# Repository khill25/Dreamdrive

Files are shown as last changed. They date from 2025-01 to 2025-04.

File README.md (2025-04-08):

# Dreamdrive
Retro gaming accessories produced by Dreamcraft Industries. Dreamdrive is coming to disc based systems called Dreamdisc! Dreamcast is the first console to get this treatment. Work is in progress to finalize the hardware and software for a first producion run. Stay tuned!

## [Discord](https://discord.gg/sHbhx2qJuK)
Join the discussion and get the latest on Dreamdrive status. Chat with other hackers. Have ideas on a new Dreamdrive product? Come and let me know. 

# Dreamdumper64
New Dreamdumper64 hardware files have been checked in! Navigate to `N64/hw/cart_tester/pc64` for the latest kicad project files.

# Projects
Current project status

| Project | Platform | Purpose  | Status | Notes |
| --- | --- | --- | --- | --- |
| Dreamdumper64 | N64 | Backup your cartridges | Finished | Completed units are available [here](https://dreamcraftindustries.com/products/dreamdumper64-assembled)!|
| Dreamdisc | Dreamcast | Dreamdive ODE For Dreamcast | Prototype/v3 | Repo files wont boot yet but the design has been verified and will be available soon |
| Dreamdrive Advance | GBA | Developer rom cart | Prototype/v2 | Waiting for new board designs with support for faster psram. Current PSRAM on the qspi bus isn't fast enough to service the cart |
| Super Dreamdrive | SNES | Developer rom cart | Prototype/v1 | Drafted prototype hardware and software. No idea if this is working |

### License
This project is licensed under the [Dreamdrive Open Hardware License v1.0](./LICENSE).  
You are free to learn from, modify, and remix this design for non-commercial purposes with attribution.  
Commercial use requires permission — reach out to kaili [at] dreamcraftindustries [dot] com.

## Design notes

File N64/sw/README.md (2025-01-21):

# Notes
Changes have been made to the pico-sdk to speed up copy to ram in order to meet the boot timing when powered on from the n64.
`crt0.S` should be copied to `pico-sdk/source/rp2_common/pico_standard_link/crt0.S` Remember to back up the original before making any changes.

To build and flash:

```bash

# First of all, don't forget to update submodules
git submodule update --init

# If you have more than 2MB flash, you need to change the SDK file src/rp2_common/pico_standard_link/memmap_copy_to_ram.ld (for now!):
# Change to: `FLASH(rx) : ORIGIN = 0x10000000, LENGTH = 16384k`

cd sw

# Load a rom into sw/picocart64/rom.h
# `--compress` will compress the rom with a simple compression scheme.
./scripts/load_rom.py --compress my_rom.z64

mkdir build
cd build

# Configure cmake. To use NTSC, set -DREGION=NTSC
# If you have more than 2MB flash, you need to change the flash size by adding -DFLASH_SIZE_MB={one of 2,4,8,16} here.

For European N64s
`cmake -DREGION=PAL ..`
    * If using a weact pico clone (e.g. purchased from dreamcraftindustries.com)
    `cmake -DREGION=PAL -DFLASH_SIZE_MB=16`

For North American N64s
`cmake -DREGION=NTSC ..`
    * If using a weact pico clone (e.g. purchased from dreamcraftindustries.com)
    `cmake -DREGION=NTSC -DFLASH_SIZE_MB=16`

# Build
make

# You can now flash it by holding down the BOOT button and resetting the device, then mounting the usb mass storage device, then copy the file picocart64/picocart64.uf2 to the mounted path and run `sync`.

# Alternatively, you can use openocd with a J-Link:

# Requires https://github.com/raspberrypi/openocd
# AUR package if you're on archlinux: https://aur.archlinux.org/packages/openocd-raspberrypi-git
openocd -f interface/jlink.cfg -c "transport select swd; adapter_khz 1000" -f target/rp2040.cfg -c "program ./picocart64/picocart64.elf verify reset exit"

# Note! You *have* to power reset the pico after flashing it with a jlink, otherwise multicore doesn't work properly.
# Alternatively, attach a debugger, `mon reset halt`, `c`, does the trick as well. It seems that openocd's `reset run` doesn't work properly.

```

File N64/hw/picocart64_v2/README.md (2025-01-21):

# PicoCart64 v2.2

:exclamation: Latest 2.2 board revisions have been ordered for testing, so build at your own risk :exclamation:

## Errata

### v2.0
- Less than ideal VBus' routing on Inner Layer 1. The power routing should work and passes DRC, but could be better.

## Changelog

### v2.2
- Improved routing
- Removed mcu1 USB-C port
- CS line of all chips in PSRAM array are routed through the demux
- Removed play area
- Added reset button pads connected to mcu2 reset pins for easy reset

### v2.1-unreleased
- Improved power routing for VBus'

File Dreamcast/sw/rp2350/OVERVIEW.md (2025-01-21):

MCU1 -
D0-D15 = gpio 0-15
SDCLK = 16
SDCMD = 17
SD_D0 = 18
SD_D1 = 19
SD_D2 = 20
SD_D3 = 21
PIO_COMMS_CTRL1 = 22
PIO_COMMS_CTRL2 = 24
PIO_COMMS_D0 = 26
PIO_COMMS_D1 = 27
PIO_COMMS_D2 = 28
PIO_COMMS_D3 = 29

MCU2 -
A0-A2 = gpio 0-2
IDE_CS0 = 3
IDE_CS1 = 4
RD = 5
WR = 6
IORDY = 7
INTRQ = 8
CDLRCK = 9
CD_CLK = 10
CD_EMPH = 11
DMARQ = 12
DMACK = 13
CD_SDAT = 14
CD_BCK = 15
UART_TX = 16
UART_RX = 17
(18,19,20,21) = free
PIO_COMMS_CTRL1 = 22
PIO_COMMS_CTRL2 = 24
PIO_COMMS_D0 = 26
PIO_COMMS_D1 = 27
PIO_COMMS_D2 = 28
PIO_COMMS_D3 = 29

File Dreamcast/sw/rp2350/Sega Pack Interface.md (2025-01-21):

# Sega Packet Interface 
Repackaged and in some places condensed, version of the `GD-ROM Protocol SPI Specifications` document.
## Signal lines

| Line  |   Name    | Description |
--------|-----------|-------------|
| CS0 |   chip select 0   |   serves for selecting the command block register. Aka 'CS1FX' |
CS1 |   chip select 1   |   serves for selecting the control block register. Aka 'CS3FX'
DA2, DA1, DA0   |   Device address  |   specifies the register and data read/write port
DASP    |   Device active, device 1 present |   Time multiplexed singla which indicates whether the device is active and whether device 1 is present. The signal in this line is an open collector signal. However, the signal cannot be used by the host.
DD0-DD15    |   Device data |   Bidirectional data bus, either 8-bit or 16-bit bus. The 8-bit LSB is used for 8-bit transfer (register etc.)
DIOR    |   Device I/O read |   Read strobe signal from the host. At the falling edge of this signal, the data on the DD0-DD7, DD8-DD15 data bus from the device register or data port become valid. At the rising edge of this signal, the host latches on to the data. Until latching is completed, the host cannot access the data.
DIOW    |   Device I/O write    |   Write strobe signal from the host. At the falling edge of this signal, the data on the DD0- DD7, DD8-DD15 data bus from the device register or data port are latched. Until latching is completed, the device cannot access the data.
DMACK   |   DMA acknowledge (optional)  |   This signal is used by the host in response to DMARQ, for initiating a DMA transfer.
DMARQ   |   DMA request (optional)  |   This signal is used for DMA transfer between the host and this device. When data transfer is possible, the device drives the signal. The data transfer direction is controlled by the DIOR- and DIOW- commands. This signal is used in handshaking with the DMACK- signal. When no device is selected and when no DMA commands are being executed, the signal line is always in the high- impedance (release) state. When DMA transfer is being carried out, the signal is driven by the device.
INTRQ   |   Device interrupt    |   Serves for issuing an interrupt to the host. The INTRQ signal has a hold function which asserts the interrupt only when the device is selected and the host has cleared the nIEN bit in the device control register. When the nIEN bit is "1", or when the device is not selected, the INTRQ signal is in the high-impedance state, regardless of the presence of the hold interrupt. In the interrupt hold state, the following OR conditions are cleared. <ul><li>RESET signal assertion</li><li>Device control register SRSRT bit reset</li><li>When host has written to command register</li><li>When host has read from command register</li></ul> For PIO transfer, the INTRQ signal is asserted at the start of each transferred data. The data block is normally a single sector, unless declared otherwise by a separate method. For DMA transfer, the INTRQ signal is asserted only once, after the command has terminated.
IOCS16  |   Device 16-bit I/O   |   For PIO transfer in mode 0, 1, or 2, the IOCS16- signal indicates that the 16-bit data port is already addressed and that the device can send and receive 16-bit data. This is an open collector output.<ul><li>In any PIO mode, the device supports only 16-bit data transfer. Therefore the IOCS16- signal is always asserted.</li><li>During DMA mode transfer, the host uses the 16-bit DMA channel and the IOCS16- signal is not asserted.</li></ul> However, the signal cannot be used by the host.
IORDY   |   I/O channel ready   | When the device cannot comply with a data transfer request, the signal is negated in order to expand the register access host transfer cycles. <ul><li>When this signal is driven, it is valid only during the DIOR/DIOW cycle for the selected device.</li><li> When the IORDY signal is not negated, it is in the high-impedance state, because it is an open collector signal.</li></ul>
RESET   |   Device reset    |   This signal is issued by the host. It is asserted at the start of power-on, and the assert state is maintained until the power supply level has stabilized. This is a tolerance interval until device reset after power-on
MCK |   Main clock  |    33.8688 MHz clock signal for AICA use.
BCLK    |   Bit clock   |   Clock signal for fetching Digital Audio.
LRCK    |   Left right clock    |   Digital Audio left/right discriminat signal.
SDTATA  |   Serial Data |   Digital Audio data
EMPH    |   Emphasis    |   <ul><li>A High output signal is obtainable if preemphasis is applied to Digital Audio during playback or scan playback. Should there be irregularities in the subcode Q data during playback, the value of the previous time is retained and output. </li><li>Low is output when power is turned ON, when reset, when playback is stopped, when the lid is open and when no disc is inserted.</li></ul>
---

## Command Transfer Mechanism
### Reset Conditons
These are listed in priority order. With **Power-on Reset** being higher than **SPI Soft Reset**, etc... **ATA SRST** has priority over all other states except these.
* **Power-on reset or hardware reset**
    * In the same way as executing the master/slave diagnosis protocol, the electrical circuit diagnosis is executed and the default values are established.
    1) All currently executing commands and I/O operations are cleared.
    2) The device is reset to default condition.
    3) As after normal power-on reset, the operation mode of the device returns to a suitable initial state.
    4) The task file register is initialized:
        * `Status   = 0x00`
        * `Error = 0x10`
        * `Sector Count = 0x01`
        * `Sector Number = 0x01`
        * `Cylinder Low = 0x14`
        * `Cylinder High = 0xEB`
        * `Drive/Head = 0x00`
        * `BSY = 0` following after any reset indicates that the task file register is already initalized for the host.
* **SPI Soft Reset**
    * When the SPI device receives a SPI Soft Reset command, the interface circuit is reset to an interface that operates with the characteristics requested by Set Features.
    * Must be able to return the MCU from a busy or hung-up state so commands can be performed.
    * Can be issued when the `BSY` bit is 1
    1) The BUSY state is set. When the reset sequence in the device is completed, the BUSY state is also cleared. This is the only status that is reported to the host during an SPI Software Reset.
    2) The same information sequence as after power-on reset is performed and the task file is initialized. As an exception, the DRV bit remains unchanged.
* **ATA SRST**
    * The device normally supplies the ATA PDIAG/DASP sequence and executes the task file associated with the command when SRST is detected. This does not cause an actual device reset. There are no startup, abort, or stop commands.

### ATA I/O Register
* Communication between the device and the host occurs via the I/O register selected by the code data on the signal from the host (`CS0`, `CS1`, `DA2`, `DA1`, `DA0`, `DIOR`, `DIOW`)
* Except for the data register, all registers are read/written in 8-bits (byte units)
* The data register is always accessed in 16-bit words.

#### Function Select Table
This table represents which registers are read or written based on the CS, Address, and Read/Write lines. Data is valid on falling edge of `READ`/`WRITE`. There is 100-300ns of time to sample the pins before the data becomes valid on the next rising edge.

|CS0|CS1| A2 | A1 | A0 | READ | WRITE |
---|---|---|---|---|---|---|
1|0|1|1|0|`Alternate Status Register`|`Device Control Register`|
0|1|0|0|0|`Data Register`| `Data Register`|
0|1|0|0|1|`Error Register`|`Features Register`|
0|1|0|1|0|`Interrupt Reason Register`|!!NOT USED!!|
0|1|0|1|1|`Sector Number Register`|!!NOTE USED!!|
0|1|1|0|0|`Byte Count Register (0-7)`|`Byte Count Register (0-7)`|
0|1|1|0|1|`Byte Count Register (8-15)`|`Byte Count Register (8-15)`|
0|1|1|1|0|`Drive Select Register`|`Drive Select Register`|
0|1|1|1|1|`Status Register`|`Command Register`|
1|1|x|x|x|INVALID ADDRESS|INVALID ADDRESS|

** ~~There seems to be an error in the GM-ROM Protocol SPI Specifications PDF I was reading to create this doc. I have fixed this table with information based on findings from a logic analyzer and analyzing the iceGDROM verilog.It ~~

*** It isn't wrong, it's just that the CS, Read, and Write lines are all active LOW

****These pins are also know as: `CS1` = CS3FX, `CS0` = CS1FX, `READ` = DIOR, `WRITE` = DIOW

---

#### Status Register
<ul>

| 7 | 6 | 5 | 4 | 3 | 2 | 1 | 0 |
---|---|---|---|---|---|---|---|
BSY | DRDY | DF | DSC | DRQ | CORR | Reserved | CHECK |

<li>
This register indicates the drive status. When the register is read, any pending interrupt signal is cleared. 
</li>
<li>
When bit 7 (BSY) is "0", the other bits are also valid and the command block can be accessed. 
</li>
<li>
When the bit is "1", the other bits are invalid and the command block cannot be accessed. However, in the case of special commands (NOP, Soft Reset command, etc.) access to the command block is enabled even when this bit is "1".
</li>
<li>
Bit 7 (BSY) becomes valid 400 ns after a command is received.
</li>
</ul>

* Bit 7: `BSY` is always set to 1 when the drive accessess the command block.
* Bit 6: `DRDY` set to 1 when the drive is able to respond to an ATA command.
* Bit 5: `DF` Returns drive fault information.
* Bit 4: `DSC` Becomes 1 when seek processing is complete.
* Bit 3: `DRQ` Becomes 1 when preparations for data transfer between drive and host are completed. 
    * Information held in the Interrupt Reason Register becomes valid in the packet command when DRQ is set.
* Bit 2: `CORR` Indicates a correctable error has occured.
* Bit 1: RESERVED
* Bit 0: `CHECK` Becomes 1 when an error has occured during execution of the command the previous time. 
    * Error detauls can be determined by checking the sense key and error code.

---
#### Alternate Status Register
* This register is the same as the status register, but it does not clear DMA status information when it is accessed.

| 7 | 6 | 5 | 4 | 3 | 2 | 1 | 0 |
---|---|---|---|---|---|---|---|
BSY | DRDY | DF | DSC | DRQ | CORR | Reserved | CHECK |

#### Command Register
Commands from the host are set in this register. For information on the meaning of commands, refer to the Table 3.3. TODO - fill out relevant info from referenced table in this section

#### Byte Count Register
* This register serves for controlling the number of bytes sent from the host in response to the DRQ commands.
* It is used only in PIO mode. 
* In DMA mode, the Byte Count Register contents are disregarded. 
* The register is set before a packet command is issued. The register determines the total transfer amount of the data sent in response to one data group transfer command (REC_MODE/SET_MODE, REQ_STAT, etc.).
* For commands which require several DRQ interrupts (CD_READ, CD_READ2, etc.), the expected data length is set in this register.
* When any data are to be transferred, the device sets the number of bytes to be transferred by the host in the Byte Count Register and then issues the DRQ interrupt. 
* The contents of the register do not change unless at least one word or more is transferred from the data register.

---
#### Data Register
* This register is used for reading and writing during data transfer with the host. 
* The register is switchable between 8 and 16 bits. 
* Only 16-bit mode is supported because the host is not using the IOCS-16 signal.

---
#### Device Control Register
Bit 2 (SRST) of this register is the reset switch from the host, but it is not used in the current protocol. When wishing to perform a software reset, use the "Software Reset" command as defined in the SPI protocol. Bit 1 (nIEN) determines whether the host interrupt is made valid or not.

| 7 | 6 | 5 | 4 | 3 | 2 | 1 | 0 |
---|---|---|---|---|---|---|---|
Reserved | | | | 1 | SRST | nIEN | 0 |

* Bit 2 `SRST` Software reset from host. 
    * Default is 0
    * Reset is performed when set to "1"
    * NOTE: because this is not used in this protocol use the "SPI Software Reset" command defined in SPI for performing a software reset
* Bit 1 `nIEN` Sets the interrupt for the host.
    * Default is 0
    * Invalid can be selected by setting this to 1

---
#### Drive Select Register (ATA Drive/Head select register)
| 7 | 6 | 5 | 4 | 3 | 2 | 1 | 0 |
---|---|---|---|---|---|---|---|
1 | Reserved | 1 | 0 | LUN | | | |

* Bit 0-3 `LUN` Logical unit number to which the command is applied
* This parameter is optional and reserved for future use ( lol :joy: )
---

#### Error Register
* The completion status of the most recent command is set in this register, also at the end of hard disk diagnosis. 
* When the status register bit 0 is "1", an error has occurred, and the error content is set in this register.

| 7 | 6 | 5 | 4 | 3 | 2 | 1 | 0 |
---|---|---|---|---|---|---|---|
Sense Key |  |  |  | MCR | ABRT | EMOF | ILI |

* Bits 7-4 `Sense Key`
    * `Sense Key` is only reflected in the SPI Command Mode. Same is true for Additional Sense Code (`ASC`) and Additional Sense Code Qualifier (`ASCQ`)
* Bit 3 `MCR` Media change was requested and media have been ejected (ATA level)
* Bit 2 `ABRT` Drive is not ready and command was made invalid (ATA level)
* Bit 1 `EOM` Media end was detected (option) (is option, optional?)
* Bit 0 `ILI` Command length is not correct (option)
---

#### Features Register
This register normally specifies the data transfer mode, but it can also be used for Set Features parameters of the ATA command. When issuing commands accompanied by data transfer, such as CD_READ, specify in this register whether data should be transferred by PIO or DMA at the time of task file initialization.

**Normal use (specify data transfer mode)**
| 7 | 6 | 5 | 4 | 3 | 2 | 1 | 0 |
---|---|---|---|---|---|---|---|
Reserve |  |  |  |  |  |  | DMA |

* Bit 0 `DMA` Send data for command in DMA mode

**Use as parameter for Set Features command** 
| 7 | 6 | 5 | 4 | 3 | 2 | 1 | 0 |
---|---|---|---|---|---|---|---|
Set(1), Clear(0), Feature | Feature Number | | | |  |  | |
* Bit 6-0 `Feature Number` Set transfer mode by setting to `3`
    * By writing `3` as `Feature Number` and issuing the `Set Feature` command, the PIO or DMA transfer mode set in the `Sector Count` register can be selected.
    * The actual transfer mode is specified by the `Sector Count Register`

---
#### Interrupt Reason Register (Read Only)
| 7 | 6 | 5 | 4 | 3 | 2 | 1 | 0 |
---|---|---|---|---|---|---|---|
Reserved | | | | |  | IO | CoD |
* Bit 0 `COD` (Command or Data)
    * 0 indicates data
    * 1 indicates command

| IO    |   DRQ |   CoD | Function
---|---|---|---|
0   |   1   |   1   | Command packet can be received
1   |   1   |   1   | Message can be sent from device to host
1   |   1   |   0   | Data can be sent to host
0   |   1   |   0   | Data can be received from host
1   |   0   |   1   | Status register contains completion status

---
#### Sector Count Register (Write Only)
* This register is used in combination with the ATA command's `Set Features` command

| 7 | 6 | 5 | 4 | 3 | 2 | 1 | 0 |
---|---|---|---|---|---|---|---|
Transfer Mode | | | | Mode Value | | | |

| Value | Transfer Mode |
---|---|
00000 00x | PIO Default Transfer Mode
00001 xxx | PIO Flow Control Transfer Mode x
00010 xxx | Single Word DMA mode x 
00100 xxx | Multi-Word DMA
00011 xxx | Reserved (For Pseudo DMA mode)

---
#### Sector Number Register (ATA Sector Number Register)
| 7 | 6 | 5 | 4 | 3 | 2 | 1 | 0 |
---|---|---|---|---|---|---|---|
Disc Format | | | | Status | | | |

The information obtained by this register is the same as the status data obtained with the REQ_STAT command.

* `Disc Format` becomes valid after the lid is closed and the `UNIT ATTENTION` state is entered via the `NOT READY` state, or after the `BSY` bit becomes "0" following Soft Reset.
* `Status` becomes valid after the power is turned ON and the `UNIT ATTENTION` state is entered via the `NOT READY` state, or after the `BSY` bit becomes "0" following Soft Reset.
* The values of this register are invalid during issue of a command and during execution of a command.
* The modification timing of this register and the status modification timing caused by `REQ_STAT` coincide internally but depending on the timing of the read out of the `Sector Number Register` and the issue of the `REQ_STAT` command there may be times where they do not coincide.
* This register is updated unsyncronized with the host. For this reason, it may return unfixed value if it is read at the timing of updating GD drive side. To avoid this, either read it again to confirm value or use `REQ_STAT` command instead of this register.
    * TODO: Refernce section of manual to build useful table... For details on the `Disc Format` and `Status`, refer to the sections on GD Drive State Transition and `REQ_STAT`.
* Operation of this register differs from ATA specifications.

### Sense Key Definitions
| Sense key | Description |
|---|---|
`0x00` | No sense key information (`NO SENSE`). Indicates that no sense key information is present. This also applies when command execution was successful.
`0x01` | Recovered error (`RECOVERED ERROR`). The last command has performed successful error recovery processing. Details can be obtained by checking the additional sense byte and the information field. If several error processing operations were performed for one command, the device reports the status of the last error processing operation.
`0x02` | Not ready (`NOT READY`). Indicates that the device cannot be accessed.
`0x03` | Media error (`MEDIUM ERROR`). Indicates that the command was terminated unsuccessfully due to a non-recoverable media defect or an error during reading or writing. This sense key may also returned by the device when it is not possible to distinguish between a media defect and a hardware defect (sense key 4).
`0x04` | Hardware error (`HARDWARE ERROR`). During operation or self- diagnosis, an unrecoverable hardware error was detected (for example a controller failure, device failure, parity error etc.).
`0x05` | Illegal request (`ILLEGAL REQUEST`). An illegal parameter was included in the command packet or in additional data for commands. When the device detects an illegal parameter in a command packet, it terminates the command without changing the media. When the device detects an illegal parameter in additional data for commands, the device may already have altered the media. When this sense key is reported, the command is not yet executed.
`0x06` | Unit attention (`UNIT ATTENTION`). Indicates that removable media may have been replaced, or that the device was reset.
`0x07` | Data protect (`DATA PROTECT`). Indicates that a write attempt was made on a protected block.
`0x08`-`0x0A` | Reserved
`0x0B` | Aborted command (`ABORTED COMMAND`). Indicates that the device has aborted the command. Recovery may be possible by re-executing the command.
`0x0C`-`0x0F` | Reserved
---

## ATA Command Flow
#### Command for PIO data transfer to host
* Applies to `Identify Device` command
* Command is accompanied by transfer of one or multiple data blocks from the device to the host

1) Host waits for `BSY` bit to become `0` in `Status Register` or `Alternate Status Register`
2) Host writes params for the command to relevant registers:
    * `Features Register`, `Sector Count Register`, `Sector Number Register`, `Cylinder High Register`, `Cylinder Low Register`, `Device/Head Register`
3) Host writes the command code to the `Command Register`
4) Device sets `BSY` bit to `1` and prepares to send the first data block.
5) Device sets `DRQ` bit and asserts `INTRQ` when data block is ready
    * `DRQ` is optional for some error conditions
    * If an error occurs, the device sets the corresponding status and error bits
    * If `BSY` bit transitions are too fast, the host may not notice
6) Host reads and saves `Status Register` after detecting `INTRQ` or `BSY` bit becoming `0` in the `Alternate Status Register`
7) If the `DRQ` bit is set, host reads one data block from `Data Register`. 
    * Illegal transfer if an error occurs in the next ste (step 8)
8) After the `Status Register` is read out 
    * Device negates `INTRQ`
    * Executes one of the following based on the status read-out:
        * If no errors and more blocks needed, set `BSY` bit and repeat step 7
        * If an error occurred during this step, clear `DRQ` bit and complete command execution
        * If the final block is transferred, clear `DRQ` bit and complete command execution

---

#### Non-data Command Flow
Applies to:
* `NOP`
* `Soft Reset`
* `Execute Device Diagnostic`
* `Set Features`
1) Host polls the `Status Register` or `Alternate Status Register` until `BSY` bit becomes `0`
2) Host writes params for the command to relevant registers
3) Host writes the command code to `Command Register`
4) Device sets `BSY` bit to `1` and executes command.
    * If an error occurs during execution the device sets an appropriate status and error bit
5) When command execution is complete device asserts `INTRQ` and clears the `BSY` bit.

---

#### ATA Command (Task File Command)
When a command is issued from the host, the device should:
* Load the command in a suitable register in the command block
* write the command code to the `Command Register`
* Device must set the `BSY` bit within 400ns.

|Command|Code|
|---|---|
|`Soft Reset`| `0x08`|
|`Execute Device Diagnostic`| `0x90`|
|`NOP`| `0x00`|
|`Packet Command`| `0xA0`|
|`Identify Device`| `0xA1`|
|`Set Features`| `0xEF`|

<ul>
<li><code>Soft Reset</code> Executes a software reset of the device. This command can also be received when `BSY` bit = `1`
</li>
<li><code>Execute Drive Diagnostic</code> Initiates self-diagnostic routine of the device.
    <ul>
        <li> Device reports the result of the self-diagnostic routine </li>
        <li> The device clears the `BSY` bit and issues an interrupt </li>
        <li> Error code is an 8-bit value written to the error register</li>
        <li>
        <table>
            <tbody>
                <tr>
                <th>Error Code</th>
                <th>Description</th>
                </tr>
                <tr>
                    <td><code>0x01</td>
                    <td>Normal</td>
                </tr>
                <tr>
                    <td><code>0x03</td>
                    <td>Data buffer error</td>
                </tr>
                <tr>
                    <td><code>0x04</td>
                    <td>ODC error</td>
                </tr>
                <tr>
                    <td><code>0x05</td>
                    <td>CPU error</td>
                </tr>
                <tr>
                    <td><code>0x06</td>
                    <td>DSC error</td>
                </tr>
                <tr>
                    <td><code>0x07</td>
                    <td>Other error</td>
                </tr>
                </tbody>
            </table>
        </li>
    </ul>
</ul>

* `Set Features`
    * For the GD-ROM, only the transfer mode settings are supported
    * This setting can be made individually for `DMA` mode and `PIO` mode
    1) Set `3` in the `Set` bit of the `Feature Register` and `Feature Number`
    2) In the `Sector Count Register`
        * Specify the transfer mode in the upper 5 bits 
        * Mode number in the lower 3 bits
    3) Execute the `Set Features` command

* `NOP`
    * Device status access for hosts with 16-bit registers (?? Does the Dreamcast support 16-bit registers ??)
    * Command can be received when `BSY` bit is `1` and device should terminate the command currently in execution
        * If the termination is performed correctly only the termination interrupt of this command is returned.
    * The device responds to commands that are not recognized by the following:
        * Setting "abort" in the error register
        * Setting an error in the status register
        * Clearing "busy" in the status register
        * Asserting the `INTRQ` signal

* `Packet Command`
    * TODO see SPI Packet Command section

* `Identify Device`
    * Always conducted in PIO Mode
    <ul>
    <li>
    <table>
        <tbody>
            <tr>
            <th>Byte</th>
            <th>Content</th>
            </tr>
            <tr>
                <td><code>0</td>
                <td>Manufacturer ID</td>
            </tr>
            <tr>
                <td><code>1</td>
                <td>Model ID</td>
            </tr>
            <tr>
                <td><code>2</td>
                <td>Version ID</td>
            </tr>
            <tr>
                <td><code>0x3-0xF</td>
                <td>Reserved</td>
            </tr>
            <tr>
                <td><code>0x10-0x1F</td>
                <td>Manufacturer name (16 ASCII characters)</td>
            </tr>
            <tr>
                <td><code>0x20-0x2F</td>
                <td>Model name (16 ASCII characters)</td>
            </tr>
            <tr>
                <td><code>0x30-0x3F</td>
                <td>Firmware version (16 ASCII characters)</td>
            </tr>
            <tr>
                <td><code>0x40-0x4F</td>
                <td>Reserved</td>
            </tr>
            </tbody>
        </table>
    </li>
    </ul>

---
### SPI Packet Commands
|Command|Function|OP Code|
---|---|---|
|`TEST_UNIT`|Verify access readiness|`0x00`|
|`REQ_STAT`|Get CD Status|`0x10`|
|`REQ_MODE`|Get various settings|`0x11`|
|`SET_MODE`|Make various settings|`0x12`|
|`REQ_ERROR`|Get error details|`0x13`|
|`GET_TOC`|Get all `TOC` data|`0x14`|
|`REQ_SES`|Get specified session data|`0x15`|
|`CD_OPEN`|Open tray|`0x16`|
|`CD_PLAY`|Play CD|`0x20`|
|`CD_SEEK`|Seek for playback position|`0x21`|
|`CD_SCAN`|Perform scan|`0x22`|
|`CD_READ`|Read CD|`0x30`|
|`CD_READ2`|CD read (pre-read position)|`0x31`|
|`GET_SCD`|Get subcode|`0x40`|

#### Command Packet Format
|Bit|7|6|5|4|3|2|1|0|
|---|---|---|---|---|---|---|---|---|
|Byte|||||||||
|0|Command Code||||||||
|1|Command parameter||||||||
|2|Command parameter||||||||
|3|Command parameter||||||||
|4|Command parameter||||||||
|5|Command parameter||||||||
|6|Command parameter||||||||
|7|Command parameter||||||||
|8|Command parameter||||||||
|9|Command parameter||||||||
|10|Command parameter||||||||
|11|Command parameter||||||||
* **Command code**
    * The codes allotted to the various commands required to control the devices
* **Command parameter**
    * `Transfer Length`
        * Data length to be transfer
        * Typically represents the block count
        * For some commands it represents the byte count
        * For commands with multiple byte transfers, the transfer length `0` indicates no transfer
    * `Allocation Length`
        * Max length of data that host can receive
        * `0` indicates no transfer
    * `Starting Address`
        * Position to start data transfer
        * Some cases it may indicate transfer starting address

----
#### SPI Command Flow Sequence

---
#### CD Drive

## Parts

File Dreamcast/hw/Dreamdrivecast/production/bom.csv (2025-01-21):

Designator | Footprint | Quantity | Value | LCSC Part #
C1, C13, C14, C15, C16, C17, C18, C19, C20, C21, C24, C4, C5, C6, C7, C8 | 0402 | 16 | 100n | C1525
C10, C22, C23, C9 | 0402 | 4 | 1u | C14445
C11, C12 | 0402 | 2 | 10u | C315248
C25, C26, C27, C28 | 0402 | 4 | 12p | C106201
CN1 | Molex_52602_0579 | 1 | Molex_52602_0579 | C588209
J3, J4 | USB_C_Receptacle_Palconn_UTC16-G | 2 | USB_C_Receptacle_USB2.0 | C2988369
J5 | microSD_HC_Molex_104031-0811 | 1 | Micro_SD_Card | C585350
MCU1 Boot_2, MCU1 Boot, MCU2 Reset | SW_SPST_FSMSM | 3 | MCU1_BOOT | C520860
MCU2 Boot | SW_SPST_FSMSM | 1 | MCU2_BOOT | C520860
R10, R2, R3, R9 | 0402 | 4 | 27.4 | C284479
R11, R12, R4, R5 | 0402 | 4 | 5k1 | C25905
R13, R8 | 0402 | 2 | 100k | C60491
R14, R6 | 0402 | 2 | 10k | C60490
R15, R7 | 0402 | 2 | 1k | C25543
U1 | WQFN-42-1EP_3.5x9mm_P0.5mm_EP2.05x7.55mm | 1 | TS3L501ERUA | C2652454
U2, U5 | QFN-56-1EP_7x7mm_P0.4mm_EP3.2x3.2mm | 2 | RP2040 | C2040
U3 | SOT-223 | 1 | AZ1117-3.3 | C110474
U4, U6 | SOIC-8_5.23x5.23mm_P1.27mm | 2 | W25Q128JVS | C97521
Y1, Y2 | Crystal_SMD_2520-4Pin_2.5x2.0mm | 2 | 12MHz 10ppm | C521567

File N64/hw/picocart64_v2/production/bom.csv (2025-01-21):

Designator | Footprint | Quantity | Value | LCSC Part #
C37 | C_0402_1005Metric | 1 | 100n | C147639
C40 | C_0402_1005Metric | 1 | 1u
R62 | R_0402_1005Metric | 1 | 10K
R33 | R_0402_1005Metric | 1 | 10K
C4 | C_0402_1005Metric | 1 | 100n | C147639
R45 | R_0402_1005Metric | 1 | R | C105637
C3 | C_0402_1005Metric | 1 | 100n
TP1 | TestPoint_Pad_D1.0mm | 1 | TP_MCU2_SCK
R29 | R_0402_1005Metric | 1 | 22R
U7 | SOP-8_3.76x4.96mm_P1.27mm | 1 | APS6404L-3SQR
C5 | C_0402_1005Metric | 1 | 100n
R42 | R_0402_1005Metric | 1 | R | C105637
C32 | C_0402_1005Metric | 1 | 100n | C147639
R17 | R_0402_1005Metric | 1 | 5k1
C16 | C_0402_1005Metric | 1 | 100n | C147639
C28 | C_0402_1005Metric | 1 | 12p
R21 | R_0402_1005Metric | 1 | 22R
C39 | C_0402_1005Metric | 1 | 1u
R37 | R_0402_1005Metric | 1 | 10k
U8 | SOP-8_3.76x4.96mm_P1.27mm | 1 | APS6404L-3SQR
TP2 | TestPoint_Pad_D1.0mm | 1 | TP_MCU2_CS
R24 | R_0402_1005Metric | 1 | 22R
C19 | C_0402_1005Metric | 1 | 100n | C147639
C8 | C_0402_1005Metric | 1 | 100n | C147639
R43 | R_0402_1005Metric | 1 | R | C105637
U1 | SOP-8_3.76x4.96mm_P1.27mm | 1 | APS6404L-3SQR
C54 | C_0402_1005Metric | 1 | 100n | C147639
C10 | C_0603_1608Metric | 1 | 10u
C12 | C_0402_1005Metric | 1 | 12p
D1 | WS2812B-2020 | 1 | WS2812B-2020
U16 | QFN-56_EP_7x7_Pitch0.4mm | 1 | RP2040
JP2 | SolderJumper-2_Small_Closed | 1 | SolderJumper_2_Bridged
C36 | C_0402_1005Metric | 1 | 100n | C147639
R30 | R_0402_1005Metric | 1 | 22R
R54 | R_0402_1005Metric | 1 | R | C105637
U15 | QFN-56_EP_7x7_Pitch0.4mm | 1 | RP2040
C47 | C_0402_1005Metric | 1 | 1u
Y2 | Crystal_SMD_2520-4Pin_2.5x2.0mm | 1 | 12MHz 10ppm | C521567
FB1 | L_0603_1608Metric | 1 | Ferrite
R48 | R_0402_1005Metric | 1 | R | C105637
C38 | C_0402_1005Metric | 1 | 1u
Y1 | Crystal_SMD_2520-4Pin_2.5x2.0mm | 1 | 12MHz 10ppm | C521567
R20 | R_0402_1005Metric | 1 | 22R
U6 | SOP-8_3.76x4.96mm_P1.27mm | 1 | APS6404L-3SQR
U5 | SOP-8_3.76x4.96mm_P1.27mm | 1 | APS6404L-3SQR
R50 | R_0402_1005Metric | 1 | R | C105637
R56 | R_0402_1005Metric | 1 | R | C105637
R2 | R_0402_1005Metric | 1 | 10K
R26 | R_0402_1005Metric | 1 | 22R
J1 | USB_C_Receptacle_GT-USB-7010 | 1 | USB_C_Receptacle_USB2.0
C31 | C_0402_1005Metric | 1 | 100n | C147639
C2 | C_0402_1005Metric | 1 | 100n | C147639
U2 | SOP-8_3.76x4.96mm_P1.27mm | 1 | APS6404L-3SQR
C30 | C_0402_1005Metric | 1 | 100n | C147639
U9 | SOP-16_4.4x10.4mm_P1.27mm | 1 | SN74LVC138AQDRQ1
SW1 | SW_SPST_FSMSM | 1 | BootButton
R41 | R_0402_1005Metric | 1 | 10k
U10 | SOIC-8_5.23x5.23mm_P1.27mm | 1 | W25Q128JVS
R31 | R_0402_1005Metric | 1 | 22R
C9 | C_0402_1005Metric | 1 | 100n | C147639
R10 | R_0402_1005Metric | 1 | 22R
C52 | C_0402_1005Metric | 1 | 100n | C147639
C11 | C_0402_1005Metric | 1 | 12p
J3 | microSD_HC_Molex_104031-0811 | 1 | Micro_SD_Card_Det
U13 | SOT-223 | 1 | AZ1117-3.3
R59 | R_0402_1005Metric | 1 | R | C105637
R5 | R_0402_1005Metric | 1 | 22R
R53 | R_0402_1005Metric | 1 | R | C105637
R15 | R_0402_1005Metric | 1 | 22R
C44 | C_0402_1005Metric | 1 | 1u
C7 | C_0402_1005Metric | 1 | 100n
C18 | C_0402_1005Metric | 1 | 100n | C147639
C24 | C_0402_1005Metric | 1 | 1u
Q2 | SOT-23 | 1 | FDN340P | C347510
R12 | R_0402_1005Metric | 1 | 22R
C41 | C_0402_1005Metric | 1 | 1u
R19 | R_0402_1005Metric | 1 | 10k
TP3 | TestPoint_Pad_D1.0mm | 1 | TP_MCU2_DIO
U11 | SOT-353_SC-70-5 | 1 | 74LVC1G125GW
R6 | R_0402_1005Metric | 1 | 22R
JP1 | SolderJumper-2_Small_Open | 1 | SolderJumper_2_Open
D2 | LED_WS2812B_PLCC4_5.0x5.0mm_P3.2mm | 1 | WS2812B | WS2812B-2020
R44 | R_0402_1005Metric | 1 | R | C105637
C50 | C_0402_1005Metric | 1 | 100n | C147639
C45 | C_0402_1005Metric | 1 | 1u
R25 | R_0402_1005Metric | 1 | 22R
Q1 | SOT-23 | 1 | FDN340P | C347510
R39 | R_0402_1005Metric | 1 | 1K
C57 | C_0402_1005Metric | 1 | 100n | C147639
U17 | ESP32-C3-WROOM-02 | 1 | ESP32-C3-WROOM-02
C51 | C_0402_1005Metric | 1 | 100n | C147639
R4 | R_0402_1005Metric | 1 | 22R
C20 | C_0402_1005Metric | 1 | 100n | C147639
C1 | C_0402_1005Metric | 1 | 100n | C147639
R27 | R_0402_1005Metric | 1 | 22R
C6 | C_0402_1005Metric | 1 | 100n | C147639
R1 | R_0402_1005Metric | 1 | 10K
R58 | R_0402_1005Metric | 1 | R | C105637
C42 | C_0402_1005Metric | 1 | 1u
C13 | C_0603_1608Metric | 1 | 10u
C49 | C_0402_1005Metric | 1 | 100n | C147639
C33 | C_0402_1005Metric | 1 | 100n | C147639
R18 | R_0402_1005Metric | 1 | 5k1
R36 | R_0402_1005Metric | 1 | 22R
C56 | C_0402_1005Metric | 1 | 100n | C147639
C27 | C_0402_1005Metric | 1 | 12p
R13 | R_0402_1005Metric | 1 | 22R
C26 | C_0402_1005Metric | 1 | 100n | C147639
R34 | R_0402_1005Metric | 1 | 10K
R3 | R_0402_1005Metric | 1 | 100k
D3 | SOT-143 | 1 | DRTR5V0U2SR-7 | C443828
R28 | R_0402_1005Metric | 1 | 22R
R47 | R_0402_1005Metric | 1 | R | C105637
C22 | C_0402_1005Metric | 1 | 100n | C147639
R46 | R_0402_1005Metric | 1 | R | C105637
R38 | R_0402_1005Metric | 1 | 10k
R52 | R_0402_1005Metric | 1 | R | C105637
R8 | R_0402_1005Metric | 1 | 22R
C21 | C_0402_1005Metric | 1 | 1u
D4 | D_SMA | 1 | D_Small | C22452
C43 | C_0402_1005Metric | 1 | 1u
U3 | SOP-8_3.76x4.96mm_P1.27mm | 1 | APS6404L-3SQR
C14 | C_0603_1608Metric | 1 | 10u
R51 | R_0402_1005Metric | 1 | R | C105637
R32 | R_0402_1005Metric | 1 | 22R
JP3 | SolderJumper-2_Small_Closed | 1 | SolderJumper_2_Bridged
R61 | R_0402_1005Metric | 1 | R | C105637
C29 | C_0402_1005Metric | 1 | 100n | C147639
R16 | R_0402_1005Metric | 1 | 22R
C35 | C_0402_1005Metric | 1 | 1u
C48 | C_0402_1005Metric | 1 | 100n | C147639
C34 | C_0402_1005Metric | 1 | 100n | C147639
C55 | C_0402_1005Metric | 1 | 100n | C147639
R7 | R_0402_1005Metric | 1 | 22R
C17 | C_0402_1005Metric | 1 | 100n | C147639
R9 | R_0402_1005Metric | 1 | 22R
R49 | R_0402_1005Metric | 1 | R | C105637
R57 | R_0402_1005Metric | 1 | R | C105637
U4 | SOP-8_3.76x4.96mm_P1.27mm | 1 | APS6404L-3SQR
C23 | C_0402_1005Metric | 1 | 100n | C147639
R35 | R_0402_1005Metric | 1 | 22R
R14 | R_0402_1005Metric | 1 | 22R
R60 | R_0402_1005Metric | 1 | R | C105637
R40 | R_0402_1005Metric | 1 | 470R
R22 | R_0402_1005Metric | 1 | 22R
C25 | C_0402_1005Metric | 1 | 1u
C46 | C_0402_1005Metric | 1 | 1u
C53 | C_0402_1005Metric | 1 | 100n | C147639
C15 | C_0402_1005Metric | 1 | 100n | C147639
R11 | R_0402_1005Metric | 1 | 22R
R55 | R_0402_1005Metric | 1 | R | C105637
R23 | R_0402_1005Metric | 1 | 22R
U14 | N64-Connector | 1 | N64-Cartridge
J2 | PinHeader_2x06_P2.54mm_Vertical_SMD | 1 | Conn_02x06_Odd_Even
SW2 | SW_SPST_FSMSM | 1 | ResetButton

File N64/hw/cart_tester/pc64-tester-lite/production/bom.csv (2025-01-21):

Designator | Footprint | Quantity | Value | LCSC Part #
CON3 | N64-CONN | 1 | N64-CONN
H1 | MountingHole_2.2mm_M2_DIN965_Pad_TopBottom | 1 | MountingHole_Pad
SWD1 | PinHeader_1x03_P2.54mm_Vertical | 1 | SWD
UART0 | PinHeader_1x02_P2.54mm_Vertical | 1 | UART0
H4 | MountingHole_2.2mm_M2_DIN965_Pad_TopBottom | 1 | MountingHole_Pad
RESET1 | SW_SPST_FSMSM | 1 | RESET
H3 | MountingHole_2.2mm_M2_DIN965_Pad_TopBottom | 1 | MountingHole_Pad
U1 | RPi_Pico_SMD_TH | 1 | Pico
H2 | MountingHole_2.2mm_M2_DIN965_Pad_TopBottom | 1 | MountingHole_Pad

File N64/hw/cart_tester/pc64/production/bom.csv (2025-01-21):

Designator | Footprint | Quantity | Value | LCSC Part #
C10, C11, C13, C14, C15, C16, C5, C6, C9 | 0402 | 9 | 100nF | C1525
C1001, C1002, C7, C8 | 0402 | 4 | 1uF | C52923
C3, C4 | 0402 | 2 | 30pF | C107004
CON2 | PinSocket_1x03_P2.54mm_Vertical | 1 | HDR1X3 | C146243
CON3 | PinSocket_1x03_P2.54mm_Vertical | 1 | HDR1X3
D1 | 0402 | 1 | PowerLED | C130724
F1 | 1206 | 1 | 1.1A | C2760273
H1, H2, H3, H4 | MountingHole_2.2mm_M2_ISO7380_Pad_TopBottom | 4 | MountingHole_Pad
J1 | HRO-TYPE-C-31-M-12_LCSC | 1 | USB_C_Receptacle_USB2.0 | C165948
J2 | BarrelJack_CUI_PJ-036AH-SMT_Horizontal | 1 | Barrel_Jack
R1, R2 | 0402 | 2 | 5k1 | C25905
R1001 | 0402 | 1 | 1K | C11702
R3, R4 | 0402 | 2 | 27 | C25100
R5 | 0402 | 1 | 35
RP_SW1, RP_SW2 | SW_SPST_TL3342 | 2 | SW_Push | C318884
U1001 | SOT-23-6 | 1 | SRV05-4 | C3021103
U1002 | SOT-223 | 1 | AMS1117-3.3 | C6186
U3 | SOIC-8_5.23x5.23mm_P1.27mm | 1 | W25Q128JVS | C97521
U4 | RP2040-QFN-56 | 1 | RP2040 | C2040
Y1 | Crystal_SMD_3225-4Pin_3.2x2.5mm | 1 | Crystal_GND24 | C9002

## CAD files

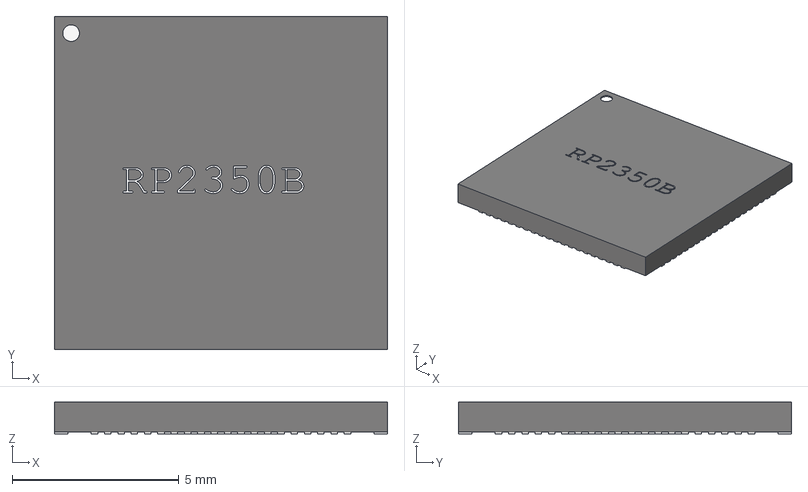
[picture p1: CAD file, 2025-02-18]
Dreamcast/hw/Dreamdrivecast-rp2350/Dreamdrivecast-rp2350/RP2350_QFN80.step
10.0 x 10.0 x 0.95 mm

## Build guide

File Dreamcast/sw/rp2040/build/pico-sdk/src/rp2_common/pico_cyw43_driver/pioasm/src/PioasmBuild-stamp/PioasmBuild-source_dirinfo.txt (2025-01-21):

# This is a generated file and its contents are an internal implementation detail.
# The download step will be re-executed if anything in this file changes.
# No other meaning or use of this file is supported.

method=source_dir
command=
source_dir=/Users/kaili/Code/pico-sdk/tools/pioasm
work_dir=

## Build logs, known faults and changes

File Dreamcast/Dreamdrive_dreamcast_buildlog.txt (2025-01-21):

Finding a copy of the "GD-ROM protocol SPI specification design" doc mentioned in the Dreamcast Hardware spec. I managed to track down a copy on archive.org.

I originally found just a text version on archive.org but was able to get the original PDF version, with tables intact. Was really difficult to figure out a protocol spec without columns and the data spaced all over.

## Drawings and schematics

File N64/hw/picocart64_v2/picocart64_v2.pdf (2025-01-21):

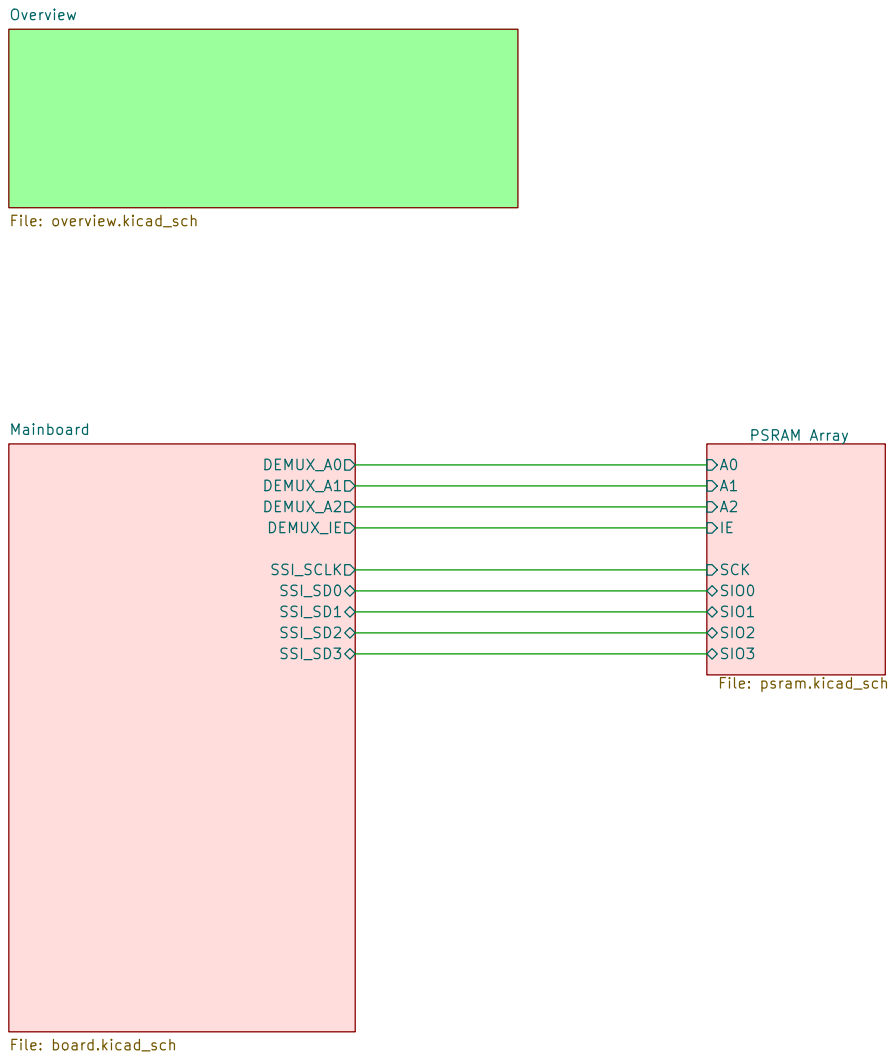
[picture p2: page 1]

File: picocart64_v2.kicad_sch Sheet: / Konrad Beckmann

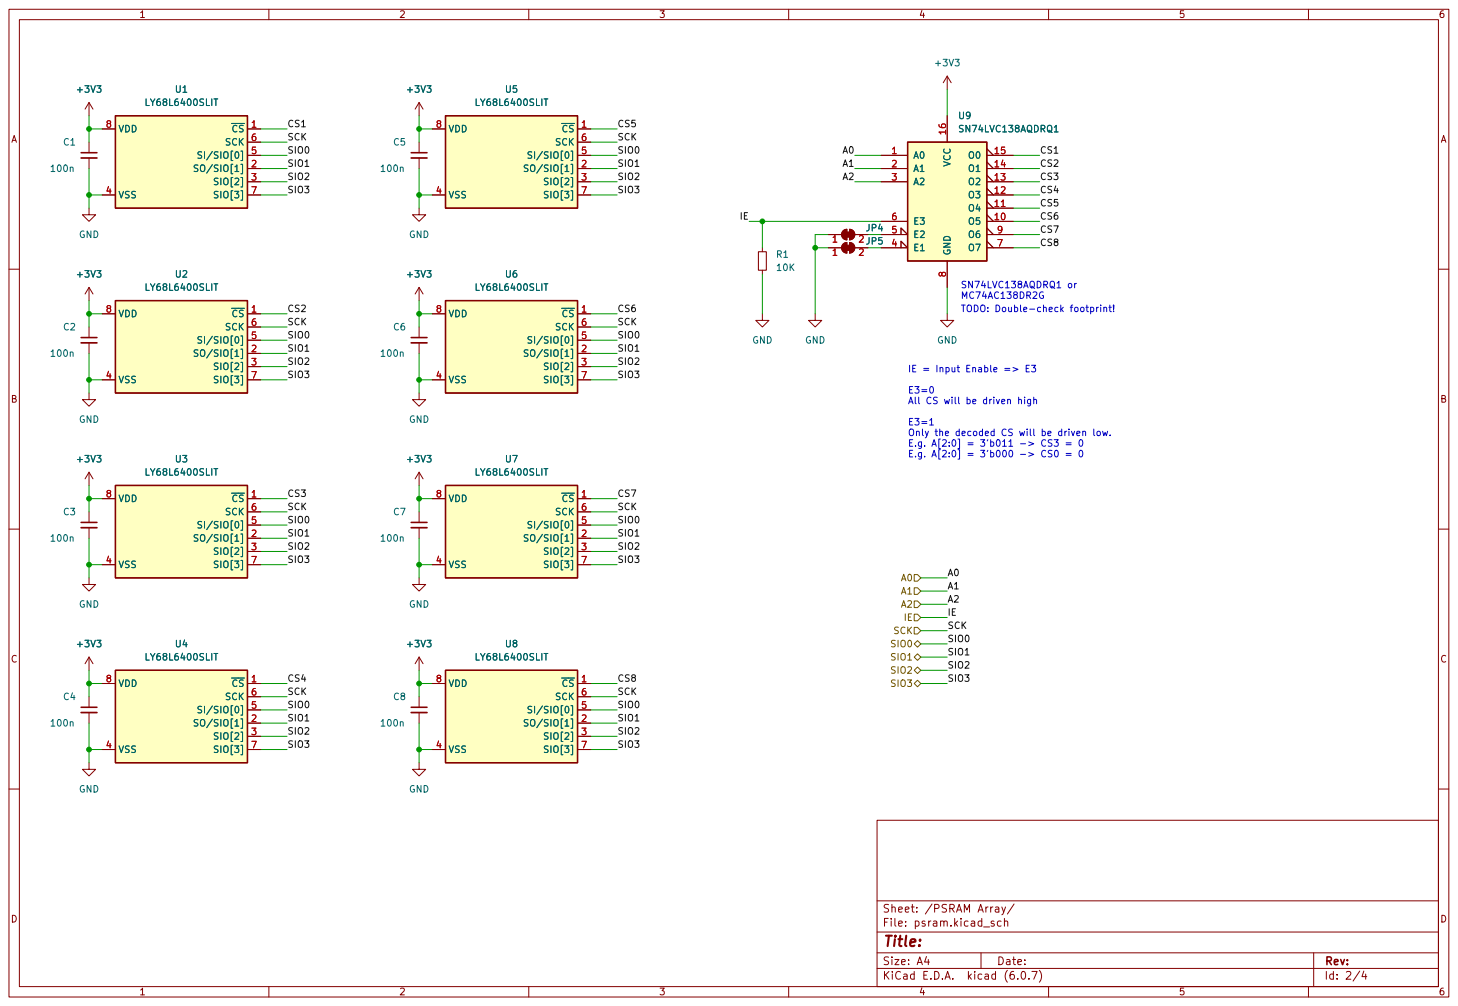
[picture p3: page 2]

IE = Input Enable => E3 E3=0 All CS will be driven high E3=1 Only the decoded CS will be driven low.

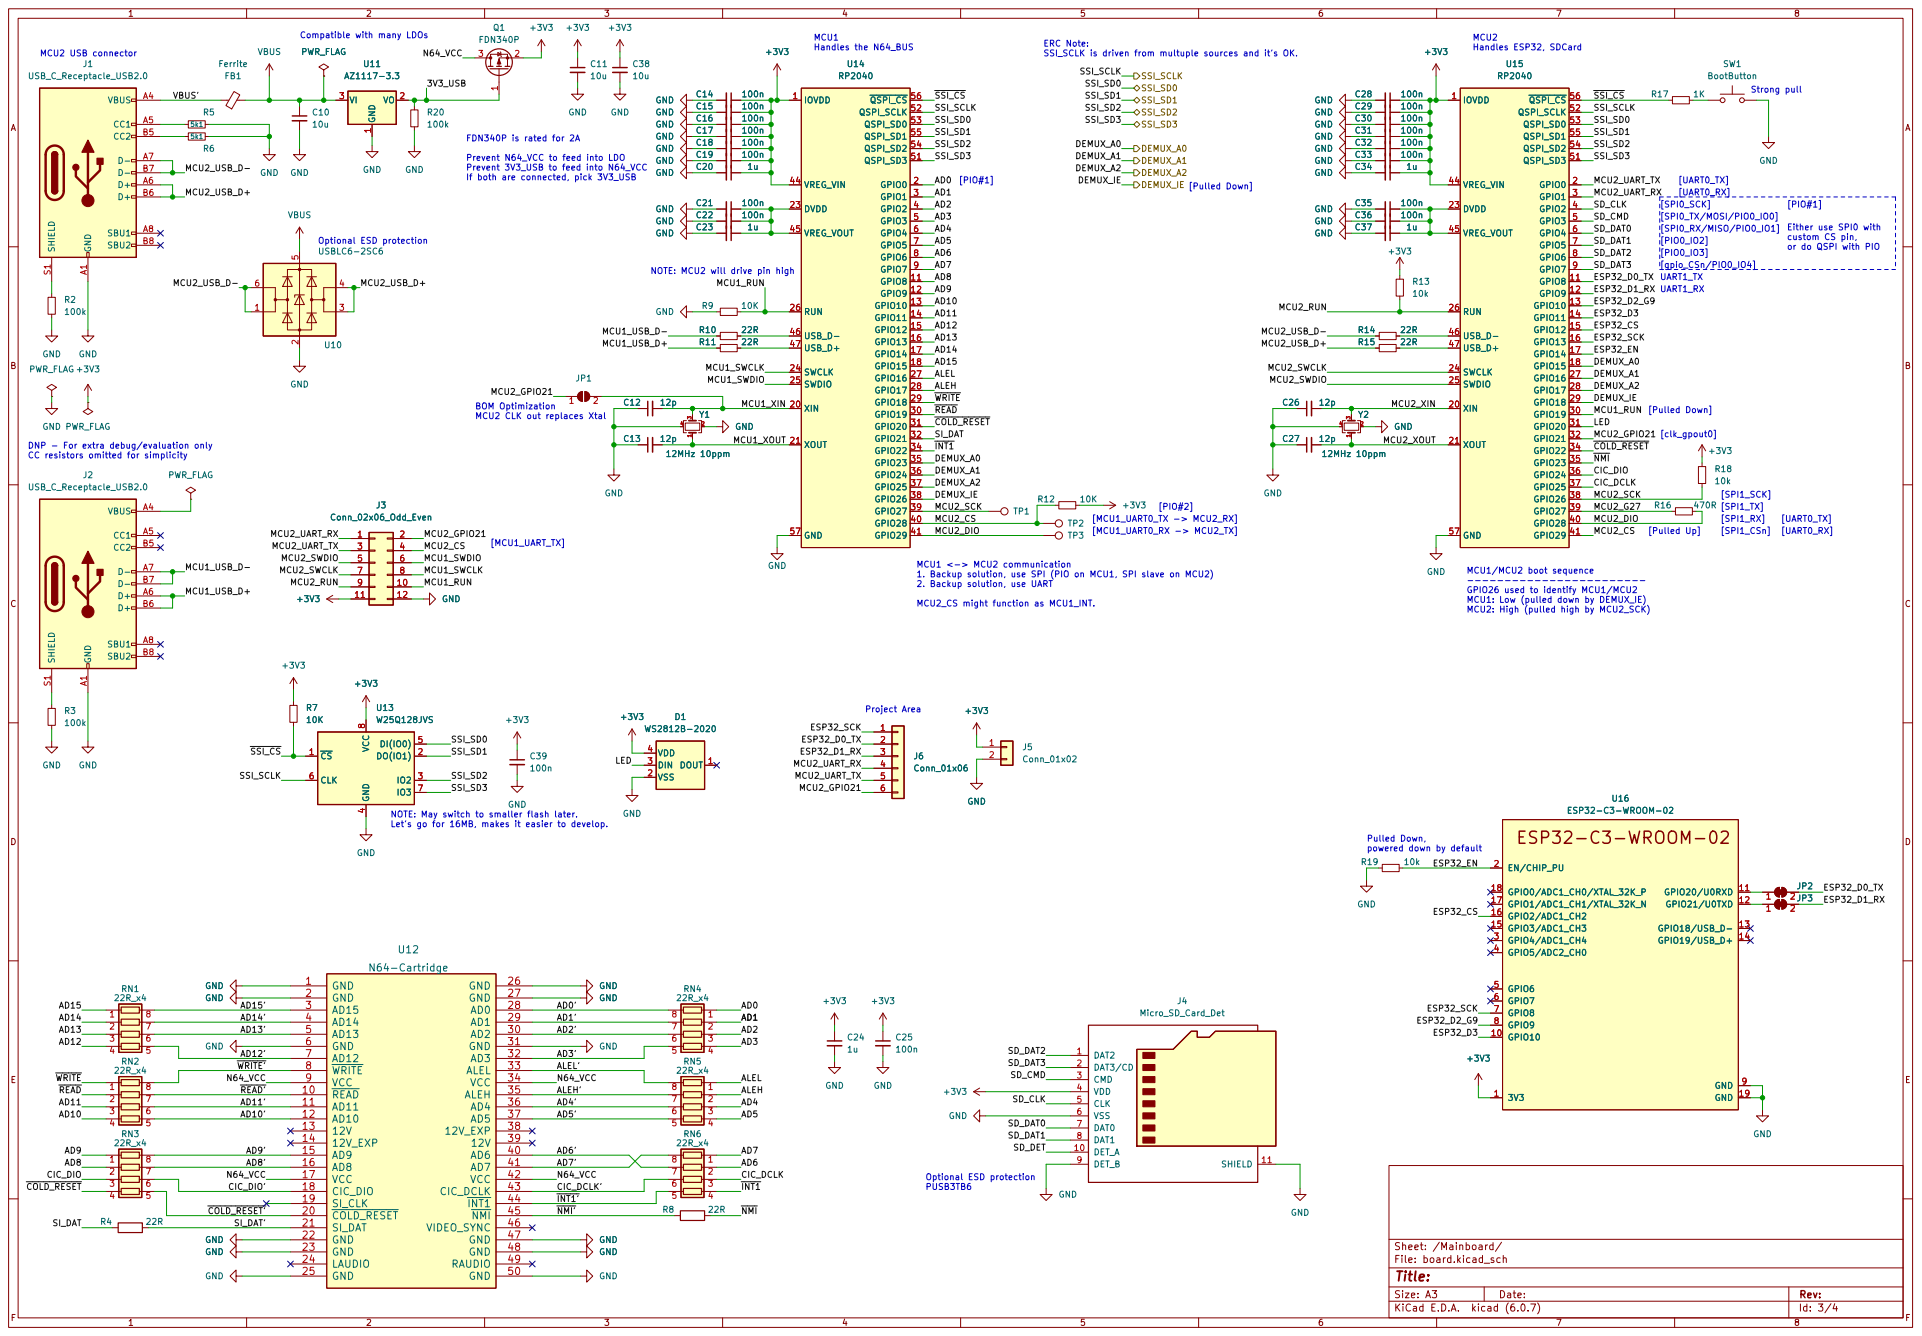
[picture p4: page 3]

Compatible with many LDOs
10u PWR_FLAG

Strong pull MCU1 Handles the N64_BUS

[SPI1_SCK] MCU2 Handles ESP32, SDCard
GND GND

[PIO0_IO3] ERC Note: SSI_SCLK is driven from multuple sources and it's OK.

Prevent N64_VCC to feed into LDO
Prevent 3V3_USB to feed into N64_VCC
If both are connected, pick 3V3_USB

[PIO#1] Either use SPI0 with

custom CS pin, or do QSPI with PIO

NOTE: MCU2 will drive pin high

BOM Optimization
MCU2 CLK out replaces Xtal

GND
DNP - For extra debug/evaluation only
CC resistors omitted for simplicity

J3 Conn_02x06_Odd_Even
10K GND GND GND GND

1. Backup solution, use SPI (PIO on MCU1, SPI slave on MCU2)
2. Backup solution, use UART

MCU1: Low (pulled down by DEMUX_IE)
MCU2: High (pulled high by MCU2_SCK)

NOTE: May switch to smaller flash later.
Let's go for 16MB, makes it easier to develop.

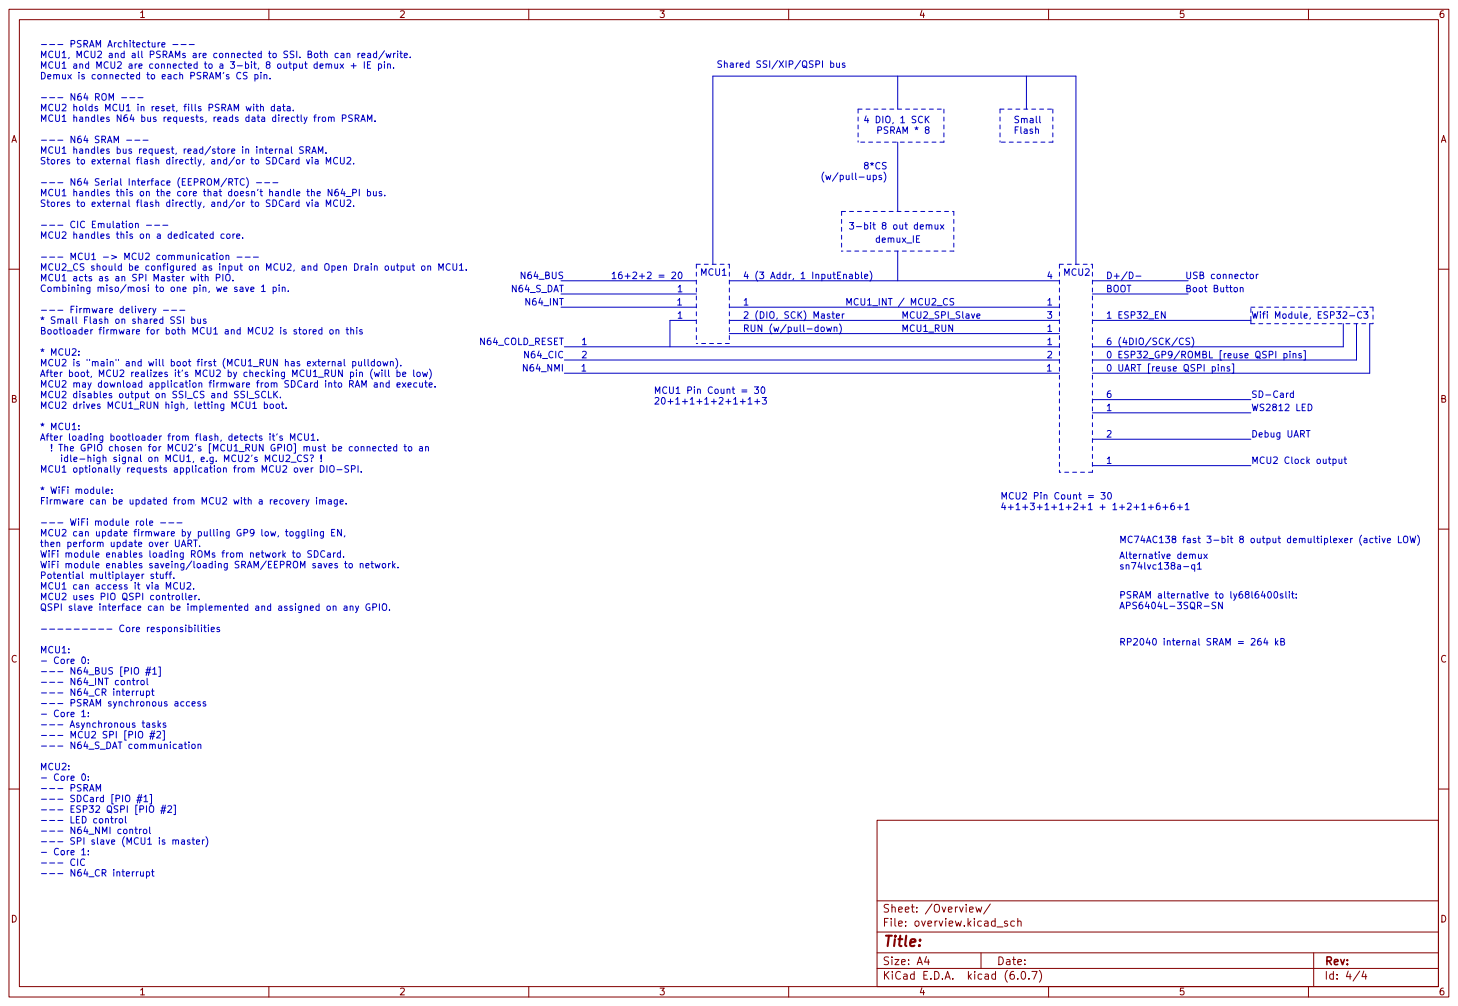
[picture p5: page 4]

--- PSRAM Architecture --- MCU1, MCU2 and all PSRAMs are connected to SSI. Both can read/write. MCU1 and MCU2 are connected to a 3-bit, 8 output demux + IE pin.

Demux is connected to each PSRAM's CS pin. --- N64 ROM --- MCU2 holds MCU1 in reset, fills PSRAM with data. MCU1 handles N64 bus requests, reads data directly from PSRAM. --- N64 SRAM --- MCU1 handles bus request, read/store in internal SRAM.

Stores to external flash directly, and/or to SDCard via MCU2.

--- N64 Serial Interface (EEPROM/RTC) --- MCU1 handles this on the core that doesn't handle the N64_PI bus. Stores to external flash directly, and/or to SDCard via MCU2. --- CIC Emulation --- MCU2 handles this on a dedicated core. --- MCU1 -> MCU2 communication --- MCU2_CS should be configured as input on MCU2, and Open Drain output on MCU1. MCU1 acts as an SPI Master with PIO. Combining miso/mosi to one pin, we save 1 pin.

0 ESP32_GP9/ROMBL [reuse QSPI pins] 1

--- Firmware delivery --- * Small Flash on shared SSI bus Bootloader firmware for both MCU1 and MCU2 is stored on this

0 UART [reuse QSPI pins] 1 ESP32_EN

* MCU2: MCU2 is "main" and will boot first (MCU1_RUN has external pulldown).

After boot, MCU2 realizes it's MCU2 by checking MCU1_RUN pin (will be low)
MCU2 may download application firmware from SDCard into RAM and execute.
MCU2 disables output on SSI_CS and SSI_SCLK.
MCU2 drives MCU1_RUN high, letting MCU1 boot. * MCU1: After loading bootloader from flash, detects it's MCU1.

! The GPIO chosen for MCU2's [MCU1_RUN GPIO] must be connected to an
idle-high signal on MCU1, e.g. MCU2's MCU2_CS? !
MCU1 optionally requests application from MCU2 over DIO-SPI. * WiFi module: Firmware can be updated from MCU2 with a recovery image. --- WiFi module role --- MCU2 can update firmware by pulling GP9 low, toggling EN,

then perform update over UART.
WiFi module enables loading ROMs from network to SDCard.
WiFi module enables saveing/loading SRAM/EEPROM saves to network.
Potential multiplayer stuff. MCU1 can access it via MCU2. MCU2 uses PIO QSPI controller. QSPI slave interface can be implemented and assigned on any GPIO.

PSRAM alternative to ly68l6400slit: APS6404L-3SQR-SN

--------- Core responsibilities MCU1: - Core 0: --- N64_BUS [PIO #1] --- N64_INT control --- N64_CR interrupt

--- MCU2 SPI [PIO #2] --- N64_S_DAT communication MCU2: - Core 0: --- PSRAM

--- SDCard [PIO #1]
--- ESP32 QSPI [PIO #2] --- LED control --- N64_NMI control --- SPI slave (MCU1 is master)

File: overview.kicad_sch Sheet: /Overview/
Id: 4/4 Title:

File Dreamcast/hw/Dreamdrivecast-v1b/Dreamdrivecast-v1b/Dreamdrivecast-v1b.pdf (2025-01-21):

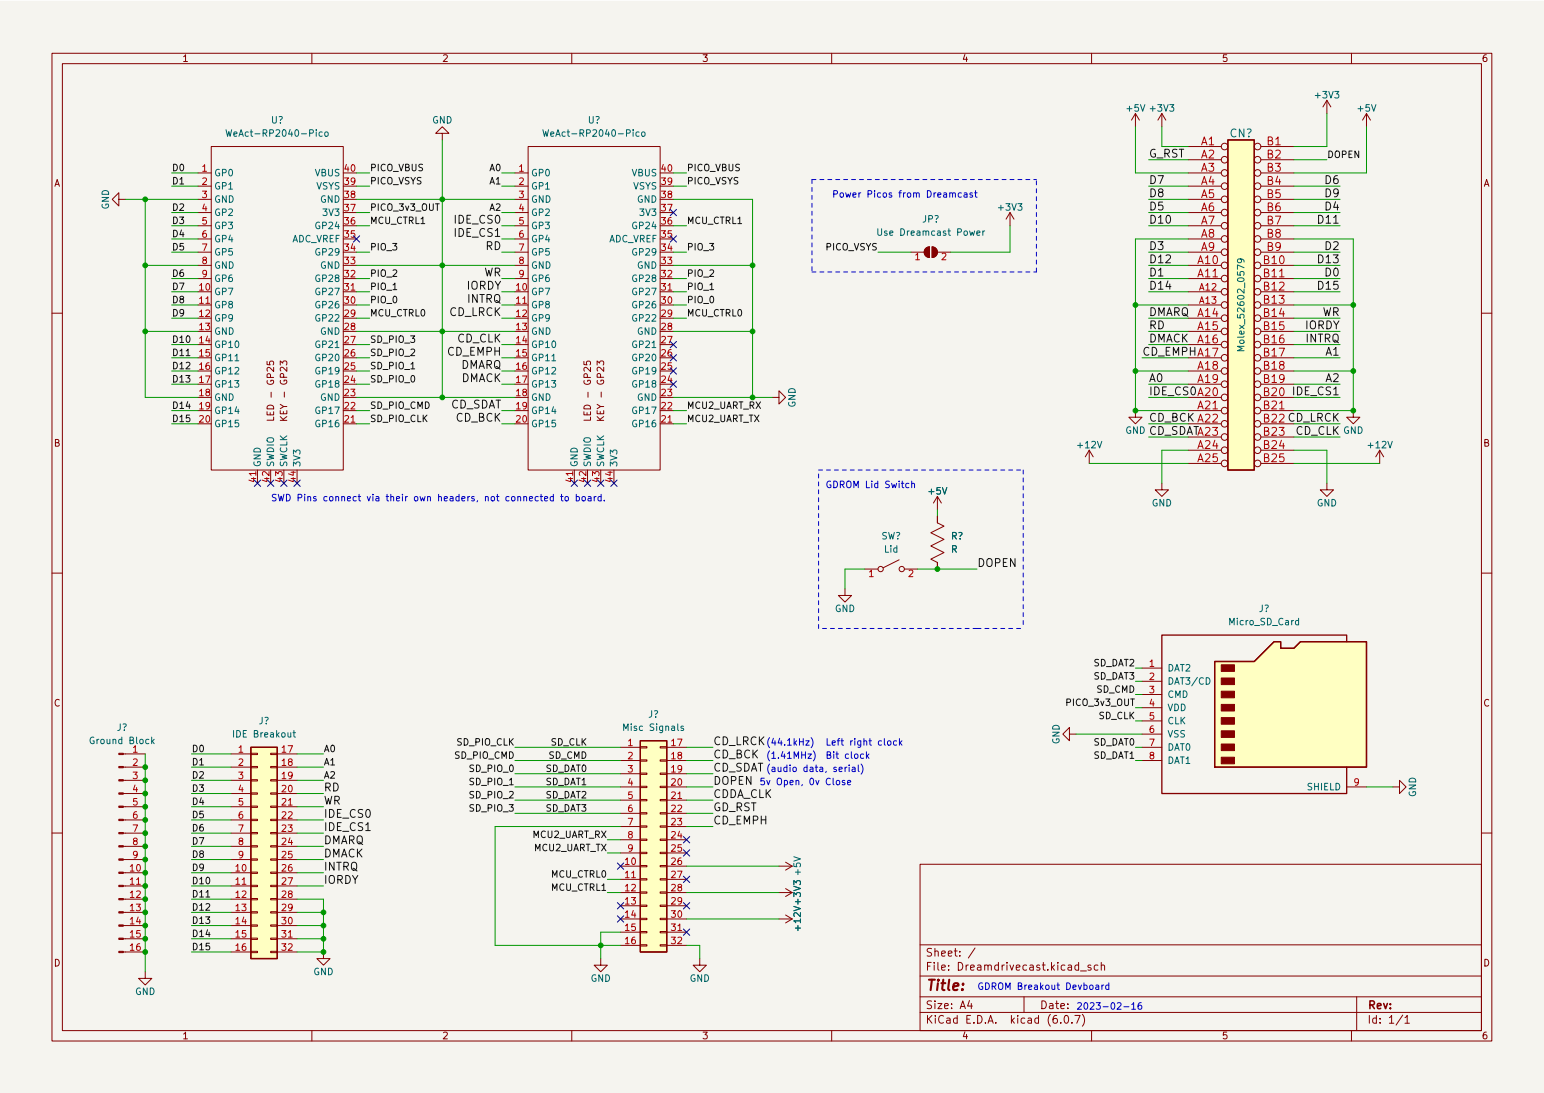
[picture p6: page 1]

(1.41MHz) Power Picos from Dreamcast
GD-ROM chip selection GDROM Lid Switch
IORDY WR
IORDY
INTRQ

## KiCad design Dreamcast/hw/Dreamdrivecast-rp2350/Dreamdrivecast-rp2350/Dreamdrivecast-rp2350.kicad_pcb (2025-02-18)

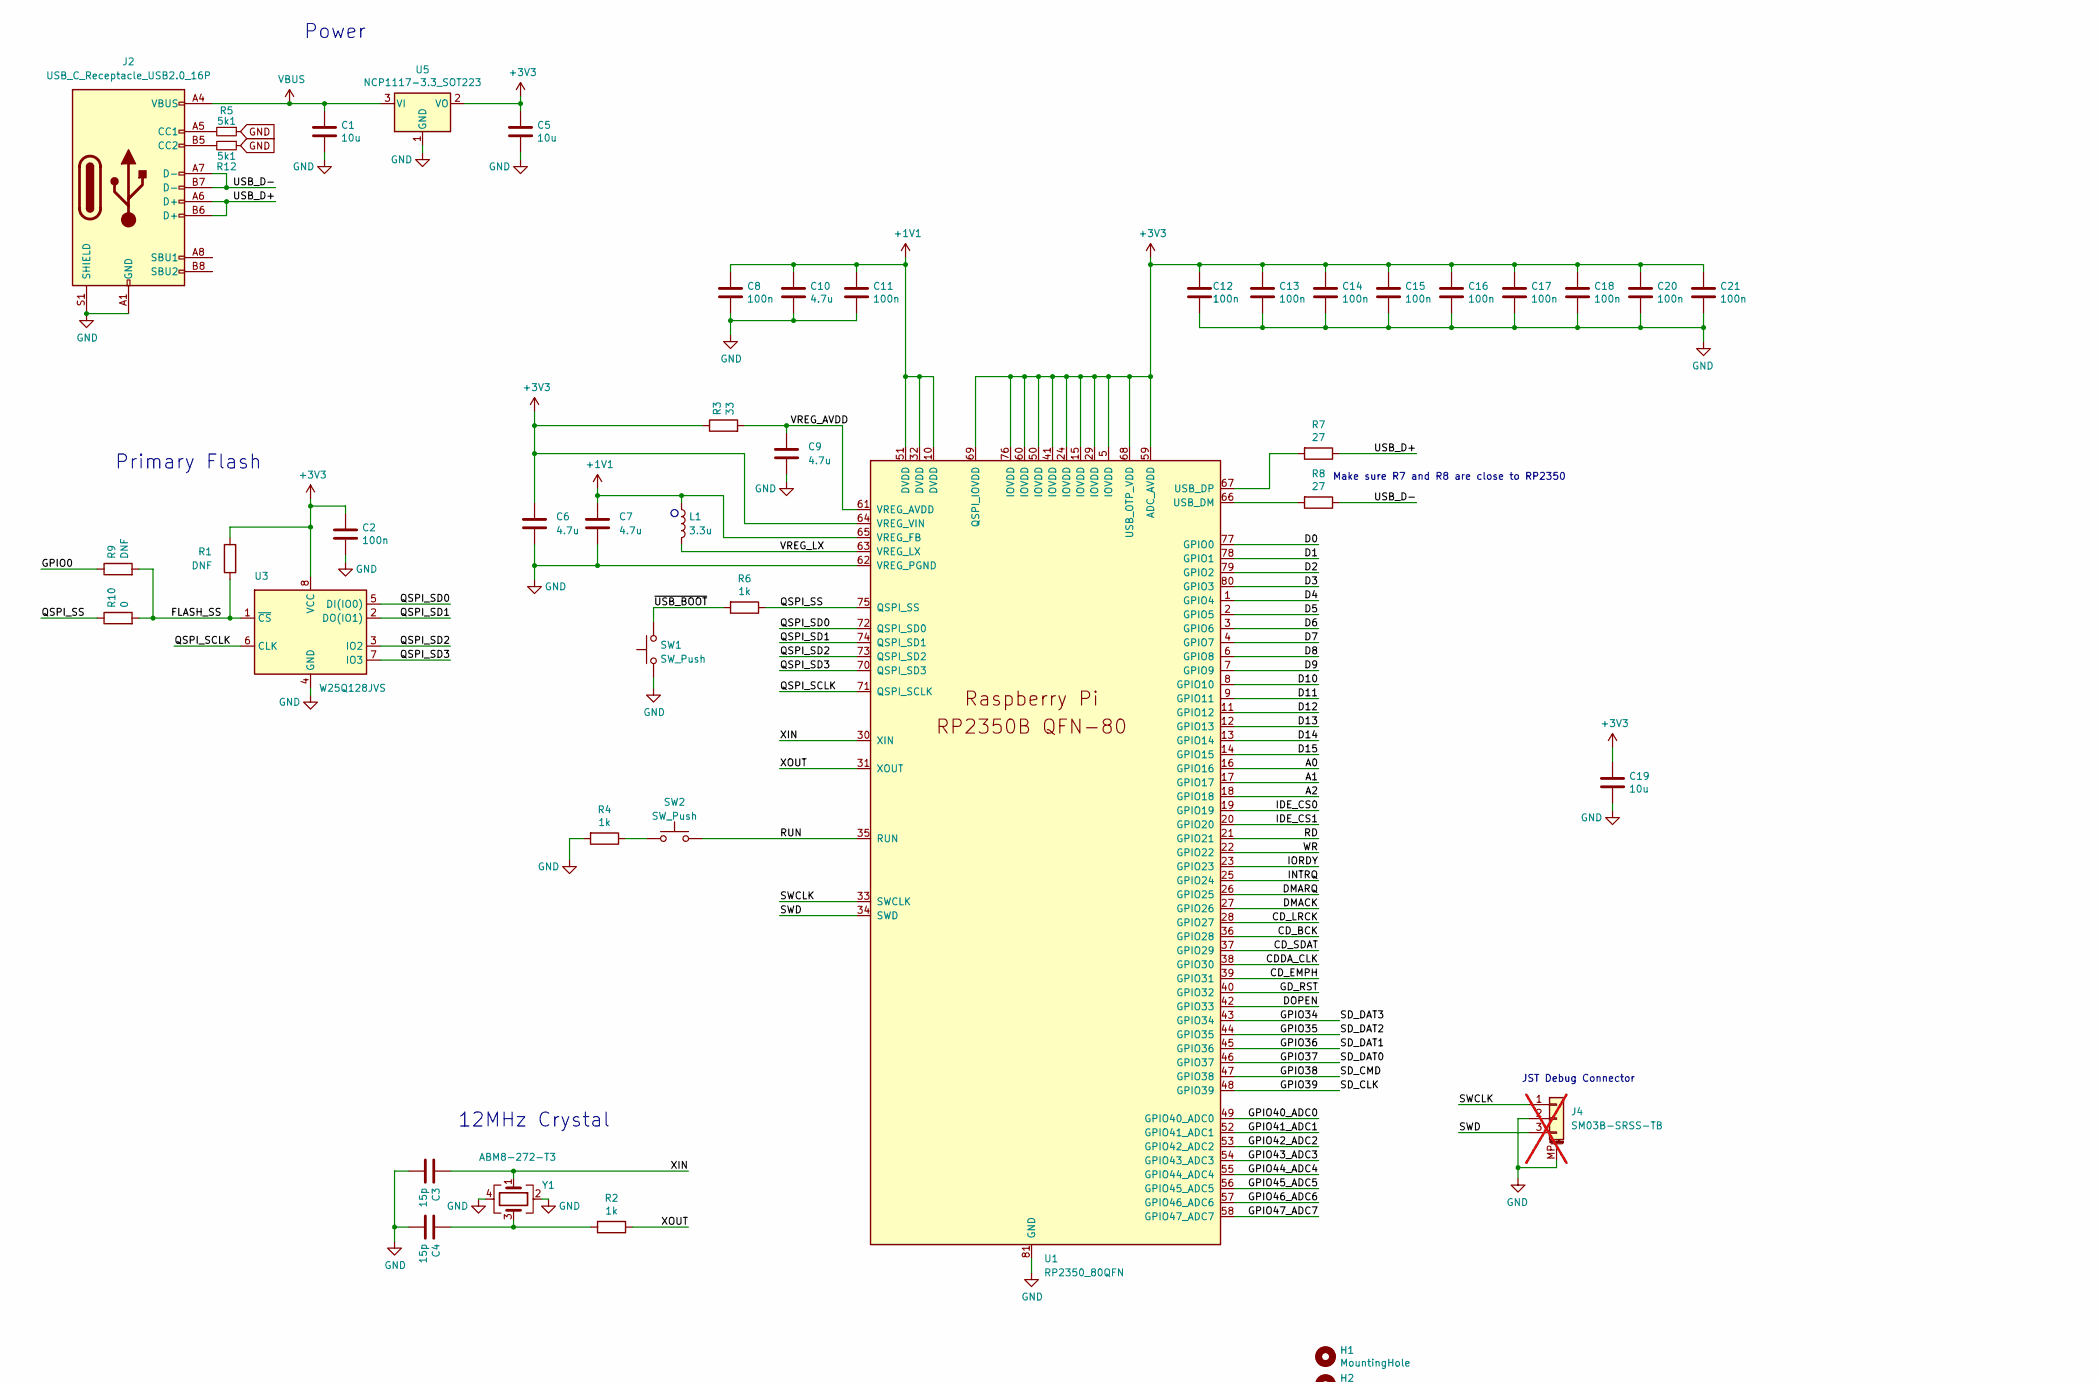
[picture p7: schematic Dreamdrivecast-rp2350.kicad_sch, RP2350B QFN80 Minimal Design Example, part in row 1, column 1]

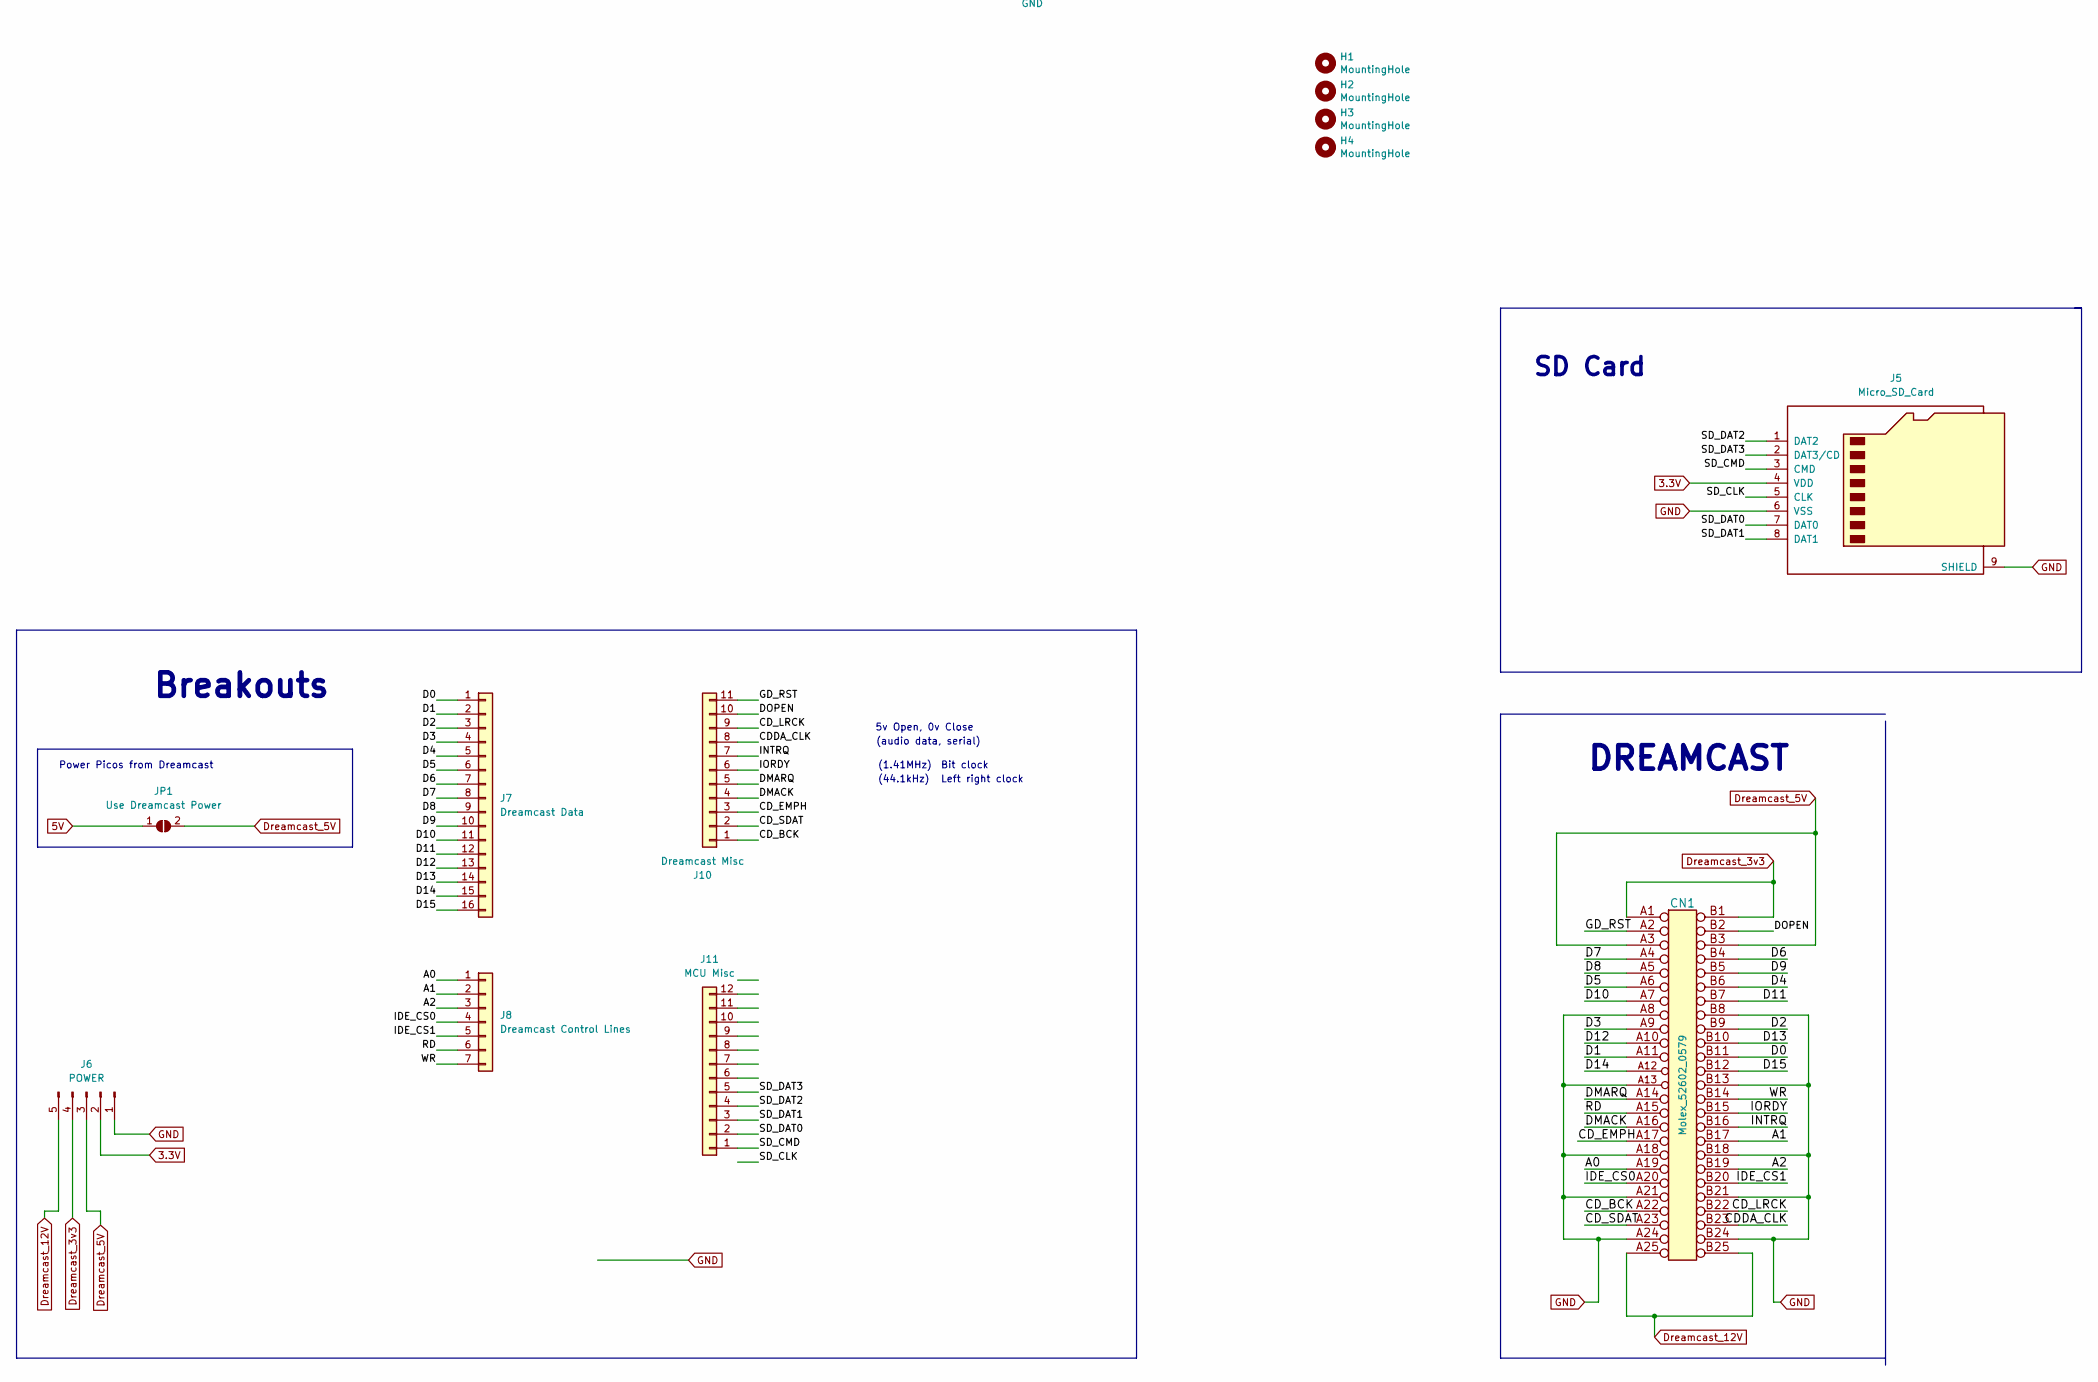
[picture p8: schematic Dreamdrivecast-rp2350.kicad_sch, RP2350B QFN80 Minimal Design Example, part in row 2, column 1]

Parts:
C1, C5, C19: 10u; C_0805_2012Metric
C2, C8, C11, C12, C13, C14, C15, C16, C17, C18, C20, C21: 100n; C_0402_1005Metric
C3, C4: 15p; C_0402_1005Metric
C6, C7: 4.7u; C_0402_1005Metric_small_pads
C9, C10: 4.7u; C_0402_1005Metric
CN1: Molex_52602_0579; LCSC C588209
H1, H2, H3, H4: MountingHole; MountingHole_2.7mm_M2.5
J2: USB_C_Receptacle_USB2.0_16P; USB_C_Receptacle_HRO_TYPE-C-31-M-12
J4: SM03B-SRSS-TB; JST_SH_SM03B-SRSS-TB_1x03-1MP_P1.00mm_Horizontal; not fitted
J5: Micro_SD_Card; microSD_HC_Molex_104031-0811; MPN 1040310811; LCSC C585350
J6: POWER; PinHeader_1x05_P2.54mm_Vertical
J7: Dreamcast Data; PinHeader_1x16_P2.54mm_Vertical
J8: Dreamcast Control Lines; PinHeader_2x07_P2.54mm_Vertical_SMD
J10: Dreamcast Misc; PinHeader_1x11_P2.54mm_Vertical
J11: MCU Misc; PinHeader_1x12_P2.54mm_Vertical
JP1: Use Dreamcast Power; SolderJumper-2_P1.3mm_Open_RoundedPad1.0x1.5mm
L1: 3.3u; L_pol_2016
R1, R9: DNF; R_0402_1005Metric
R2, R4, R6: 1k; R_0402_1005Metric
R3: 33; R_0402_1005Metric
R5, R12: 5k1; R_0402_1005Metric; LCSC C25905
R7, R8: 27; R_0402_1005Metric
R10: 0; R_0402_1005Metric
SW1, SW2: SW_Push; SW_Push_1P1T_NO_Vertical_Wuerth_434133025816
U1: RP2350_80QFN; RP2350-QFN-80-1EP_10x10_P0.4mm_EP3.4x3.4mm_ThermalVias
U3: W25Q128JVS; SOIC-8_5.23x5.23mm_P1.27mm
U5: NCP1117-3.3_SOT223; SOT-223-3_TabPin2
Y1: ABM8-272-T3; Crystal_SMD_3225-4Pin_3.2x2.5mm

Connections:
3.3V: J5.4 (VDD), J6.2
5V: JP1.1 (A)
+1V1: C7.1, C8.1, C10.1, C11.1, L1.1, U1.10 (DVDD), U1.32 (DVDD), U1.51 (DVDD), U1.65 (VREG_FB)
+3V3: C2.1, C5.1, C6.1, C12.1, C13.1, C14.1, C15.1, C16.1, C17.1, C18.1, C19.1, C20.1, C21.1, R1.1, R3.1, U1.5 (IOVDD), U1.15 (IOVDD), U1.24 (IOVDD), U1.29 (IOVDD), U1.41 (IOVDD), U1.50 (IOVDD), U1.59 (ADC_AVDD), U1.60 (IOVDD), U1.64 (VREG_VIN), U1.68 (USB_OTP_VDD), U1.69 (QSPI_IOVDD), U1.76 (IOVDD), U3.8 (VCC), U5.2 (VO)
/A0: CN1.A19, J8.1, U1.16 (GPIO16)
/A1: CN1.B17, J8.2, U1.17 (GPIO17)
/A2: CN1.B19, J8.3, U1.18 (GPIO18)
/CDDA_CLK: CN1.B23, J10.8, U1.38 (GPIO30)
/CD_BCK: CN1.A22, J10.1, U1.36 (GPIO28)
/CD_EMPH: CN1.A17, J10.3, U1.39 (GPIO31)
/CD_LRCK: CN1.B22, J10.9, U1.28 (GPIO27)
/CD_SDAT: CN1.A23, J10.2, U1.37 (GPIO29)
/D0: CN1.B11, J7.1, U1.77 (GPIO0)
/D1: CN1.A11, J7.2, U1.78 (GPIO1)
/D2: CN1.B9, J7.3, U1.79 (GPIO2)
/D3: CN1.A9, J7.4, U1.80 (GPIO3)
/D4: CN1.B6, J7.5, U1.1 (GPIO4)
/D5: CN1.A6, J7.6, U1.2 (GPIO5)
/D6: CN1.B4, J7.7, U1.3 (GPIO6)
/D7: CN1.A4, J7.8, U1.4 (GPIO7)
/D8: CN1.A5, J7.9, U1.6 (GPIO8)
/D9: CN1.B5, J7.10, U1.7 (GPIO9)
/D10: CN1.A7, J7.11, U1.8 (GPIO10)
/D11: CN1.B7, J7.12, U1.9 (GPIO11)
/D12: CN1.A10, J7.13, U1.11 (GPIO12)
/D13: CN1.B10, J7.14, U1.12 (GPIO13)
/D14: CN1.A12, J7.15, U1.13 (GPIO14)
/D15: CN1.B12, J7.16, U1.14 (GPIO15)
/DMACK: CN1.A16, J10.4, U1.27 (GPIO26)
/DMARQ: CN1.A14, J10.5, U1.26 (GPIO25)
/DOPEN: CN1.B2, J10.10, U1.42 (GPIO33)
/FLASH_SS: R1.2, R9.2, R10.2, U3.1 (~CS)
/GD_RST: CN1.A2, J10.11, U1.40 (GPIO32)
/GPIO0: R9.1
/GPIO34: J5.2 (DAT3/CD), J11.5, U1.43 (GPIO34)
/GPIO35: J5.1 (DAT2), J11.4, U1.44 (GPIO35)
/GPIO36: J5.8 (DAT1), J11.3, U1.45 (GPIO36)
/GPIO37: J5.7 (DAT0), J11.2, U1.46 (GPIO37)
/GPIO38: J5.3 (CMD), J11.1, U1.47 (GPIO38)
/GPIO39: J5.5 (CLK), U1.48 (GPIO39)
/GPIO40_ADC0: U1.49 (GPIO40_ADC0)
/GPIO41_ADC1: U1.52 (GPIO41_ADC1)
/GPIO42_ADC2: U1.53 (GPIO42_ADC2)
/GPIO43_ADC3: U1.54 (GPIO43_ADC3)
/GPIO44_ADC4: U1.55 (GPIO44_ADC4)
/GPIO45_ADC5: U1.56 (GPIO45_ADC5)
/GPIO46_ADC6: U1.57 (GPIO46_ADC6)
/GPIO47_ADC7: U1.58 (GPIO47_ADC7)
/IDE_CS0: CN1.A20, J8.4, U1.19 (GPIO19)
/IDE_CS1: CN1.B20, J8.5, U1.20 (GPIO20)
/INTRQ: CN1.B16, J10.7, U1.25 (GPIO24)
/IORDY: CN1.B15, J10.6, U1.23 (GPIO23)
/QSPI_SCLK: U1.71 (QSPI_SCLK), U3.6 (CLK)
/QSPI_SD0: U1.72 (QSPI_SD0), U3.5 (DI(IO0))
/QSPI_SD1: U1.74 (QSPI_SD1), U3.2 (DO(IO1))
/QSPI_SD2: U1.73 (QSPI_SD2), U3.3 (IO2)
/QSPI_SD3: U1.70 (QSPI_SD3), U3.7 (IO3)
/QSPI_SS: R6.1, R10.1, U1.75 (QSPI_SS)
/RD: CN1.A15, J8.6, U1.21 (GPIO21)
/RUN: SW2.2, U1.35 (RUN)
/SWCLK: J4.1, U1.33 (SWCLK); also elsewhere on the board
/SWD: J4.3, U1.34 (SWD); also elsewhere on the board
/USB_D+: J2.A6 (D+), J2.B6 (D+), R7.1
/USB_D-: J2.A7 (D-), J2.B7 (D-), R8.1
/VREG_AVDD: C9.1, R3.2, U1.61 (VREG_AVDD)
/VREG_LX: L1.2, U1.63 (VREG_LX)
/WR: CN1.B14, J8.7, U1.22 (GPIO22)
/XIN: C3.1, U1.30 (XIN), Y1.1
/XOUT: R2.1, U1.31 (XOUT)
/~USB_BOOT: R6.2, SW1.2
Dreamcast_3v3: CN1.A1, CN1.B1, J6.4
Dreamcast_5V: CN1.A3, CN1.B3, J6.3, JP1.2 (B)
Dreamcast_12V: CN1.A25, CN1.B25, J6.5
GND: C1.2, C2.2, C3.2, C4.2, C5.2, C6.2, C7.2, C8.2, C9.2, C10.2, C11.2, C12.2, C13.2, C14.2, C15.2, C16.2, C17.2, C18.2, C19.2, C20.2, C21.2, CN1.A8, CN1.A13, CN1.A18, CN1.A21, CN1.A24, CN1.B8, CN1.B13, CN1.B18, CN1.B21, CN1.B24, J2.A1 (GND), J2.A12 (GND), J2.B1 (GND), J2.B12 (GND), J2.S1 (SHIELD), J4.2, J4.MP (MountPin), J5.6 (VSS), J5.9 (SHIELD), J6.1, R4.2, R5.1, R12.1, SW1.1, U1.62 (VREG_PGND), U1.81 (GND), U3.4 (GND), U5.1 (GND), Y1.2, Y1.4
unnamed: C4.1, R2.2, Y1.3
unnamed: J2.A5 (CC1), R5.2
unnamed: J2.B5 (CC2), R12.2
unnamed: R4.1, SW2.1
unnamed: R8.2, U1.66 (USB_DM)
unnamed: R7.2, U1.67 (USB_DP)
VBUS: C1.1, J2.A4 (VBUS), J2.A9 (VBUS), J2.B4 (VBUS), J2.B9 (VBUS), U5.3 (VI)

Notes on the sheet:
(audio data, serial)
Power Picos from Dreamcast
Power
SD Card
12MHz Crystal
(44.1kHz)
Breakouts
Primary Flash
Bit clock
JST Debug Connector
(1.41MHz)
DREAMCAST
Left right clock
Make sure R7 and R8 are close to RP2350
5v Open, 0v Close

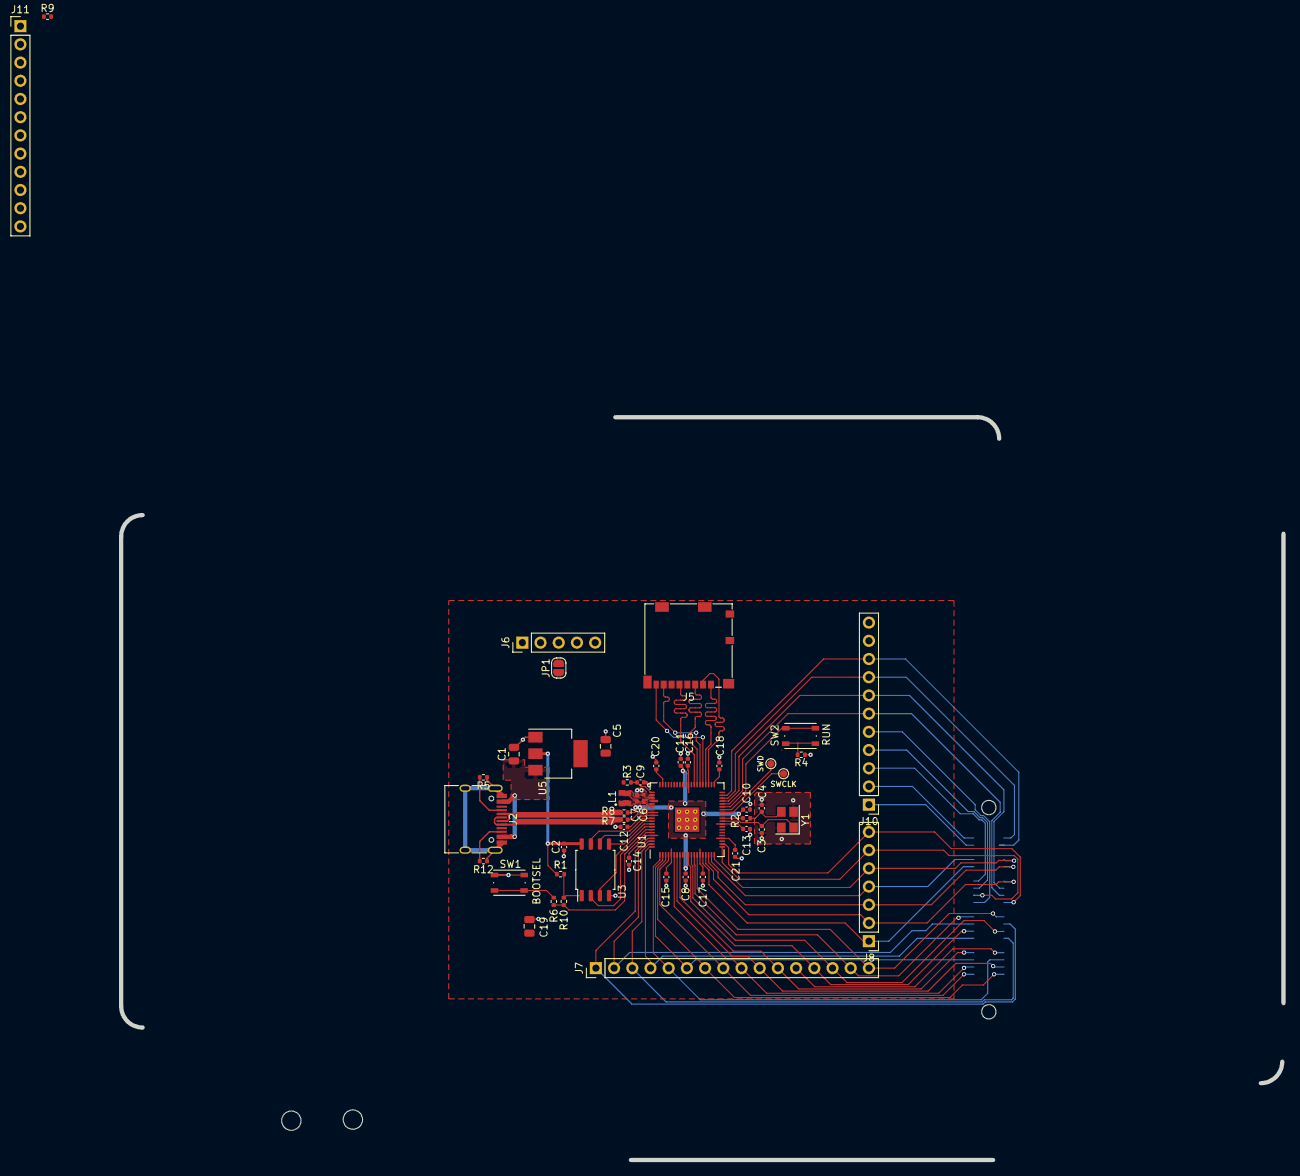
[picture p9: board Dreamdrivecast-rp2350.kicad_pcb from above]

Board: 2 copper layers, 162.2 x 103.6 mm, 54 parts (1 on the bottom side), 71 nets.

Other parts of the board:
SWCLK: SWD; TestPoint_Pad_D1.0mm
SWD: SWD; TestPoint_Pad_D1.0mm

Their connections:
/SWCLK: SWCLK.1; also elsewhere on the board
/SWD: SWD.1; also elsewhere on the board

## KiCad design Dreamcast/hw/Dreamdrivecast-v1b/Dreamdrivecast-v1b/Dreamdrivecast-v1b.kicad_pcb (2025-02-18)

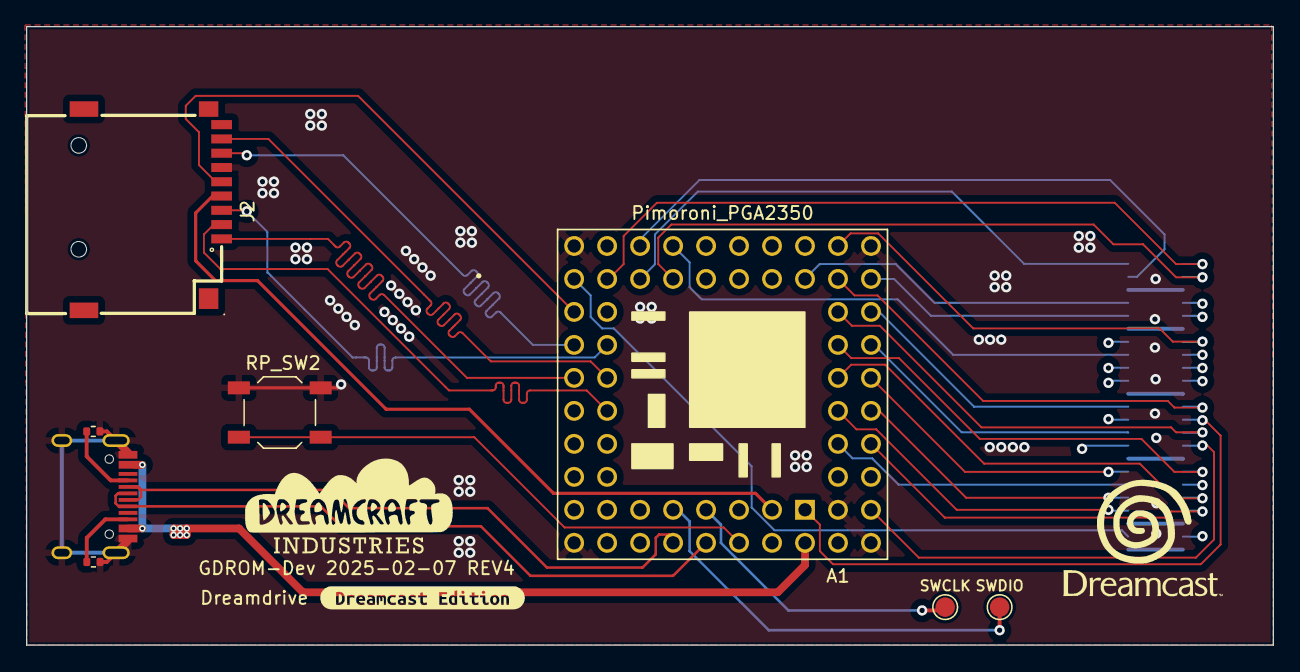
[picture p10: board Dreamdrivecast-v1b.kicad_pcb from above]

Board: 4 copper layers, 96.0 x 47.6 mm, 11 parts (1 on the bottom side), 53 nets.

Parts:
A1: Pimoroni_PGA2350; pimoroni_pga2350
CN1: Molex_52602_0579
DREAMCRAFT_LOGO: LOGO
J1: USB_C_Receptacle_USB2.0; HRO-TYPE-C-31-M-12_LCSC
J2: Micro_SD_Card; TF-SMD_TF-PUSH
R4, R5: 5k1; R_0402_1005Metric
RP_SW2: SW_Push; SW_SPST_TL3342
SWCLK: TestPoint_Pad_D1.5mm
SWDIO: TestPoint_Pad_D1.5mm
kibuzzard-63F149CE: DDR_DREAMCAST; kibuzzard-63F149CE

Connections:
3V3: A1.55 (3V3), J2.4 (VDD)
/A0: A1.16 (GPIO16), CN1.A19
/A1: A1.17 (GPIO17), CN1.B17
/A2: A1.18 (GPIO18), CN1.B19
/CDDA_CLK: A1.31 (GPIO31), CN1.B23
/CD_BCK: A1.28 (GPIO28), CN1.A22
/CD_EMPH: A1.30 (GPIO30), CN1.A17
/CD_LRCK: A1.27 (GPIO27), CN1.B22
/CD_SDAT: A1.29 (GPIO29), CN1.A23
/D0: A1.0 (GPIO0), CN1.B11
/D1: A1.1 (GPIO1), CN1.A11
/D2: A1.2 (GPIO2), CN1.B9
/D3: A1.3 (GPIO3), CN1.A9
/D4: A1.4 (GPIO4), CN1.B6
/D5: A1.5 (GPIO5), CN1.A6
/D6: A1.6 (GPIO6), CN1.B4
/D7: A1.7 (GPIO7), CN1.A4
/D8: A1.8 (GPIO8), CN1.A5
/D9: A1.9 (GPIO9), CN1.B5
/D10: A1.10 (GPIO10), CN1.A7
/D11: A1.11 (GPIO11), CN1.B7
/D12: A1.12 (GPIO12), CN1.A10
/D13: A1.13 (GPIO13), CN1.B10
/D14: A1.14 (GPIO14), CN1.A12
/D15: A1.15 (GPIO15), CN1.B12
/DMACK: A1.26 (GPIO26), CN1.A16
/DMARQ: A1.25 (GPIO25), CN1.A14
/DOPEN: A1.33 (GPIO33), CN1.B2
/GD_RST: A1.32 (GPIO32), CN1.A2
/IDE_CS0: A1.19 (GPIO19), CN1.A20
/IDE_CS1: A1.20 (GPIO20), CN1.B20
/INTRQ: A1.24 (GPIO24), CN1.B16
/IORDY: A1.23 (GPIO23), CN1.B15
/RD: A1.21 (GPIO21), CN1.A15
/SD_CLK: A1.34 (GPIO34), J2.5 (CLK)
/SD_CMD: A1.35 (GPIO35), J2.3 (CMD)
/SD_DAT0: A1.36 (GPIO36), J2.7 (DAT0)
/SD_DAT1: A1.37 (GPIO37), J2.8 (DAT1)
/SD_DAT2: A1.38 (GPIO38), J2.1 (DAT2)
/SD_DAT3: A1.39 (GPIO39), J2.2 (DAT3/CD)
/SWCLK: A1.51 (SWCLK), SWCLK.1
/SWDIO: A1.49 (SWDIO), SWDIO.1
/WR: A1.22 (GPIO22), CN1.B14
Dreamcast_3v3: CN1.A1, CN1.B1
Dreamcast_5V: CN1.A3, CN1.B3
Dreamcast_12V: CN1.A25, CN1.B25
GND: A1.58 (GND), A1.59 (GND), A1.60 (GND), A1.61 (GND), A1.62 (GND), A1.63 (GND), CN1.A8, CN1.A13, CN1.A18, CN1.A21, CN1.A24, CN1.B8, CN1.B13, CN1.B18, CN1.B21, CN1.B24, J1.A1 (GND), J1.A12 (GND), J1.B1 (GND), J1.B12 (GND), J1.S1 (SHIELD), J2.6 (VSS), R4.1, R5.1, RP_SW2.2
unnamed: J1.A5 (CC1), R5.2
unnamed: J1.B5 (CC2), R4.2
RP1_RUN_PULL: A1.54 (RUN), RP_SW2.1
RP1_USB_D+: A1.52 (USB_DP), J1.A6 (D+), J1.B6 (D+)
RP1_USB_D-: A1.50 (USB_DM), J1.A7 (D-), J1.B7 (D-)
VBUS: A1.57 (VBUS), J1.A4 (VBUS), J1.A9 (VBUS), J1.B4 (VBUS), J1.B9 (VBUS)

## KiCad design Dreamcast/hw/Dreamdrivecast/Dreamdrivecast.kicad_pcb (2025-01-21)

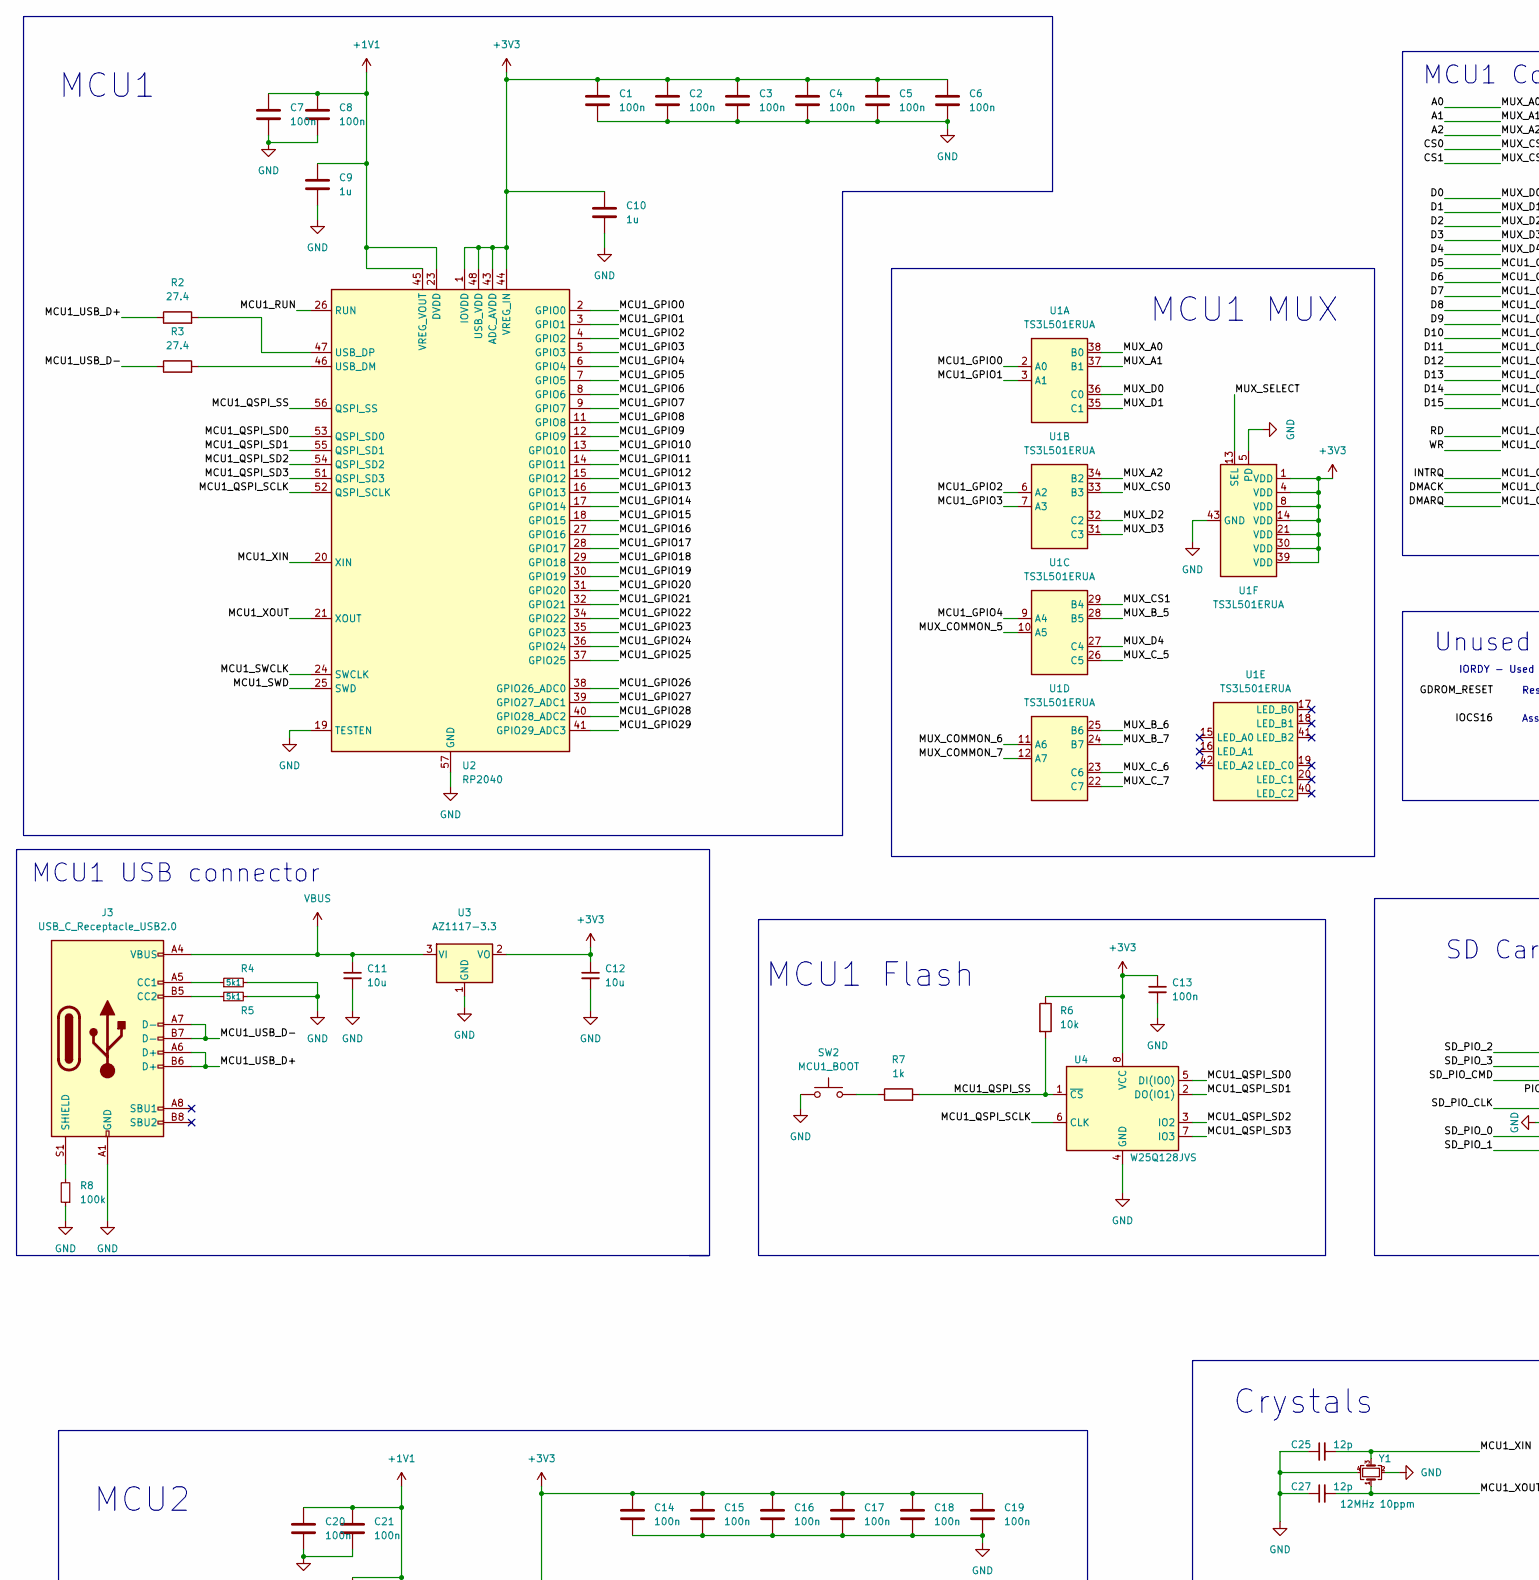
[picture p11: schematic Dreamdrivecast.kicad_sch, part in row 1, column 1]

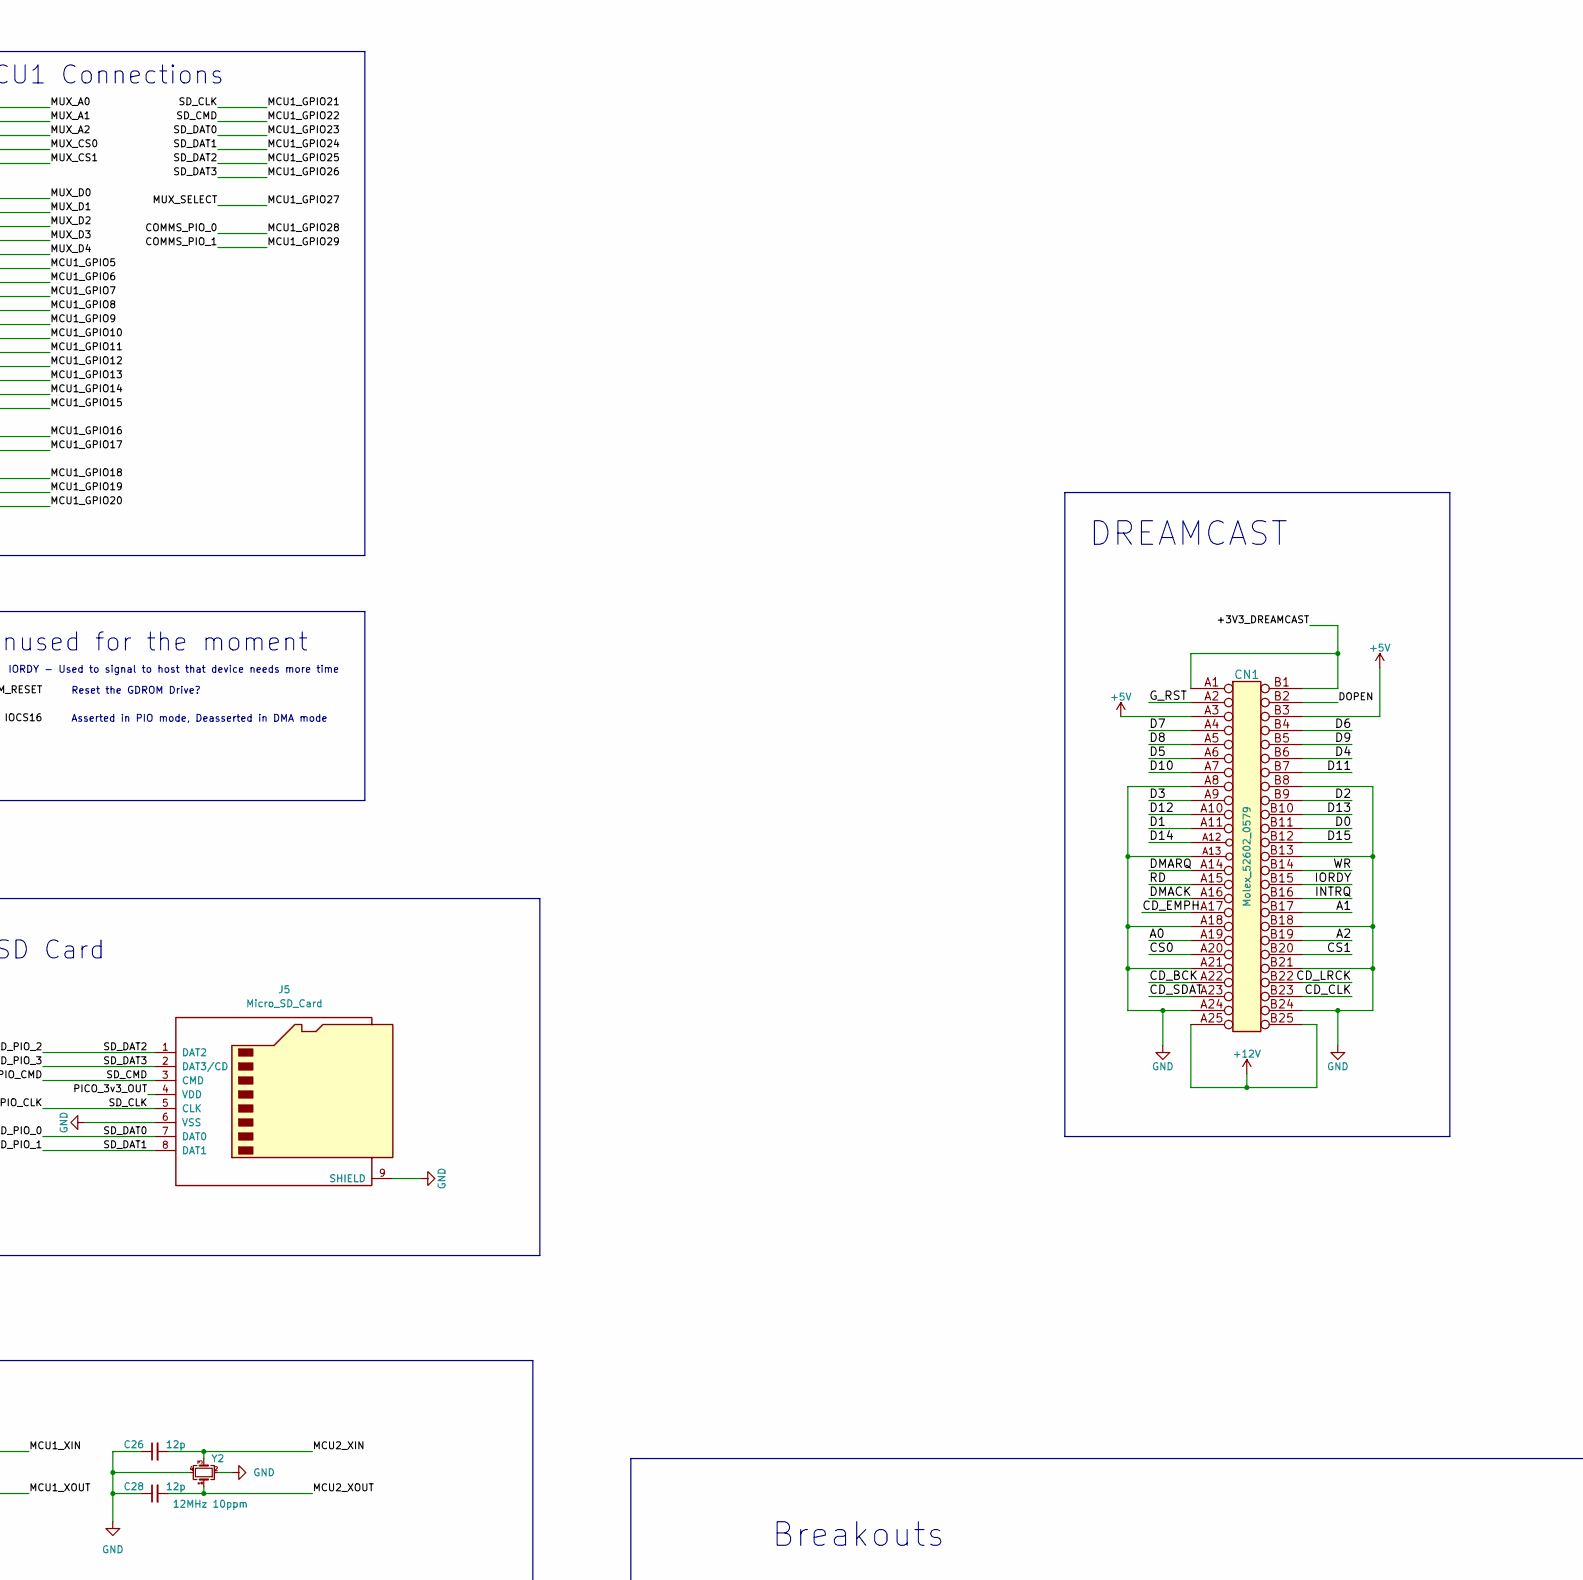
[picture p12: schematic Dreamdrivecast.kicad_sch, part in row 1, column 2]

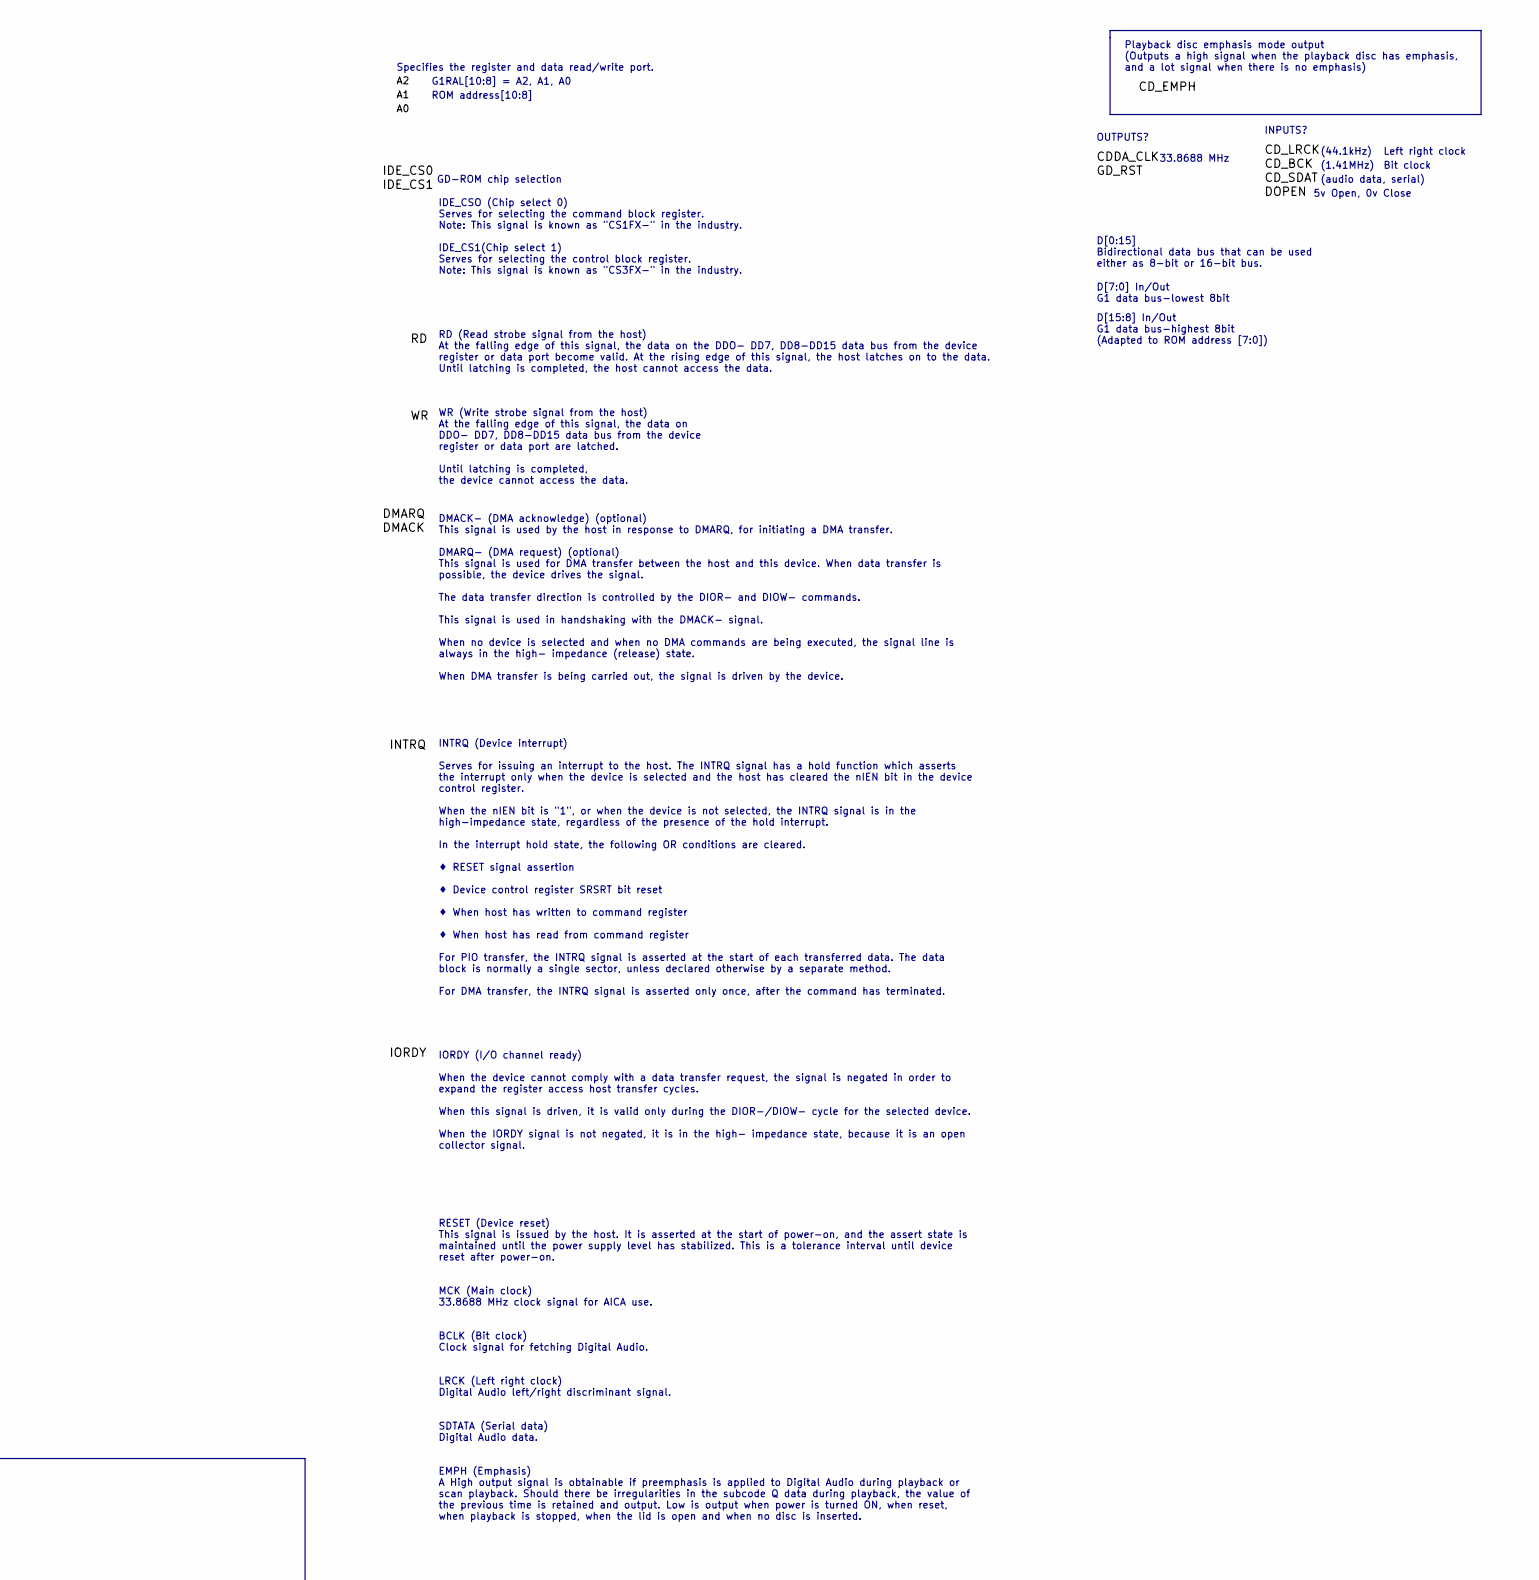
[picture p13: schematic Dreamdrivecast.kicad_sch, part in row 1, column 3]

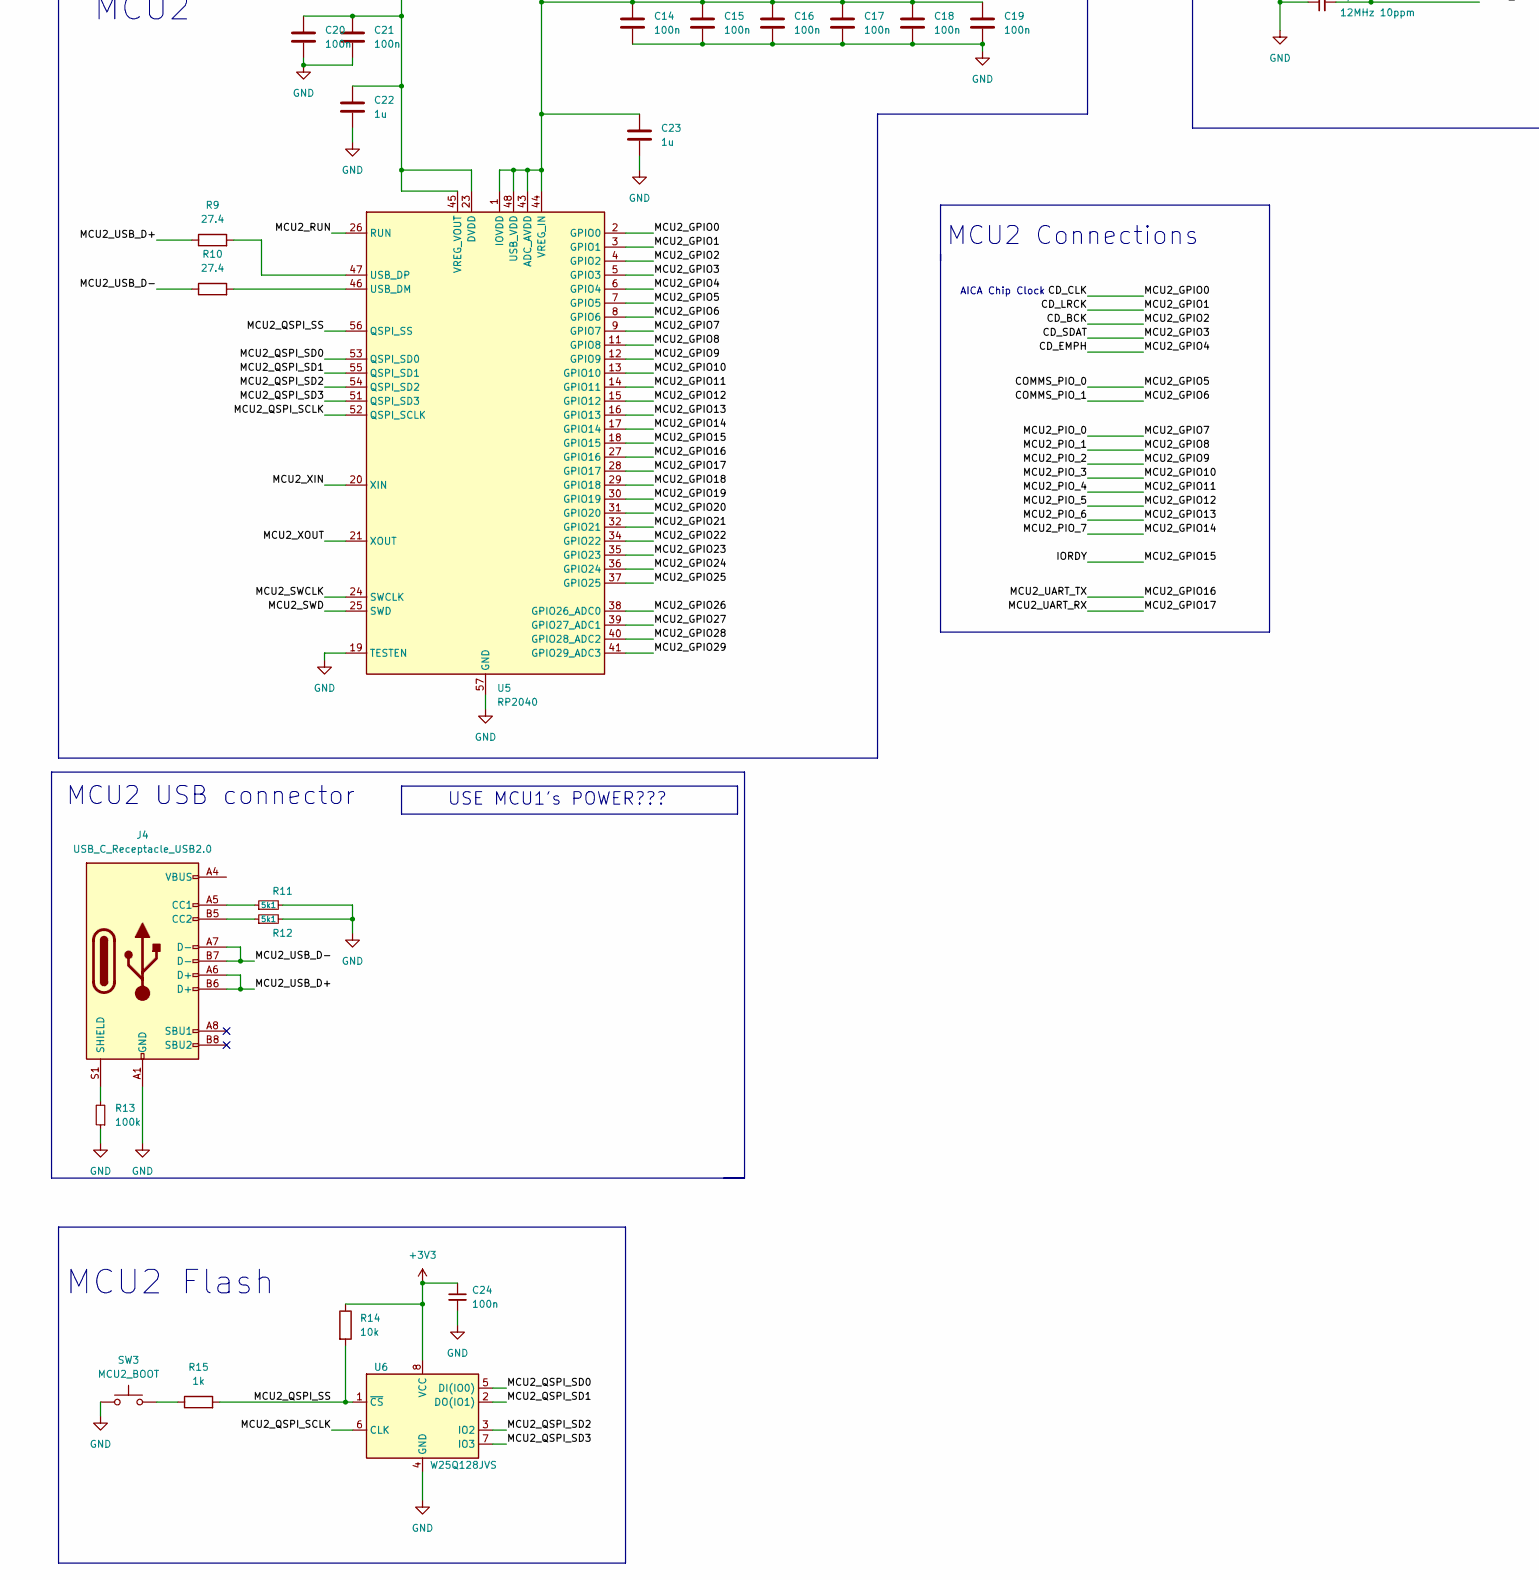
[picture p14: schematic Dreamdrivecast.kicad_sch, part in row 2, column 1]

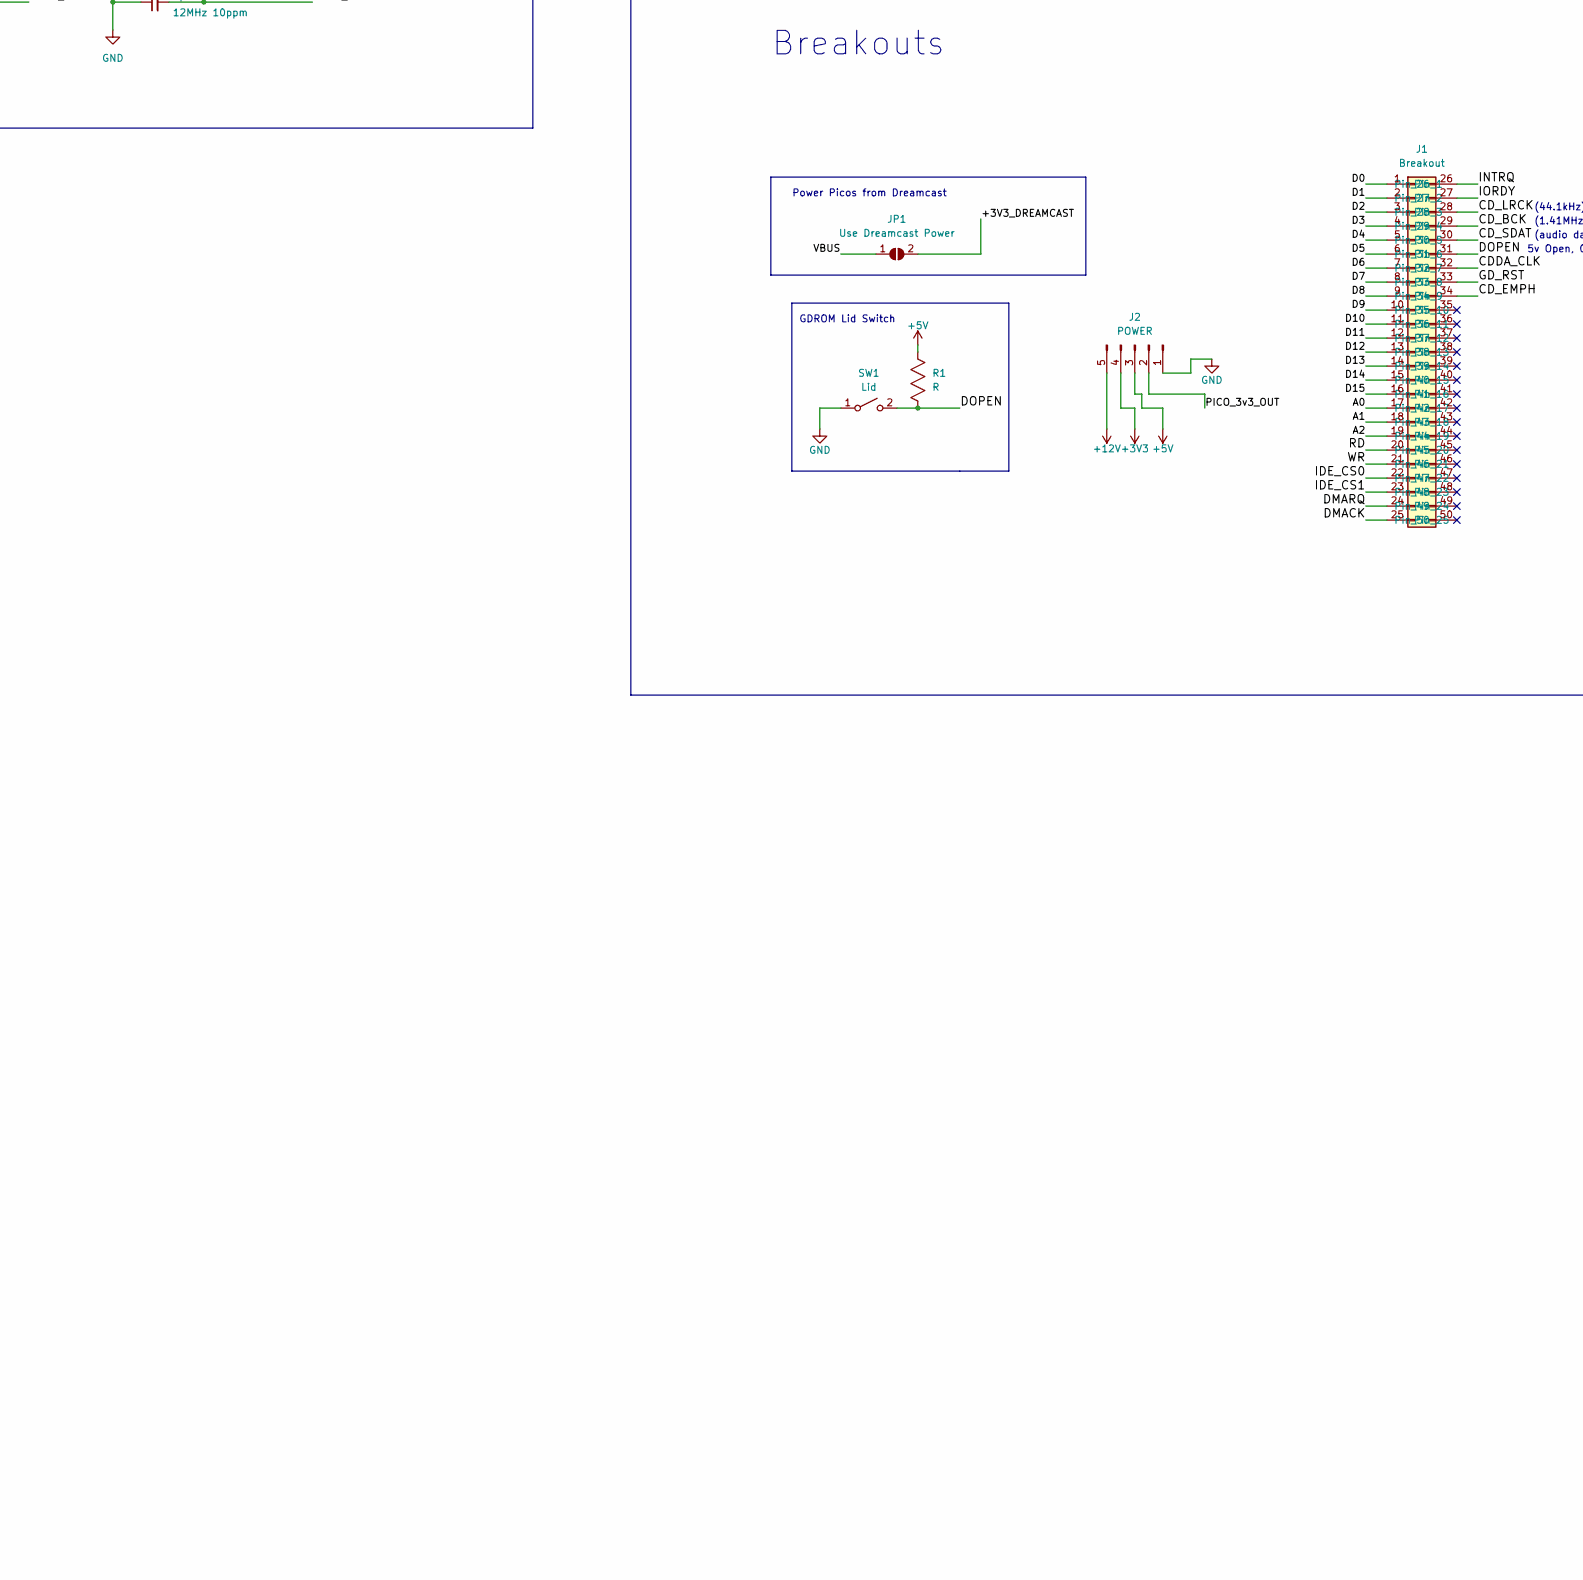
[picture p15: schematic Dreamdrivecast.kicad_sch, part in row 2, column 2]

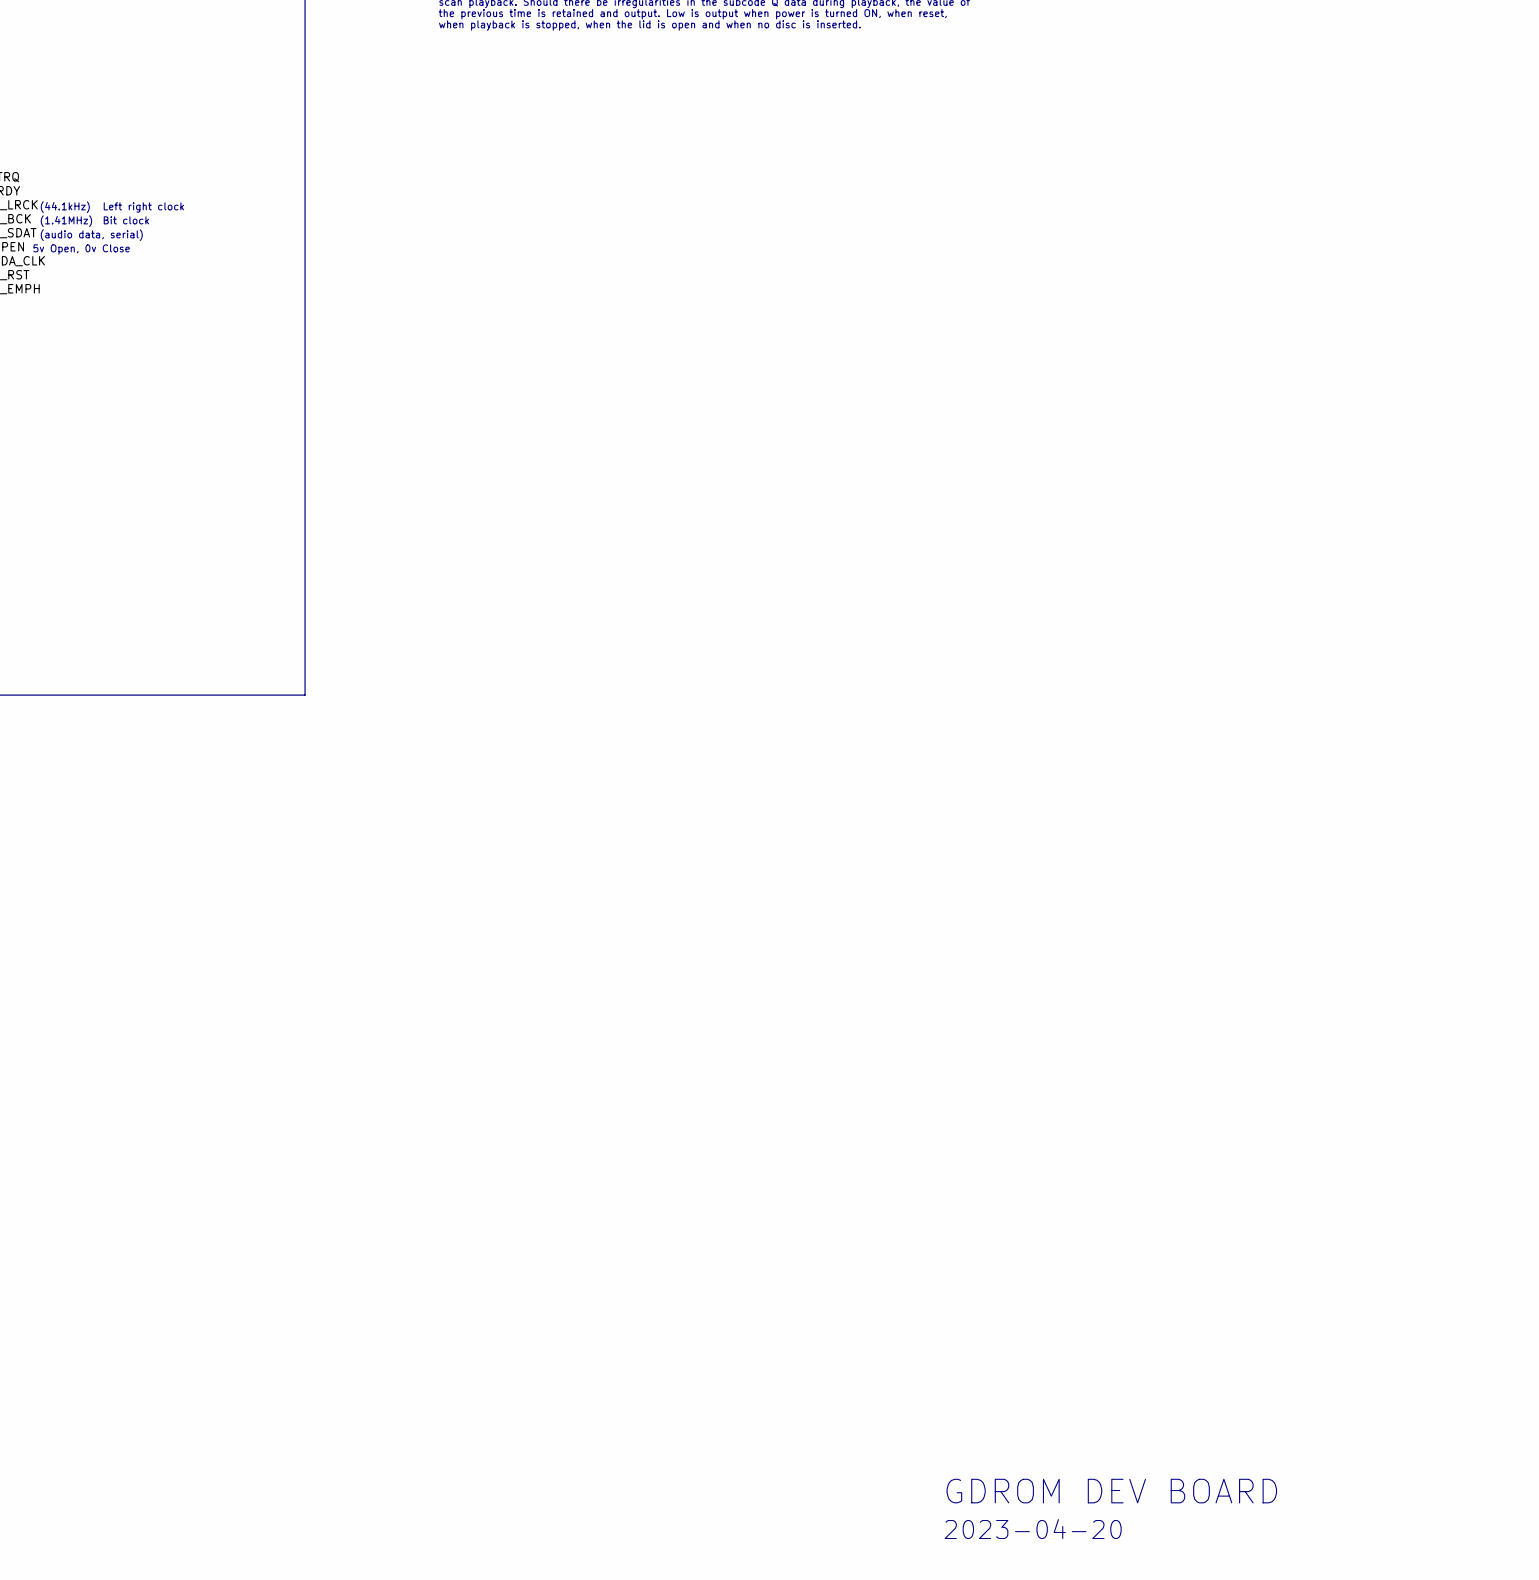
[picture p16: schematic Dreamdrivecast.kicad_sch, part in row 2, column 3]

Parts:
C1, C2, C3, C4, C5, C6, C7, C8, C13, C14, C15, C16, C17, C18, C19, C20, C21, C24: 100n; C_0402_1005Metric; MPN CL05B104KO5NNNC; LCSC C1525
C9, C10, C22, C23: 1u; C_0402_1005Metric; MPN CL05A105KP5NNNC; LCSC C14445
C11, C12: 10u; C_0402_1005Metric; MPN CL05A106MP5NUNC; LCSC C315248
C25, C26, C27, C28: 12p; C_0402_1005Metric; MPN CC0402JRNPO9BN120; LCSC C106201
CN1: Molex_52602_0579; LCSC C588209
J1: Breakout; PinHeader_2x20_P2.54mm_Vertical_SMD
J2: POWER; PinHeader_1x05_P2.54mm_Vertical
J3, J4: USB_C_Receptacle_USB2.0; USB_C_Receptacle_Palconn_UTC16-G; MPN GT-USB-7010ASV; LCSC C2988369
J5: Micro_SD_Card; microSD_HC_Molex_104031-0811; MPN 1040310811; LCSC C585350
JP1: Use Dreamcast Power; SolderJumper-2_P1.3mm_Open_RoundedPad1.0x1.5mm
R1: R; R_Axial_DIN0207_L6.3mm_D2.5mm_P5.08mm_Vertical
R2, R3, R9, R10: 27.4; R_0402_1005Metric; MPN ARG02FTC27R4; LCSC C284479
R4, R5, R11, R12: 5k1; R_0402_1005Metric; MPN 0402WGF5101TCE; LCSC C25905
R6, R14: 10k; R_0402_1005Metric; MPN RC0402FR-0710KL; LCSC C60490
R7, R15: 1k; R_0402_1005Metric; MPN 0402WGJ0102TCE; LCSC C25543
R8, R13: 100k; R_0402_1005Metric; MPN RC0402FR-07100KL; LCSC C60491
SW1: Lid; SW_DIP_SPSTx01_Slide_9.78x4.72mm_W7.62mm_P2.54mm
SW2: MCU1_BOOT; SW_SPST_FSMSM; MPN TS-1092S-B3D2-G; LCSC C520860
SW3: MCU2_BOOT; SW_SPST_FSMSM; MPN TS-1092S-B3D2-G; LCSC C520860
U1: TS3L501ERUA; WQFN-42-1EP_3.5x9mm_P0.5mm_EP2.05x7.55mm; MPN TS3L501ERUAR; LCSC C2652454
U2, U5: RP2040; QFN-56-1EP_7x7mm_P0.4mm_EP3.2x3.2mm; MPN RP2040; LCSC C2040
U3: AZ1117-3.3; SOT-223; MPN AZ1117H-3.3TRG1; LCSC C110474
U4, U6: W25Q128JVS; SOIC-8_5.23x5.23mm_P1.27mm; MPN W25Q128JVSIQ; LCSC C97521
Y1, Y2: 12MHz 10ppm; Crystal_SMD_2520-4Pin_2.5x2.0mm; MPN XYDBPCNANF-12MHZ; LCSC C521567

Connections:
+1V1: C7.1, C8.1, C9.1, C20.1, C21.1, C22.1, U2.23 (DVDD), U2.45 (VREG_VOUT), U2.50 (DVDD), U5.23 (DVDD), U5.45 (VREG_VOUT), U5.50 (DVDD)
+3V3: C1.1, C2.1, C3.1, C4.1, C5.1, C6.1, C10.1, C12.1, C13.1, C14.1, C15.1, C16.1, C17.1, C18.1, C19.1, C23.1, C24.1, J2.4, R6.1, R14.1, U1.1 (VDD), U1.4 (VDD), U1.8 (VDD), U1.14 (VDD), U1.21 (VDD), U1.30 (VDD), U1.39 (VDD), U2.1 (IOVDD), U2.10 (IOVDD), U2.22 (IOVDD), U2.33 (IOVDD), U2.42 (IOVDD), U2.43 (ADC_AVDD), U2.44 (VREG_IN), U2.48 (USB_VDD), U2.49 (IOVDD), U3.2 (VO), U4.8 (VCC), U5.1 (IOVDD), U5.10 (IOVDD), U5.22 (IOVDD), U5.33 (IOVDD), U5.42 (IOVDD), U5.43 (ADC_AVDD), U5.44 (VREG_IN), U5.48 (USB_VDD), U5.49 (IOVDD), U6.8 (VCC)
+5V: CN1.A3, CN1.B3, J2.3, R1.1
+12V: CN1.A25, CN1.B25, J2.5
/+3V3_DREAMCAST: CN1.A1, CN1.B1, JP1.2 (B)
/A0: CN1.A19, J1.17, U1.38 (B0)
/A1: CN1.B17, J1.18, U1.37 (B1)
/A2: CN1.B19, J1.19, U1.34 (B2)
/CD_BCK: CN1.A22, J1.29, U5.4 (GPIO2)
/CD_CLK: CN1.B23, U5.2 (GPIO0)
/CD_EMPH: CN1.A17, J1.34, U5.6 (GPIO4)
/CD_LRCK: CN1.B22, J1.28, U5.3 (GPIO1)
/CD_SDAT: CN1.A23, J1.30, U5.5 (GPIO3)
/COMMS_PIO_0: U2.40 (GPIO28_ADC2), U5.7 (GPIO5)
/COMMS_PIO_1: U2.41 (GPIO29_ADC3), U5.8 (GPIO6)
/CS0: CN1.A20, U1.33 (B3)
/CS1: CN1.B20, U1.29 (B4)
/D0: CN1.B11, J1.1, U1.36 (C0)
/D1: CN1.A11, J1.2, U1.35 (C1)
/D2: CN1.B9, J1.3, U1.32 (C2)
/D3: CN1.A9, J1.4, U1.31 (C3)
/D4: CN1.B6, J1.5, U1.27 (C4)
/D5: CN1.A6, J1.6, U2.7 (GPIO5)
/D6: CN1.B4, J1.7, U2.8 (GPIO6)
/D7: CN1.A4, J1.8, U2.9 (GPIO7)
/D8: CN1.A5, J1.9, U2.11 (GPIO8)
/D9: CN1.B5, J1.10, U2.12 (GPIO9)
/D10: CN1.A7, J1.11, U2.13 (GPIO10)
/D11: CN1.B7, J1.12, U2.14 (GPIO11)
/D12: CN1.A10, J1.13, U2.15 (GPIO12)
/D13: CN1.B10, J1.14, U2.16 (GPIO13)
/D14: CN1.A12, J1.15, U2.17 (GPIO14)
/D15: CN1.B12, J1.16, U2.18 (GPIO15)
/DMACK: CN1.A16, J1.25, U2.30 (GPIO19)
/DMARQ: CN1.A14, J1.24, U2.31 (GPIO20)
/DOPEN: CN1.B2, J1.31, R1.2, SW1.2 (B)
/G_RST: CN1.A2
/INTRQ: CN1.B16, J1.26, U2.29 (GPIO18)
/IORDY: CN1.B15, J1.27, U5.18 (GPIO15)
/MCU1_GPIO0: U1.2 (A0), U2.2 (GPIO0)
/MCU1_GPIO1: U1.3 (A1), U2.3 (GPIO1)
/MCU1_GPIO2: U1.6 (A2), U2.4 (GPIO2)
/MCU1_GPIO3: U1.7 (A3), U2.5 (GPIO3)
/MCU1_GPIO4: U1.9 (A4), U2.6 (GPIO4)
/MCU1_GPIO16: CN1.A15, J1.20, U2.27 (GPIO16)
/MCU1_GPIO17: CN1.B14, J1.21, U2.28 (GPIO17)
/MCU1_GPIO21: J5.5 (CLK), U2.32 (GPIO21)
/MCU1_GPIO22: J5.3 (CMD), U2.34 (GPIO22)
/MCU1_GPIO23: J5.7 (DAT0), U2.35 (GPIO23)
/MCU1_GPIO24: J5.8 (DAT1), U2.36 (GPIO24)
/MCU1_GPIO25: J5.1 (DAT2), U2.37 (GPIO25)
/MCU1_GPIO26: J5.2 (DAT3/CD), U2.38 (GPIO26_ADC0)
/MCU1_GPIO27: U1.13 (SEL), U2.39 (GPIO27_ADC1)
/MCU1_QSPI_SCLK: U2.52 (QSPI_SCLK), U4.6 (CLK)
/MCU1_QSPI_SD0: U2.53 (QSPI_SD0), U4.5 (DI(IO0))
/MCU1_QSPI_SD1: U2.55 (QSPI_SD1), U4.2 (DO(IO1))
/MCU1_QSPI_SD2: U2.54 (QSPI_SD2), U4.3 (IO2)
/MCU1_QSPI_SD3: U2.51 (QSPI_SD3), U4.7 (IO3)
/MCU1_QSPI_SS: R6.2, R7.2, U2.56 (QSPI_SS), U4.1 (~CS)
/MCU1_RUN: U2.26 (RUN); also elsewhere on the board
/MCU1_SWCLK: U2.24 (SWCLK)
/MCU1_SWD: U2.25 (SWD)
/MCU1_USB_D+: J3.A6 (D+), J3.B6 (D+), R2.1
/MCU1_USB_D-: J3.A7 (D-), J3.B7 (D-), R3.1
/MCU1_XIN: C25.2, U2.20 (XIN), Y1.3
/MCU1_XOUT: C27.2, U2.21 (XOUT), Y1.1
/MCU2_GPIO7: U5.9 (GPIO7)
/MCU2_GPIO8: U5.11 (GPIO8)
/MCU2_GPIO9: U5.12 (GPIO9)
/MCU2_GPIO10: U5.13 (GPIO10)
/MCU2_GPIO11: U5.14 (GPIO11)
/MCU2_GPIO12: U5.15 (GPIO12)
/MCU2_GPIO13: U5.16 (GPIO13)
/MCU2_GPIO14: U5.17 (GPIO14)
/MCU2_GPIO16: U5.27 (GPIO16)
/MCU2_GPIO17: U5.28 (GPIO17)
/MCU2_GPIO18: U5.29 (GPIO18)
/MCU2_GPIO19: U5.30 (GPIO19)
/MCU2_GPIO20: U5.31 (GPIO20)
/MCU2_GPIO21: U5.32 (GPIO21)
/MCU2_GPIO22: U5.34 (GPIO22)
/MCU2_GPIO23: U5.35 (GPIO23)
/MCU2_GPIO24: U5.36 (GPIO24)
/MCU2_GPIO25: U5.37 (GPIO25)
/MCU2_GPIO26: U5.38 (GPIO26_ADC0)
/MCU2_GPIO27: U5.39 (GPIO27_ADC1)
/MCU2_GPIO28: U5.40 (GPIO28_ADC2)
/MCU2_GPIO29: U5.41 (GPIO29_ADC3)
/MCU2_QSPI_SCLK: U5.52 (QSPI_SCLK), U6.6 (CLK)
/MCU2_QSPI_SD0: U5.53 (QSPI_SD0), U6.5 (DI(IO0))
/MCU2_QSPI_SD1: U5.55 (QSPI_SD1), U6.2 (DO(IO1))
/MCU2_QSPI_SD2: U5.54 (QSPI_SD2), U6.3 (IO2)
/MCU2_QSPI_SD3: U5.51 (QSPI_SD3), U6.7 (IO3)
/MCU2_QSPI_SS: R14.2, R15.2, U5.56 (QSPI_SS), U6.1 (~CS)
/MCU2_RUN: U5.26 (RUN); also elsewhere on the board
/MCU2_SWCLK: U5.24 (SWCLK)
/MCU2_SWD: U5.25 (SWD)
/MCU2_USB_D+: J4.A6 (D+), J4.B6 (D+), R9.1
/MCU2_USB_D-: J4.A7 (D-), J4.B7 (D-), R10.1
/MCU2_XIN: C26.2, U5.20 (XIN), Y2.3
/MCU2_XOUT: C28.2, U5.21 (XOUT), Y2.1
/MUX_B_5: U1.28 (B5)
/MUX_B_6: U1.25 (B6)
/MUX_B_7: U1.24 (B7)
/MUX_COMMON_5: U1.10 (A5)
/MUX_COMMON_6: U1.11 (A6)
/MUX_COMMON_7: U1.12 (A7)
/MUX_C_5: U1.26 (C5)
/MUX_C_6: U1.23 (C6)
/MUX_C_7: U1.22 (C7)
/PICO_3v3_OUT: J2.2, J5.4 (VDD)
GND: C1.2, C2.2, C3.2, C4.2, C5.2, C6.2, C7.2, C8.2, C9.2, C10.2, C11.2, C12.2, C13.2, C14.2, C15.2, C16.2, C17.2, C18.2, C19.2, C20.2, C21.2, C22.2, C23.2, C24.2, C25.1, C26.1, C27.1, C28.1, CN1.A8, CN1.A13, CN1.A18, CN1.A21, CN1.A24, CN1.B8, CN1.B13, CN1.B18, CN1.B21, CN1.B24, J2.1, J3.A1 (GND), J3.A12 (GND), J3.B1 (GND), J3.B12 (GND), J4.A1 (GND), J4.A12 (GND), J4.B1 (GND), J4.B12 (GND), J5.6 (VSS), J5.9 (SHIELD), R4.2, R5.2, R8.1, R11.2, R12.2, R13.1, SW1.1 (A), SW2.1, SW3.1, U1.5 (PD), U1.43 (GND), U2.19 (TESTEN), U2.57 (GND), U3.1 (GND), U4.4 (GND), U5.19 (TESTEN), U5.57 (GND), U6.4 (GND), Y1.2, Y1.4, Y2.2, Y2.4; also elsewhere on the board
unnamed: J3.A5 (CC1), R4.1
unnamed: J3.B5 (CC2), R5.1
unnamed: J3.S1 (SHIELD), R8.2
unnamed: J4.A4 (VBUS), J4.A9 (VBUS), J4.B4 (VBUS), J4.B9 (VBUS)
unnamed: J4.A5 (CC1), R11.1
unnamed: J4.B5 (CC2), R12.1
unnamed: J4.S1 (SHIELD), R13.2
unnamed: R2.2, U2.47 (USB_DP)
unnamed: R3.2, U2.46 (USB_DM)
unnamed 121: R7.1, SW2.2; also elsewhere on the board
unnamed: R9.2, U5.47 (USB_DP)
unnamed: R10.2, U5.46 (USB_DM)
unnamed 124: R15.1, SW3.2; also elsewhere on the board
VBUS: C11.1, J3.A4 (VBUS), J3.A9 (VBUS), J3.B4 (VBUS), J3.B9 (VBUS), JP1.1 (A), U3.3 (VI)

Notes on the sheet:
(1.41MHz)
Reset the GDROM Drive?
RD (Read strobe signal from the host) At the falling edge of this signal, the data on the DDO- DD7, DD8-DD15 data bus from the device register or data port become valid. At the rising edge of this signal, the host latches on to the data. Until latching is completed, the host cannot access the data.
5v Open, 0v Close
(44.1kHz)
WR (Write strobe signal from the host) At the falling edge of this signal, the data on DDO- DD7, DD8-DD15 data bus from the device register or data port are latched. Until latching is completed, the device cannot access the data.
IORDY - Used to signal to host that device needs more time
Left right clock
Unused for the moment
ROM address[10:8]
SD Card
USE MCU1's POWER???
GDROM DEV BOARD
MCU2 Connections
MCU2 Flash
GD-ROM chip selection
Specifies the register and data read/write port.
Playback disc emphasis mode output (Outputs a high signal when the playback disc has emphasis, and a lot signal when there is no emphasis)
MCU1
MCU2
Breakouts
MCU1 USB connector
Bit clock
D[15:8] In/Out G1 data bus-highest 8bit (Adapted to ROM address [7:0])
MCU1 Connections
DMACK- (DMA acknowledge) (optional) This signal is used by the host in response to DMARQ, for initiating a DMA transfer. DMARQ- (DMA request) (optional) This signal is used for DMA transfer between the host and this device. When data transfer is possible, the device drives the signal. The data tran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
(audio data, serial)
MCU1 Flash
OUTPUTS?
GDROM Lid Switch
2023-04-20
INTRQ (Device interrupt) Serves for issuing an interrupt to the host. The INTRQ signal has a hold function which asserts the interrupt only when the device is selected and the host has cleared the nIEN bit in the device control register. When the nIEN bit is "1", or when the device is not selected,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
33.8688 MHz
Power Picos from Dreamcast
MCU2 USB connector
MCU1 MUX
D[0:15] Bidirectional data bus that can be used either as 8-bit or 16-bit bus.
IDE_CSO (Chip select 0) Serves for selecting the command block register. Note: This signal is known as "CS1FX-" in the industry. IDE_CS1(Chip select 1) Serves for selecting the control block register. Note: This signal is known as "CS3FX-" in the industry.
AICA Chip Clock
D[7:0] In/Out G1 data bus-lowest 8bit

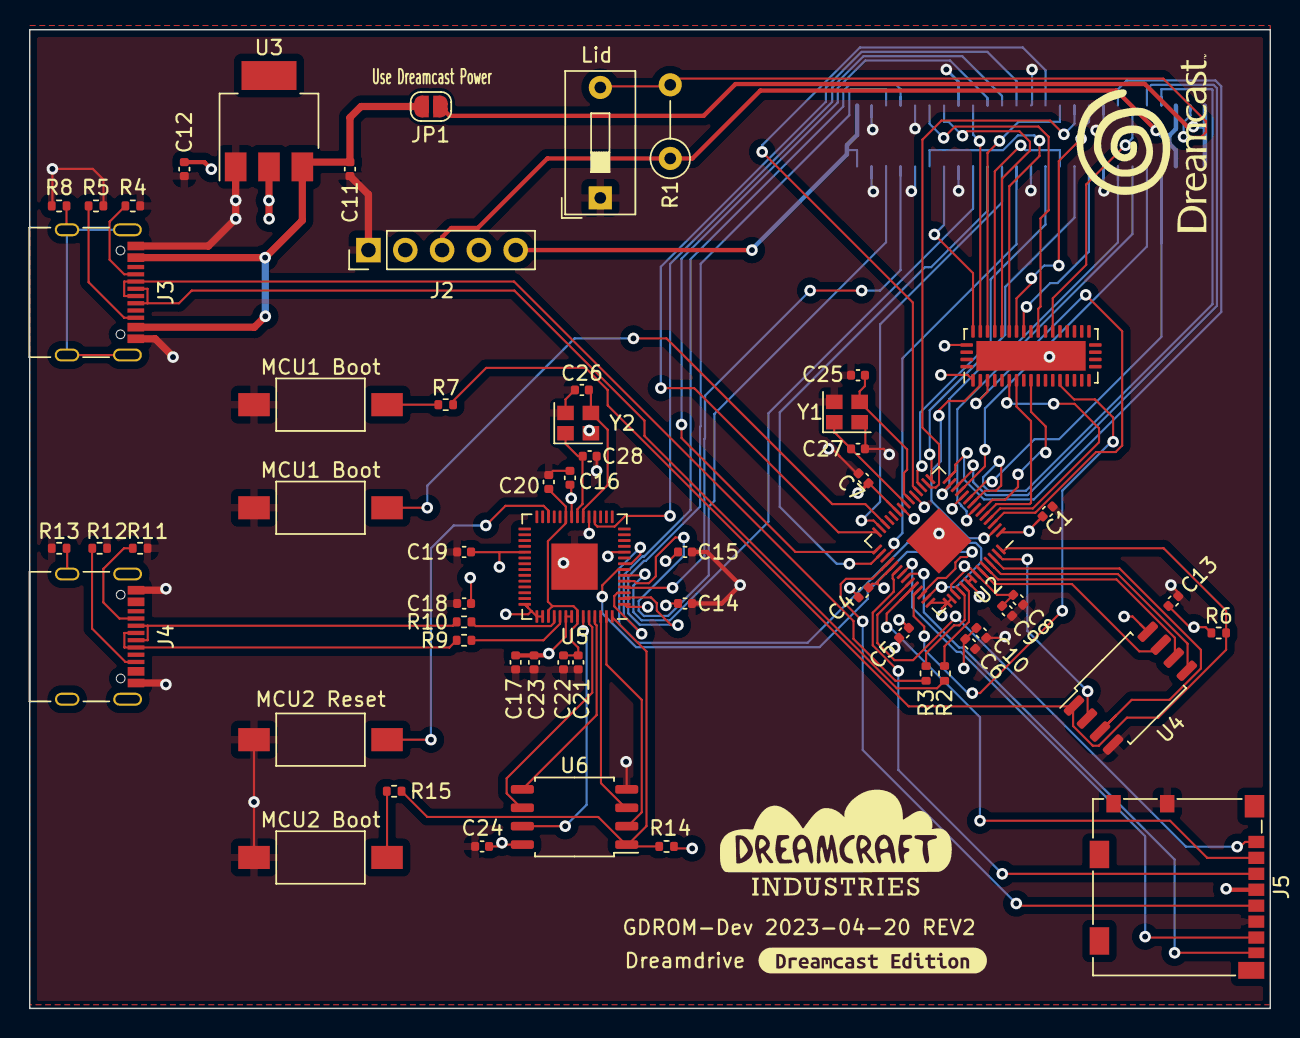
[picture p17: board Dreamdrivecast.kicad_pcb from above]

Board: 4 copper layers, 85.6 x 67.5 mm, 62 parts (1 on the bottom side), 90 nets.

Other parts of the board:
DREAMCRAFT_LOGO: LOGO
MCU1 Boot, MCU1 Boot#2, MCU2 Reset: MCU1_BOOT; SW_SPST_FSMSM
MCU2 Boot: MCU2_BOOT; SW_SPST_FSMSM
kibuzzard-63F149CE: DDR_DREAMCAST; kibuzzard-63F149CE

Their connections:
/MCU1_RUN: MCU1 Boot.2; also elsewhere on the board
/MCU2_RUN: MCU2 Reset.1; also elsewhere on the board
GND: MCU1 Boot.1, MCU1 Boot#2.1, MCU2 Boot.1, MCU2 Reset.2; also elsewhere on the board
unnamed 121: MCU1 Boot#2.2; also elsewhere on the board
unnamed 124: MCU2 Boot.2; also elsewhere on the board

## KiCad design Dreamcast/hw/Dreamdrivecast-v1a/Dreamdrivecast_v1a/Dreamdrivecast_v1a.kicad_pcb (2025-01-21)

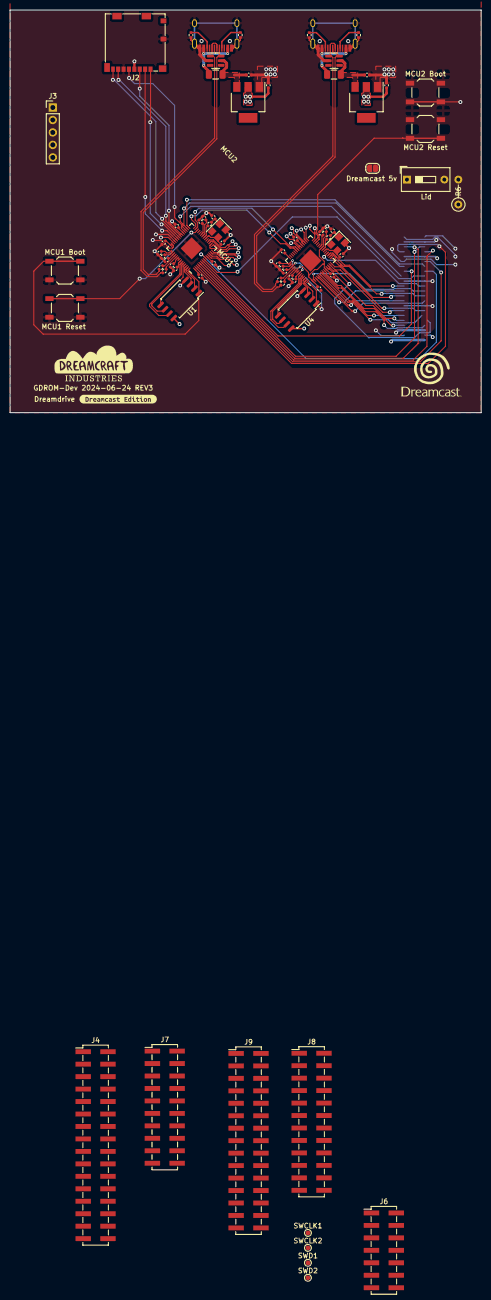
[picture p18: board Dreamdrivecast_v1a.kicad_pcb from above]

Board: 4 copper layers, 96.0 x 82.0 mm, 74 parts (1 on the bottom side), 98 nets.

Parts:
C1, C2, C5, C6, C7, C8, C9, C10, C11, C16, C17, C20, C21, C22, C23, C24, C25, C26: 100nF; C_0402_1005Metric
C3, C4, C15, C18, C19, C29, C30: 1uF; C_0402_1005Metric
C12, C13, C27, C28: 30pF; C_0402_1005Metric
DREAMCRAFT_LOGO: LOGO
Dreamcast: Molex_52602_0579
F1, F2: 1.1A; Fuse_1206_3216Metric
J1, J5: USB_C_Receptacle_USB2.0; HRO-TYPE-C-31-M-12_LCSC
J2: Micro_SD_Card; microSD_HC_Molex_104031-0811
J3: POWER; PinHeader_1x05_P2.54mm_Vertical
J4: Dreamcast Data; PinHeader_2x16_P2.54mm_Vertical_SMD
J6: Dreamcast Control Lines; PinHeader_2x07_P2.54mm_Vertical_SMD
J7: MCU Databus; PinHeader_2x10_P2.54mm_Vertical_SMD
J8: Dreamcast Misc; PinHeader_2x12_P2.54mm_Vertical_SMD
J9: MCU Misc; PinHeader_2x15_P2.54mm_Vertical_SMD
JP1: Dreamcast 5v; SolderJumper-2_P1.3mm_Open_RoundedPad1.0x1.5mm
Lid: Lid; SW_DIP_SPSTx01_Slide_9.78x4.72mm_W7.62mm_P2.54mm
MCU1, MCU2: RP2040; QFN-56-1EP_7x7mm_P0.4mm_EP3.2x3.2mm
MCU1 Boot, MCU1 Reset, MCU2 Boot, MCU2 Reset: SW_Push; SW_SPST_TL3342
R1, R2, R7, R8: 27; R_0402_1005Metric
R3, R9: 1K; R_0402_1005Metric
R4, R5, R10, R11: 5k1; R_0402_1005Metric
R6: R; R_Axial_DIN0207_L6.3mm_D2.5mm_P5.08mm_Vertical
SWCLK1, SWCLK2: Conn_01x01_Female; TestPoint_Pad_D1.0mm
SWD1, SWD2: Conn_01x01_Female; TestPoint_Pad_D1.0mm
U1, U4: W25Q128JVS; SOIC-8_5.23x5.23mm_P1.27mm
U2, U5: AMS1117-3.3; SOT-223
U3, U6: SRV05-4; SOT-23-6
Y1, Y2: Crystal_GND24; Crystal_SMD_3225-4Pin_3.2x2.5mm
kibuzzard-63F149CE: DDR_DREAMCAST; kibuzzard-63F149CE

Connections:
3.3V: C4.2, C5.2, C6.2, C7.2, C8.2, C9.2, C10.2, C11.2, C15.1, C19.2, C20.2, C21.2, C22.2, C23.2, C24.2, C25.2, C26.2, C30.1, J2.4 (VDD), J3.2, MCU1.1 (IOVDD), MCU1.10 (IOVDD), MCU1.22 (IOVDD), MCU1.33 (IOVDD), MCU1.42 (IOVDD), MCU1.43 (ADC_AVDD), MCU1.44 (VREG_IN), MCU1.48 (USB_VDD), MCU1.49 (IOVDD), MCU2.1 (IOVDD), MCU2.10 (IOVDD), MCU2.22 (IOVDD), MCU2.33 (IOVDD), MCU2.42 (IOVDD), MCU2.43 (ADC_AVDD), MCU2.44 (VREG_IN), MCU2.48 (USB_VDD), MCU2.49 (IOVDD), U1.8 (VCC), U2.2 (VO), U4.8 (VCC), U5.2 (VO)
5V: C29.1, F1.1, F2.1, JP1.1 (A), U2.3 (VI), U3.5 (VP), U5.3 (VI), U6.5 (VP)
/A0: Dreamcast.A19, J6.1, MCU1.2 (GPIO0)
/A1: Dreamcast.B17, J6.2, MCU1.3 (GPIO1)
/A2: Dreamcast.B19, J6.3, MCU1.4 (GPIO2)
/CD_BCK: Dreamcast.A22, J8.6
/CD_EMPH: Dreamcast.A17, J8.11
/CD_LRCK: Dreamcast.B22, J8.5
/CD_SDAT: Dreamcast.A23, J8.7
/CS0: Dreamcast.A20, MCU1.5 (GPIO3)
/CS1: Dreamcast.B20, MCU1.6 (GPIO4)
/D0: Dreamcast.B11, J4.1, MCU2.2 (GPIO0)
/D1: Dreamcast.A11, J4.2, MCU2.3 (GPIO1)
/D2: Dreamcast.B9, J4.3, MCU2.4 (GPIO2)
/D3: Dreamcast.A9, J4.4, MCU2.5 (GPIO3)
/D4: Dreamcast.B6, J4.5, MCU2.6 (GPIO4)
/D5: Dreamcast.A6, J4.6, MCU2.7 (GPIO5)
/D6: Dreamcast.B4, J4.7, MCU2.8 (GPIO6)
/D7: Dreamcast.A4, J4.8, MCU2.9 (GPIO7)
/D8: Dreamcast.A5, J4.9, MCU2.11 (GPIO8)
/D9: Dreamcast.B5, J4.10, MCU2.12 (GPIO9)
/D10: Dreamcast.A7, J4.11, MCU2.13 (GPIO10)
/D11: Dreamcast.B7, J4.12, MCU2.14 (GPIO11)
/D12: Dreamcast.A10, J4.13, MCU2.15 (GPIO12)
/D13: Dreamcast.B10, J4.14, MCU2.16 (GPIO13)
/D14: Dreamcast.A12, J4.15, MCU2.17 (GPIO14)
/D15: Dreamcast.B12, J4.16, MCU2.18 (GPIO15)
/DATABUS_D0: J7.1, MCU1.11 (GPIO8), MCU2.27 (GPIO16)
/DATABUS_D1: J7.2, MCU1.12 (GPIO9), MCU2.28 (GPIO17)
/DATABUS_D2: J7.3, MCU1.13 (GPIO10), MCU2.29 (GPIO18)
/DATABUS_D3: J7.4, MCU1.14 (GPIO11), MCU2.30 (GPIO19)
/DATABUS_D4: J7.5, MCU1.15 (GPIO12), MCU2.31 (GPIO20)
/DATABUS_D5: J7.6, MCU1.16 (GPIO13), MCU2.32 (GPIO21)
/DATABUS_D6: J7.7, MCU1.17 (GPIO14), MCU2.34 (GPIO22)
/DATABUS_D7: J7.8, MCU1.18 (GPIO15), MCU2.35 (GPIO23)
/DATABUS_SIGNAL_READ: J7.9, MCU1.27 (GPIO16), MCU2.36 (GPIO24)
/DATABUS_SIGNAL_WRITE: J7.10, MCU1.28 (GPIO17), MCU2.37 (GPIO25)
/DMACK: Dreamcast.A16, J8.4, MCU1.30 (GPIO19)
/DMARQ: Dreamcast.A14, J8.3, MCU1.31 (GPIO20)
/DOPEN: Dreamcast.B2, J8.8, Lid.2 (B), R6.2
/INTRQ: Dreamcast.B16, J8.2, MCU1.29 (GPIO18)
/IORDY: Dreamcast.B15, J8.1, MCU1.9 (GPIO7)
/MCU1_GPIO27: J9.7, MCU1.39 (GPIO27_ADC1)
/MCU1_GPIO28: J9.8, MCU1.40 (GPIO28_ADC2)
/MCU1_GPIO29: J9.9, MCU1.41 (GPIO29_ADC3)
/MCU2_GPIO26: J9.10, MCU2.38 (GPIO26_ADC0)
/MCU2_GPIO27: J9.11, MCU2.39 (GPIO27_ADC1)
/MCU2_GPIO28: J9.12, MCU2.40 (GPIO28_ADC2)
/MCU2_GPIO29: J9.13, MCU2.41 (GPIO29_ADC3)
/RD: Dreamcast.A15, J6.4, MCU1.7 (GPIO5)
/SD_CLK: J2.5 (CLK), J9.1, MCU1.32 (GPIO21)
/SD_CMD: J2.3 (CMD), J9.2, MCU1.34 (GPIO22)
/SD_DAT0: J2.7 (DAT0), J9.3, MCU1.35 (GPIO23)
/SD_DAT1: J2.8 (DAT1), J9.4, MCU1.36 (GPIO24)
/SD_DAT2: J2.1 (DAT2), J9.5, MCU1.37 (GPIO25)
/SD_DAT3: J2.2 (DAT3/CD), J9.6, MCU1.38 (GPIO26_ADC0)
/WR: Dreamcast.B14, J6.5, MCU1.8 (GPIO6)
Dreamcast_3v3: Dreamcast.A1, Dreamcast.B1, J3.4, JP1.2 (B)
Dreamcast_5V: Dreamcast.A3, Dreamcast.B3, J3.3
Dreamcast_12V: Dreamcast.A25, Dreamcast.B25, J3.5
GND: C1.1, C2.1, C3.1, C4.1, C5.1, C6.1, C7.1, C8.1, C9.1, C10.1, C11.1, C12.2, C13.2, C15.2, C16.1, C17.1, C18.1, C19.1, C20.1, C21.1, C22.1, C23.1, C24.1, C25.1, C26.1, C27.2, C28.2, C29.2, C30.2, Dreamcast.A8, Dreamcast.A13, Dreamcast.A18, Dreamcast.A21, Dreamcast.A24, Dreamcast.B8, Dreamcast.B13, Dreamcast.B18, Dreamcast.B21, Dreamcast.B24, J1.A1 (GND), J1.A12 (GND), J1.B1 (GND), J1.B12 (GND), J1.S1 (SHIELD), J2.6 (VSS), J2.9 (SHIELD), J3.1, J4.17, J4.18, J4.19, J4.20, J4.21, J4.22, J4.23, J4.24, J4.25, J4.26, J4.27, J4.28, J4.29, J4.30, J4.31, J4.32, J5.A1 (GND), J5.A12 (GND), J5.B1 (GND), J5.B12 (GND), J5.S1 (SHIELD), J6.8, J6.9, J6.10, J6.11, J6.12, J6.13, J6.14, J7.11, J7.12, J7.13, J7.14, J7.15, J7.16, J7.17, J7.18, J7.19, J7.20, J8.12, J8.13, J8.14, J8.15, J8.16, J8.17, J8.18, J8.19, J8.20, J8.21, J8.22, J9.15, J9.16, J9.17, J9.18, J9.19, J9.20, J9.21, J9.22, J9.23, J9.24, J9.25, J9.26, J9.27, J9.28, Lid.1 (A), MCU1.19 (TESTEN), MCU1.57 (GND), MCU1 Boot.2, MCU1 Reset.2, MCU2.19 (TESTEN), MCU2.57 (GND), MCU2 Boot.2, MCU2 Reset.2, R4.1, R5.1, R10.1, R11.1, U1.4 (GND), U2.1 (GND), U3.2 (VN), U4.4 (GND), U5.1 (GND), U6.2 (VN), Y1.2, Y1.4, Y2.2, Y2.4
unnamed: C13.1, R3.2, Y1.1
unnamed: C28.1, R9.2, Y2.1
unnamed: F1.2, F2.2, J1.A4 (VBUS), J1.A9 (VBUS), J1.B4 (VBUS), J1.B9 (VBUS), J5.A4 (VBUS), J5.A9 (VBUS), J5.B4 (VBUS), J5.B9 (VBUS)
unnamed: J1.A5 (CC1), J5.A5 (CC1), R5.2, R11.2
unnamed: J1.B5 (CC2), J5.B5 (CC2), R4.2, R10.2
unnamed: MCU1.24 (SWCLK), SWCLK1.1
unnamed: MCU1.25 (SWD), SWD1.1
unnamed: MCU1.46 (USB_DM), R2.1
unnamed: MCU1.47 (USB_DP), R1.1
unnamed: C1.2, C2.2, C3.2, MCU1.23 (DVDD), MCU1.45 (VREG_VOUT), MCU1.50 (DVDD)
unnamed: C12.1, MCU1.20 (XIN), Y1.3
unnamed: MCU1.21 (XOUT), R3.1
unnamed: MCU2.24 (SWCLK), SWCLK2.1
unnamed: MCU2.25 (SWD), SWD2.1
unnamed: MCU2.46 (USB_DM), R8.1
unnamed: MCU2.47 (USB_DP), R7.1
unnamed: C16.2, C17.2, C18.2, MCU2.23 (DVDD), MCU2.45 (VREG_VOUT), MCU2.50 (DVDD)
unnamed: C27.1, MCU2.20 (XIN), Y2.3
unnamed: MCU2.21 (XOUT), R9.1
RP1_CLK: MCU1.52 (QSPI_SCLK), U1.6 (CLK)
RP1_CS: MCU1.56 (QSPI_SS), MCU1 Boot.1, U1.1 (~CS)
RP1_RUN_PULL: MCU1.26 (RUN), MCU1 Reset.1
RP1_SD0: MCU1.53 (QSPI_SD0), U1.5 (DI(IO0))
RP1_SD1: MCU1.55 (QSPI_SD1), U1.2 (DO(IO1))
RP1_SD2: MCU1.54 (QSPI_SD2), U1.3 (IO2)
RP1_SD3: MCU1.51 (QSPI_SD3), U1.7 (IO3)
RP1_USB_D+: J1.A6 (D+), J1.B6 (D+), R1.2, U3.1 (IO1)
RP1_USB_D-: J1.A7 (D-), J1.B7 (D-), R2.2, U3.6 (IO4)
RP2_CLK: MCU2.52 (QSPI_SCLK), U4.6 (CLK)
RP2_CS: MCU2.56 (QSPI_SS), MCU2 Boot.1, U4.1 (~CS)
RP2_RUN_PULL: MCU2.26 (RUN), MCU2 Reset.1
RP2_SD0: MCU2.53 (QSPI_SD0), U4.5 (DI(IO0))
RP2_SD1: MCU2.55 (QSPI_SD1), U4.2 (DO(IO1))
RP2_SD2: MCU2.54 (QSPI_SD2), U4.3 (IO2)
RP2_SD3: MCU2.51 (QSPI_SD3), U4.7 (IO3)
RP2_USB_D+: J5.A6 (D+), J5.B6 (D+), R7.2, U6.1 (IO1)
RP2_USB_D-: J5.A7 (D-), J5.B7 (D-), R8.2, U6.6 (IO4)

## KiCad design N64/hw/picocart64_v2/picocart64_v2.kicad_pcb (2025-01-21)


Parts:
C1, C2, C3, C4, C5, C6, C7, C8, C9: 100n; C_0402_1005Metric
C39, C40, C41, C42, C43, C44, C45, C46, C47: 1u; C_0402_1005Metric
R1, R2, R62: 10K; R_0402_1005Metric
U1, U2, U3, U4, U5, U6, U7, U8: APS6404L-3SQR; SOP-8_3.76x4.96mm_P1.27mm
U9: SN74LVC138AQDRQ1; SOP-16_4.4x10.4mm_P1.27mm
U10: W25Q128JVS; SOIC-8_5.23x5.23mm_P1.27mm
U11: 74LVC1G125GW; SOT-353_SC-70-5

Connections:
+3V3: C1.1, C2.1, C3.1, C4.1, C5.1, C6.1, C7.1, C8.1, C9.1, C39.1, C40.1, C41.1, C42.1, C43.1, C44.1, C45.1, C46.1, C47.1, R1.1, R62.2, U1.8 (VCC), U2.8 (VCC), U3.8 (VCC), U4.8 (VCC), U5.8 (VCC), U6.8 (VCC), U7.8 (VCC), U8.8 (VCC), U9.16 (VCC), U10.8 (VCC), U11.5 (VCC); also elsewhere on the board
/Mainboard/DEMUX_A0: U9.1 (A0); also elsewhere on the board
/Mainboard/DEMUX_A1: U9.2 (A1); also elsewhere on the board
/Mainboard/DEMUX_A2: U9.3 (A2); also elsewhere on the board
/Mainboard/DEMUX_IE: R2.2, U9.6 (E3), U11.1 (~OE); also elsewhere on the board
/Mainboard/SSI_SCLK: U1.6 (SCLK), U2.6 (SCLK), U3.6 (SCLK), U4.6 (SCLK), U5.6 (SCLK), U6.6 (SCLK), U7.6 (SCLK), U8.6 (SCLK), U10.6 (CLK); also elsewhere on the board
/Mainboard/SSI_SD0: U1.5 (SI/SIO), U2.5 (SI/SIO), U3.5 (SI/SIO), U4.5 (SI/SIO), U5.5 (SI/SIO), U6.5 (SI/SIO), U7.5 (SI/SIO), U8.5 (SI/SIO), U10.5 (DI(IO0)); also elsewhere on the board
/Mainboard/SSI_SD1: U1.2 (SO/SIO), U2.2 (SO/SIO), U3.2 (SO/SIO), U4.2 (SO/SIO), U5.2 (SO/SIO), U6.2 (SO/SIO), U7.2 (SO/SIO), U8.2 (SO/SIO), U10.2 (DO(IO1)); also elsewhere on the board
/Mainboard/SSI_SD2: U1.3 (SIO2), U2.3 (SIO2), U3.3 (SIO2), U4.3 (SIO2), U5.3 (SIO2), U6.3 (SIO2), U7.3 (SIO2), U8.3 (SIO2), U10.3 (IO2); also elsewhere on the board
/Mainboard/SSI_SD3: U1.7 (SIO3), U2.7 (SIO3), U3.7 (SIO3), U4.7 (SIO3), U5.7 (SIO3), U6.7 (SIO3), U7.7 (SIO3), U8.7 (SIO3), U10.7 (IO3); also elsewhere on the board
/PSRAM Array/CS1: U1.1 (~CE), U9.15 (O0)
/PSRAM Array/CS2: U2.1 (~CE), U9.14 (O1)
/PSRAM Array/CS3: U3.1 (~CE), U9.13 (O2)
/PSRAM Array/CS4: U4.1 (~CE), U9.12 (O3)
/PSRAM Array/CS5: U5.1 (~CE), U9.11 (O4)
/PSRAM Array/CS6: U6.1 (~CE), U9.10 (O5)
/PSRAM Array/CS7: U7.1 (~CE), U9.9 (O6)
/PSRAM Array/CS8: U8.1 (~CE), U9.7 (O7)
/PSRAM Array/CSBOOT: R62.1, U10.1 (~CS), U11.4 (Y)
GND: C1.2, C2.2, C3.2, C4.2, C5.2, C6.2, C7.2, C8.2, C9.2, C39.2, C40.2, C41.2, C42.2, C43.2, C44.2, C45.2, C46.2, C47.2, R2.1, U1.4 (VSS), U2.4 (VSS), U3.4 (VSS), U4.4 (VSS), U5.4 (VSS), U6.4 (VSS), U7.4 (VSS), U8.4 (VSS), U9.8 (GND), U10.4 (GND), U11.3 (GND); also elsewhere on the board
~SSI_CS: R1.2, U9.4 (E1), U9.5 (E2), U11.2 (A); also elsewhere on the board

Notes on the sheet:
TODO: Double-check footprint!
IE = Input Enable => E3 E3=0 All CS will be driven high, except boot flash: boot flash will be allowed to pull down when hardware CS is also low E3=1 Only the decoded CS will be driven low. E.g. A[2:0] = 3'b011 -> CS3 = 0 E.g. A[2:0] = 3'b000 -> CS0 = 0
SN74LVC138AQDRQ1 or MC74AC138DR2G


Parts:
C10, C13, C14: 10u; C_0603_1608Metric
C11, C12, C27, C28: 12p; C_0402_1005Metric
C15, C16, C17, C18, C19, C20, C22, C23, C26, C29, C30, C31, C32, C33, C34, C36, C37, C48, C49, C50, C51, C52, C53, C54, C55, C56, C57: 100n; C_0402_1005Metric
C21, C24, C25, C35, C38: 1u; C_0402_1005Metric
D1: WS2812B-2020
D2: WS2812B; LED_WS2812B_PLCC4_5.0x5.0mm_P3.2mm
D3: DRTR5V0U2SR-7; SOT-143; LCSC C443828
D4: D_Small; D_SMA; LCSC C22452
FB1: Ferrite; L_0603_1608Metric
J1: USB_C_Receptacle_USB2.0; USB_C_Receptacle_GT-USB-7010
J2: Conn_02x06_Odd_Even; PinHeader_2x06_P2.54mm_Vertical_SMD
J3: Micro_SD_Card_Det; microSD_HC_Molex_104031-0811
JP1: SolderJumper_2_Open; SolderJumper-2_Small_Open
JP2, JP3: SolderJumper_2_Bridged; SolderJumper-2_Small_Closed
Q1, Q2: FDN340P; SOT-23; LCSC C347510
R3: 100k; R_0402_1005Metric
R4, R5, R6, R7, R8, R9, R10, R11, R12, R13, R14, R15, R16, R20, R21, R22, R23, R24, R25, R26, R27, R28, R29, R30, R31, R32, R35, R36: 22R; R_0402_1005Metric
R17, R18: 5k1; R_0402_1005Metric
R19, R37, R38, R41: 10k; R_0402_1005Metric
R33, R34: 10K; R_0402_1005Metric
R39: 1K; R_0402_1005Metric
R40: 470R; R_0402_1005Metric
R42, R43, R44, R45, R46, R47, R48, R49, R50, R51, R52, R53, R54, R55, R56, R57, R58, R59, R60, R61: R; R_0402_1005Metric
SW1: BootButton; SW_SPST_FSMSM
SW2: ResetButton; SW_SPST_FSMSM
TP1: TP_MCU2_SCK; TestPoint_Pad_D1.0mm
TP2: TP_MCU2_CS; TestPoint_Pad_D1.0mm
TP3: TP_MCU2_DIO; TestPoint_Pad_D1.0mm
U13: AZ1117-3.3; SOT-223
U14: N64-Cartridge; N64-Connector
U15, U16: RP2040; QFN-56_EP_7x7_Pitch0.4mm
U17: ESP32-C3-WROOM-02
Y1, Y2: 12MHz 10ppm; Crystal_SMD_2520-4Pin_2.5x2.0mm; LCSC C521567

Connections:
+3V3: C13.1, C14.1, C15.1, C16.1, C17.1, C18.1, C19.1, C20.1, C21.1, C25.1, C26.1, C29.1, C30.1, C31.1, C32.1, C33.1, C34.1, C35.1, C48.1, C49.1, C50.1, C51.1, C52.1, C53.1, C54.1, C55.1, C56.1, C57.1, D1.4 (VDD), D2.1 (VDD), J2.11, J3.4 (VDD), Q2.2 (S), R34.2, R38.1, R41.1, R42.2, R43.2, R46.2, R47.2, R50.2, R51.2, R54.2, R55.2, R58.2, R59.2, U13.2 (VO), U15.1 (IOVDD), U15.10 (IOVDD), U15.22 (IOVDD), U15.33 (IOVDD), U15.42 (IOVDD), U15.43 (ADC_AVDD), U15.44 (VREG_VIN), U15.48 (USB_VDD), U15.49 (IOVDD), U16.1 (IOVDD), U16.10 (IOVDD), U16.22 (IOVDD), U16.33 (IOVDD), U16.42 (IOVDD), U16.43 (ADC_AVDD), U16.44 (VREG_VIN), U16.48 (USB_VDD), U16.49 (IOVDD), U17.1 (3V3); also elsewhere on the board
/Mainboard/AD0: R20.2, U15.2 (GPIO0)
/Mainboard/AD0': R20.1, U14.28 (AD0)
/Mainboard/AD1: R21.2, U15.3 (GPIO1)
/Mainboard/AD1': R21.1, U14.29 (AD1)
/Mainboard/AD2: R22.2, U15.4 (GPIO2)
/Mainboard/AD2': R22.1, U14.30 (AD2)
/Mainboard/AD3: R23.2, U15.5 (GPIO3)
/Mainboard/AD3': R23.1, U14.32 (AD3)
/Mainboard/AD4: R26.2, U15.6 (GPIO4)
/Mainboard/AD4': R26.1, U14.36 (AD4)
/Mainboard/AD5: R27.2, U15.7 (GPIO5)
/Mainboard/AD5': R27.1, U14.37 (AD5)
/Mainboard/AD6: R29.2, U15.8 (GPIO6)
/Mainboard/AD6': R29.1, U14.40 (AD6)
/Mainboard/AD7: R28.2, U15.9 (GPIO7)
/Mainboard/AD7': R28.1, U14.41 (AD7)
/Mainboard/AD8: R14.1, U15.11 (GPIO8)
/Mainboard/AD8': R14.2, U14.16 (AD8)
/Mainboard/AD9: R13.1, U15.12 (GPIO9)
/Mainboard/AD9': R13.2, U14.15 (AD9)
/Mainboard/AD10: R12.1, U15.13 (GPIO10)
/Mainboard/AD10': R12.2, U14.12 (AD10)
/Mainboard/AD11: R11.1, U15.14 (GPIO11)
/Mainboard/AD11': R11.2, U14.11 (AD11)
/Mainboard/AD12: R8.1, U15.15 (GPIO12)
/Mainboard/AD12': R8.2, U14.7 (AD12)
/Mainboard/AD13: R7.1, U15.16 (GPIO13)
/Mainboard/AD13': R7.2, U14.5 (AD13)
/Mainboard/AD14: R6.1, U15.17 (GPIO14)
/Mainboard/AD14': R6.2, U14.4 (AD14)
/Mainboard/AD15: R5.1, U15.18 (GPIO15)
/Mainboard/AD15': R5.2, U14.3 (AD15)
/Mainboard/ALEH: R25.2, U15.28 (GPIO17)
/Mainboard/ALEH': R25.1, U14.35 (ALEH)
/Mainboard/ALEL: R24.2, U15.27 (GPIO16)
/Mainboard/ALEL': R24.1, U14.33 (ALEL)
/Mainboard/CIC_DCLK: R30.2, U16.37 (GPIO25)
/Mainboard/CIC_DCLK': R30.1, U14.43 (CIC_DCLK)
/Mainboard/CIC_DIO: R15.1, U16.36 (GPIO24)
/Mainboard/CIC_DIO': R15.2, U14.18 (CIC_DIO)
/Mainboard/DEMUX_A0: U15.35 (GPIO23), U16.18 (GPIO15); also elsewhere on the board
/Mainboard/DEMUX_A1: U15.36 (GPIO24), U16.27 (GPIO16); also elsewhere on the board
/Mainboard/DEMUX_A2: U15.37 (GPIO25), U16.28 (GPIO17); also elsewhere on the board
/Mainboard/DEMUX_IE: U15.38 (GPIO26), U16.29 (GPIO18); also elsewhere on the board
/Mainboard/ESP32_CS: U16.15 (GPIO12), U17.16 (GPIO2/ADC1_CH2)
/Mainboard/ESP32_D0_TX: JP2.2 (B), U16.11 (GPIO8)
/Mainboard/ESP32_D1_RX: JP3.2 (B), U16.12 (GPIO9)
/Mainboard/ESP32_D2_G9: U16.13 (GPIO10), U17.8 (GPIO9)
/Mainboard/ESP32_D3: U16.14 (GPIO11), U17.10 (GPIO10)
/Mainboard/ESP32_EN: R37.2, U16.17 (GPIO14), U17.2 (EN/CHIP_PU)
/Mainboard/ESP32_SCK: U16.16 (GPIO13), U17.7 (GPIO8)
/Mainboard/LED: D1.3 (DIN), D2.4 (DIN), U16.31 (GPIO20)
/Mainboard/MCU1_RUN: J2.10, R33.2, U15.26 (RUN), U16.30 (GPIO19)
/Mainboard/MCU1_SWCLK: J2.8, U15.24 (SWCLK)
/Mainboard/MCU1_SWDIO: J2.6, U15.25 (SWDIO)
/Mainboard/MCU1_XIN: C11.2, JP1.2 (B), U15.20 (XIN), Y1.3
/Mainboard/MCU1_XOUT: C12.2, U15.21 (XOUT), Y1.1
/Mainboard/MCU2_CS: J2.4, R34.1, TP2.1, U15.40 (GPIO28), U16.41 (GPIO29)
/Mainboard/MCU2_DIO: R40.2, TP3.1, U15.41 (GPIO29), U16.40 (GPIO28)
/Mainboard/MCU2_G27: R40.1, U16.39 (GPIO27)
/Mainboard/MCU2_GPIO21: J2.2, JP1.1 (A), U16.32 (GPIO21)
/Mainboard/MCU2_RUN: J2.9, R38.2, SW2.1, U16.26 (RUN)
/Mainboard/MCU2_SCK: R41.2, TP1.1, U15.39 (GPIO27), U16.38 (GPIO26)
/Mainboard/MCU2_SWCLK: J2.7, U16.24 (SWCLK)
/Mainboard/MCU2_SWDIO: J2.5, U16.25 (SWDIO)
/Mainboard/MCU2_UART_RX: J2.1, U16.3 (GPIO1)
/Mainboard/MCU2_UART_TX: J2.3, U16.2 (GPIO0)
/Mainboard/MCU2_USB_D+: D3.3 (I/O2), J1.A6 (D+), J1.B6 (D+), R36.1
/Mainboard/MCU2_USB_D-: D3.2 (I/O1), J1.A7 (D-), J1.B7 (D-), R35.1
/Mainboard/MCU2_XIN: C27.2, U16.20 (XIN), Y2.3
/Mainboard/MCU2_XOUT: C28.2, U16.21 (XOUT), Y2.1
/Mainboard/N64_VCC: Q1.2 (S), U14.9 (VCC), U14.17 (VCC), U14.34 (VCC), U14.42 (VCC)
/Mainboard/SD_CLK: J3.5 (CLK), U16.4 (GPIO2)
/Mainboard/SD_CMD: J3.3 (CMD), U16.5 (GPIO3)
/Mainboard/SD_DAT0: J3.7 (DAT0), U16.6 (GPIO4)
/Mainboard/SD_DAT1: J3.8 (DAT1), U16.7 (GPIO5)
/Mainboard/SD_DAT2: J3.1 (DAT2), U16.8 (GPIO6)
/Mainboard/SD_DAT3: J3.2 (DAT3/CD), U16.9 (GPIO7)
/Mainboard/SD_DET: J3.10 (DET_A)
/Mainboard/SI_DAT: R4.1, U15.32 (GPIO21)
/Mainboard/SI_DAT': R4.2, U14.21 (SI_DAT)
/Mainboard/SSI_SCLK: R42.1, R43.1, R44.2, R45.2, U15.52 (QSPI_SCLK), U16.52 (QSPI_SCLK); also elsewhere on the board
/Mainboard/SSI_SD0: R46.1, R47.1, R48.2, R49.2, U15.53 (QSPI_SD0), U16.53 (QSPI_SD0); also elsewhere on the board
/Mainboard/SSI_SD1: R50.1, R51.1, R52.2, R53.2, U15.55 (QSPI_SD1), U16.55 (QSPI_SD1); also elsewhere on the board
/Mainboard/SSI_SD2: R54.1, R55.1, R56.2, R57.2, U15.54 (QSPI_SD2), U16.54 (QSPI_SD2); also elsewhere on the board
/Mainboard/SSI_SD3: R58.1, R59.1, R60.2, R61.2, U15.51 (QSPI_SD3), U16.51 (QSPI_SD3); also elsewhere on the board
/Mainboard/VBUS': FB1.1, J1.A4 (VBUS), J1.A9 (VBUS), J1.B4 (VBUS), J1.B9 (VBUS)
/Mainboard/~COLD_RESET': R16.2, U14.20 (~COLD_RESET)
/Mainboard/~COLD_RESET: R16.1, U15.31 (GPIO20), U16.34 (GPIO22)
/Mainboard/~INT1': R31.1, U14.44 (~INT1)
/Mainboard/~INT1: R31.2, U15.34 (GPIO22)
/Mainboard/~NMI': R32.1, U14.45 (~NMI)
/Mainboard/~NMI: R32.2, U16.35 (GPIO23)
/Mainboard/~READ': R10.2, U14.10 (~READ)
/Mainboard/~READ: R10.1, U15.30 (GPIO19)
/Mainboard/~WRITE': R9.2, U14.8 (~WRITE)
/Mainboard/~WRITE: R9.1, U15.29 (GPIO18)
GND: C10.2, C11.1, C12.1, C13.2, C14.2, C15.2, C16.2, C17.2, C18.2, C19.2, C20.2, C21.2, C22.2, C23.2, C24.2, C25.2, C26.2, C27.1, C28.1, C29.2, C30.2, C31.2, C32.2, C33.2, C34.2, C35.2, C36.2, C37.2, C38.2, C48.2, C49.2, C50.2, C51.2, C52.2, C53.2, C54.2, C55.2, C56.2, C57.2, D1.2 (VSS), D2.3 (VSS), D3.1 (GND), J1.A1 (GND), J1.A12 (GND), J1.B1 (GND), J1.B12 (GND), J2.12, J3.6 (VSS), J3.9 (DET_B), J3.11 (SHIELD), R3.1, R17.2, R18.2, R19.1, R33.1, R37.1, R44.1, R45.1, R48.1, R49.1, R52.1, R53.1, R56.1, R57.1, R60.1, R61.1, SW1.2, SW2.2, U13.1 (GND), U14.1 (GND), U14.2 (GND), U14.6 (GND), U14.22 (GND), U14.23 (GND), U14.25 (GND), U14.26 (GND), U14.27 (GND), U14.31 (GND), U14.47 (GND), U14.48 (GND), U14.50 (GND), U15.19 (TESTEN), U15.57 (GND), U16.19 (TESTEN), U16.57 (GND), U17.9 (GND), U17.19 (GND), Y1.2, Y1.4, Y2.2, Y2.4; also elsewhere on the board
unnamed: C22.1, C23.1, C24.1, U15.23 (DVDD), U15.45 (VREG_VOUT), U15.50 (DVDD)
unnamed: C36.1, C37.1, C38.1, U16.23 (DVDD), U16.45 (VREG_VOUT), U16.50 (DVDD)
unnamed: D3.4 (VCC), D4.1 (K), U13.3 (VI)
unnamed: J1.A5 (CC1), R17.1
unnamed: J1.B5 (CC2), R18.1
unnamed: J1.S1 (SHIELD), R3.2
unnamed: JP2.1 (A), U17.11 (GPIO20/U0RXD)
unnamed: JP3.1 (A), U17.12 (GPIO21/U0TXD)
unnamed: Q1.3 (D), Q2.3 (D)
unnamed: R35.2, U16.46 (USB_D-)
unnamed: R36.2, U16.47 (USB_D+)
unnamed: R39.2, SW1.1
VBUS: C10.1, D4.2 (A), FB1.2, Q1.1 (G), Q2.1 (G), R19.2
~SSI_CS: R39.1, U15.56 (~QSPI_CS), U16.56 (~QSPI_CS); also elsewhere on the board

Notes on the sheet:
[UART0_TX]
[PIO0_IO2]
[Pulled Up]
[clk_gpout0]
UART1_TX
[MCU1_UART0_RX -> MCU2_TX]
NOTE: MCU2 will drive pin high
[Pulled Down]
Strong pull
[UART0_RX]
MCU2 Handles ESP32, SDCard
FDN340P is rated for 2A Prevent N64_VCC to feed into LDO Prevent 3V3_USB to feed into N64_VCC If both are connected, pick 3V3_USB
Optional ESD protection PUSB3TB6
NOTE: Only place one of the LEDs whichever you have in stock.
[PIO#1]
Compatible with many LDOs
UART1_RX
BOM Optimization MCU2 CLK out replaces Xtal
Some Thevenin terminating resistor pads near each MCU are useful if we need to improve signal integrity at high QSPI clocks
[SPI1_SCK]
[SPI0_TX/MOSI/PIO0_IO0]
MCU1/MCU2 boot sequence ------------------------ GPIO26 used to identify MCU1/MCU2 MCU1: Low (pulled down by DEMUX_IE) MCU2: High (pulled high by MCU2_SCK)
[SPI0_SCK]
Either use SPI0 with custom CS pin, or do QSPI with PIO
[MCU1_UART_TX]
[SPI1_TX]
[MCU1_UART0_TX -> MCU2_RX]
[SPI1_RX]
ERC Note: SSI_SCLK is driven from multuple sources and it's OK.
MCU2 USB connector
[PIO0_IO3]
[PIO#2]
Optional ESD protection
MCU1 <-> MCU2 communication 1. Backup solution, use SPI (PIO on MCU1, SPI slave on MCU2) 2. Backup solution, use UART MCU2_CS might function as MCU1_INT.
Reset
[SPI0_RX/MISO/PIO0_IO1]
Pulled Down, powered down by default
MCU1 Handles the N64_BUS
[gpio_CSn/PIO0_IO4]
[SPI1_CSn]


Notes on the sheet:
MCU1_RUN
Alternative demux sn74lvc138a-q1
4 DIO, 1 SCK PSRAM * 8
16+2+2 = 20
1 ESP32_EN
0 UART [reuse QSPI pins]
PSRAM alternative to ly68l6400slit: APS6404L-3SQR-SN
0 ESP32_GP9/ROMBL [reuse QSPI pins]
MCU1 Pin Count = 30 20+1+1+1+2+1+1+3
2 (DIO, SCK) Master
Shared SSI/XIP/QSPI bus
MCU2 Clock output
Wifi Module, ESP32-C3
Boot Button
N64_COLD_RESET
WS2812 LED
BOOT
N64_NMI
MCU2
SD-Card
USB connector
3-bit 8 out demux
RP2040 internal SRAM = 264 kB
8*CS (w/pull-ups)
N64_BUS
Small Flash
RUN (w/pull-down)
demux_IE
--- PSRAM Architecture --- MCU1, MCU2 and all PSRAMs are connected to SSI. Both can read/write. MCU1 and MCU2 are connected to a 3-bit, 8 output demux + IE pin. Demux is connected to each PSRAM's CS pin. --- N64 ROM --- MCU2 holds MCU1 in reset, fills PSRAM with data. MCU1 handles N64 bus requests,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
D+/D-
N64_INT
MCU2 Pin Count = 30 4+1+3+1+1+2+1 + 1+2+1+6+6+1
MC74AC138 fast 3-bit 8 output demultiplexer (active LOW)
MCU2_SPI_Slave
MCU1
MCU1_INT / MCU2_CS
6 (4DIO/SCK/CS)
Debug UART
4 (3 Addr, 1 InputEnable)
N64_S_DAT



Board: 4 copper layers, 105.0 x 60.0 mm, 159 parts (5 on the bottom side), 121 nets.

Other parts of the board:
kibuzzard-62F8E97D: G***; kibuzzard-62F8E97D
kibuzzard-62F95F09: G***; kibuzzard-62F95F09
kibuzzard-63B14A32: G***; kibuzzard-63B14A32
kibuzzard-63B14B13: G***; kibuzzard-63B14B13

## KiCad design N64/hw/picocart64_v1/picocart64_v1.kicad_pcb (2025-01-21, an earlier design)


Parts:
FB1: Ferrite; L_0603_1608Metric
J1: USB_C_Receptacle_USB2.0; USB_C_Receptacle_GT-USB-7010
J2: Conn_01x05; PinHeader_1x05_P2.54mm_Vertical
J3: Conn_02x06_Odd_Even; PinSocket_2x06_P2.54mm_Horizontal
J4: Micro_SD_Card_Det; microSD_HC_Molex_104031-0811
JP1, JP2, JP3, JP4: SolderJumper_2_Open; SolderJumper-2_P1.3mm_Open_TrianglePad1.0x1.5mm
Q1: BSS84; SOT-23
R1: 1M; R_0603_1608Metric
R2, R3: 5k1; R_0603_1608Metric
SW1: BootButton; SW_SPST_FSMSM
U3: RP2040_Stamp; RP2040_Stamp_FlexyPin
U4: N64-Cartridge; N64-Connector

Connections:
+3V3: J2.1, J3.1, J3.2, J4.4 (VDD), Q1.2 (S), U3.34 (3.3V)
/AD0: U3.1 (GPIO0), U4.28 (AD0)
/AD1: U3.2 (GPIO1), U4.29 (AD1)
/AD2: U3.3 (GPIO2), U4.30 (AD2)
/AD3: U3.4 (GPIO3), U4.32 (AD3)
/AD4: U3.5 (GPIO4), U4.36 (AD4)
/AD5: U3.6 (GPIO5), U4.37 (AD5)
/AD6: U3.7 (GPIO6), U4.40 (AD6)
/AD7: U3.8 (GPIO7), U4.41 (AD7)
/AD8: U3.9 (GPIO8), U4.16 (AD8)
/AD9: U3.10 (GPIO9), U4.15 (AD9)
/AD10: U3.11 (GPIO10), U4.12 (AD10)
/AD11: U3.12 (GPIO11), U4.11 (AD11)
/AD12: U3.13 (GPIO12), U4.7 (AD12)
/AD13: U3.14 (GPIO13), U4.5 (AD13)
/AD14: U3.15 (GPIO14), U4.4 (AD14)
/AD15: U3.16 (GPIO15), U4.3 (AD15)
/ALEH: U3.18 (GPIO17), U4.35 (aleH)
/ALEL: U3.17 (GPIO16), U4.33 (aleL)
/N64_CIC_DCLK: U3.21 (GPIO20), U4.43 (u3_14)
/N64_CIC_DIO: U3.22 (GPIO21), U4.18 (u3_15)
/N64_COLD_RESET: U3.23 (GPIO22), U4.20 (COLD_RESET)
/N64_INT: JP3.2 (B), U4.44 (NC)
/N64_NMI: JP4.2 (B), U4.45 (os_event_cart)
/N64_SI_CLK: JP2.2 (B), U4.19 (1.6mHz)
/N64_S_DAT: JP1.2 (B), U4.21 (S_DAT)
/N64_VCC: Q1.3 (D), U4.9 (VCC), U4.17 (VCC), U4.34 (VCC), U4.42 (VCC)
/PMOD_1_SS: J3.11, J4.3 (CMD), JP3.1 (A), U3.26 (GPIO25)
/PMOD_2_SIO0: J3.9, J4.7 (DAT0), U3.28 (GPIO27)
/PMOD_3_SIO1: J3.7, J4.8 (DAT1), U3.29 (GPIO28)
/PMOD_4_SCLK: J3.5, J4.5 (CLK), JP4.1 (A), U3.27 (GPIO26)
/PMOD_5_SIO2: J3.12, J4.1 (DAT2), JP1.1 (A), U3.24 (GPIO23)
/PMOD_6_SIO3: J3.10, J4.2 (DAT3/CD), JP2.1 (A), U3.25 (GPIO24)
/PMOD_7_CS0: J3.8, J4.10 (DET_A), U3.30 (GPIO29)
/PMOD_8_CS1: J3.6
/RP_SWDCLK: J2.3, U3.38 (SWCLK)
/RP_SWDIO: J2.4, U3.37 (SWDIO)
/USB_D+: J1.A6 (D+), J1.B6 (D+), U3.36 (USB_D+)
/USB_D-: J1.A7 (D-), J1.B7 (D-), U3.35 (USB_D-)
/VBUS_unf: FB1.1, J1.A4 (VBUS), J1.A9 (VBUS), J1.B4 (VBUS), J1.B9 (VBUS)
/~READ: U3.20 (GPIO19), U4.10 (READ)
/~RP_RESET: J2.2, U3.39 (~RESET)
/~WRITE: U3.19 (GPIO18), U4.8 (WRITE)
GND: J1.A1 (GND), J1.A12 (GND), J1.B1 (GND), J1.B12 (GND), J2.5, J3.3, J3.4, J4.6 (VSS), J4.9 (DET_B), J4.11 (SHIELD), R1.1, R2.2, R3.2, SW1.1, U3.31 (GND), U4.1 (GND), U4.2 (GND), U4.6 (GND), U4.22 (GND), U4.23 (GND), U4.25 (GND), U4.26 (GND), U4.27 (GND), U4.31 (GND), U4.47 (GND), U4.48 (GND), U4.50 (GND)
unnamed: J1.A5 (CC1), R2.1
unnamed: J1.B5 (CC2), R3.1
unnamed: J1.S1 (SHIELD), R1.2
unnamed: SW1.2, U3.40 (BOOTSEL)
VBUS: FB1.2, Q1.1 (G), U3.33 (5V)

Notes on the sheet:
Power from USB if possible, N64_VCC otherwise. N64_VCC is disconnected if USB powered.
Not enough I/Os to handle these
Absolute minimum


Board: 4 copper layers, 100.0 x 60.0 mm, 16 parts (1 on the bottom side), 48 nets.

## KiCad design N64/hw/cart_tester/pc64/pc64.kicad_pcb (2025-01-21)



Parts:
C3, C4: 30pF; C_0402_1005Metric; LCSC C107004
C5, C6, C9, C10, C11, C13, C14, C15, C16: 100nF; C_0402_1005Metric; LCSC C1525
C7, C8, C1001, C1002: 1uF; C_0402_1005Metric; LCSC C52923
CON2, CON3: HDR1X3; PinSocket_1x03_P2.54mm_Vertical; Digikey 732-5316-ND
D1: PowerLED; LED_0402_1005Metric; LCSC C130724
F1: 1.1A; Fuse_1206_3216Metric; LCSC C2760273
H1, H2, H3, H4: MountingHole_Pad; MountingHole_2.2mm_M2_ISO7380_Pad_TopBottom
J1: USB_C_Receptacle_USB2.0; USB_C_Receptacle_HRO_TYPE-C-31-M-12; LCSC C165948
J2: Barrel_Jack; BarrelJack_CUI_PJ-036AH-SMT_Horizontal
R1, R2: 5k1; R_0402_1005Metric; LCSC C25905
R3, R4: 27; R_0402_1005Metric; LCSC C25100
R5: 35; R_0402_1005Metric
R1001: 1K; R_0402_1005Metric; LCSC C11702
RP_SW1, RP_SW2: SW_Push; SW_SPST_TL3342; LCSC C318884
SWCLK1: Conn_01x01_Female; TestPoint_Pad_D1.0mm
SWD1: Conn_01x01_Female; TestPoint_Pad_D1.0mm
U2: N64-Cartridge; N64-CONN
U3: W25Q128JVS; SOIC-8_5.23x5.23mm_P1.27mm; LCSC C97521
U4: RP2040; QFN-56-1EP_7x7mm_P0.4mm_EP3.2x3.2mm; LCSC C2040
U1001: SRV05-4; SOT-23-6; LCSC C3021103
U1002: AMS1117-3.3; SOT-223; LCSC C6186
Y1: Crystal_GND24; Crystal_SMD_3225-4Pin_3.2x2.5mm; LCSC C9002

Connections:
3.3V: C8.2, C9.2, C10.2, C11.2, C13.2, C14.2, C15.2, C16.2, C1002.1, D1.2 (A), U2.9 (VCC), U2.17 (VCC), U2.34 (VCC), U2.42 (VCC), U3.8 (VCC), U4.1 (IOVDD), U4.10 (IOVDD), U4.22 (IOVDD), U4.33 (IOVDD), U4.42 (IOVDD), U4.43 (ADC_AVDD), U4.44 (VREG_IN), U4.48 (USB_VDD), U4.49 (IOVDD), U1002.2 (VO)
5V: C1001.1, F1.1, U1001.5 (VP), U1002.3 (VI)
/AD0: U2.28 (AD0), U4.2 (GPIO0)
/AD1: U2.29 (AD1), U4.3 (GPIO1)
/AD2: U2.30 (AD2), U4.4 (GPIO2)
/AD3: U2.32 (AD3), U4.5 (GPIO3)
/AD4: U2.36 (AD4), U4.6 (GPIO4)
/AD5: U2.37 (AD5), U4.7 (GPIO5)
/AD6: U2.40 (AD6), U4.8 (GPIO6)
/AD7: U2.41 (AD7), U4.9 (GPIO7)
/AD8: U2.16 (AD8), U4.11 (GPIO8)
/AD9: U2.15 (AD9), U4.12 (GPIO9)
/AD10: U2.12 (AD10), U4.13 (GPIO10)
/AD11: U2.11 (AD11), U4.14 (GPIO11)
/AD12: U2.7 (AD12), U4.15 (GPIO12)
/AD13: U2.5 (AD13), U4.16 (GPIO13)
/AD14: U2.4 (AD14), U4.17 (GPIO14)
/AD15: U2.3 (AD15), U4.18 (GPIO15)
/ALEH: U2.35 (ALEH), U4.28 (GPIO17)
/ALEL: U2.33 (ALEL), U4.27 (GPIO16)
/CART_12V: J2.2, U2.13 (12V), U2.14 (12V_EXP), U2.38 (12V_EXP), U2.39 (12V)
/CART_INT1: CON2.3, U2.44 (~INT1)
/CART_LAUDIO: CON3.1, U2.24 (LAUDIO)
/CART_NMI: CON2.2, U2.45 (~NMI)
/CART_RAUDIO: CON3.2, U2.49 (RAUDIO)
/CART_VIDEO_SYNC: CON2.1, U2.46 (VIDEO_SYNC)
/CIC_CLK: U2.43 (CIC_DCLK), U4.31 (GPIO20)
/CIC_DIO: U2.18 (CIC_DIO), U4.32 (GPIO21)
/COLD_RESET: U2.20 (~COLD_RESET), U4.34 (GPIO22)
/N64_SI_CLK: U2.19 (SI_CLK), U4.36 (GPIO24)
/N64_SI_DAT: U2.21 (SI_DAT), U4.35 (GPIO23)
/READ: U2.10 (~READ), U4.30 (GPIO19)
/WRITE: U2.8 (~WRITE), U4.29 (GPIO18)
unnamed: C4.1, R1001.2, Y1.1
unnamed: D1.1 (K), R5.2
unnamed: F1.2, J1.A4 (VBUS), J1.A9 (VBUS), J1.B4 (VBUS), J1.B9 (VBUS)
unnamed: J1.A5 (CC1), R1.2
unnamed: J1.B5 (CC2), R2.2
unnamed: SWD1.1, U4.25 (SWD)
unnamed: R4.1, U4.46 (USB_DM)
unnamed: R3.1, U4.47 (USB_DP)
unnamed: C5.2, C6.2, C7.2, U4.23 (DVDD), U4.45 (VREG_VOUT), U4.50 (DVDD)
unnamed: C3.1, U4.20 (XIN), Y1.3
unnamed: R1001.1, U4.21 (XOUT)
QSPI_CSn_Pull: RP_SW1.1, U3.1 (~CS), U4.56 (QSPI_SS)
RP_CLK: U3.6 (CLK), U4.52 (QSPI_SCLK)
RP_SD0: U3.5 (DI(IO0)), U4.53 (QSPI_SD0)
RP_SD1: U3.2 (DO(IO1)), U4.55 (QSPI_SD1)
RP_SD2: U3.3 (IO2), U4.54 (QSPI_SD2)
RP_SD3: U3.7 (IO3), U4.51 (QSPI_SD3)
RUN_PULL: RP_SW2.1, U4.26 (RUN)
USB_D+: J1.A6 (D+), J1.B6 (D+), R3.2, U1001.1 (IO1)
USB_D-: J1.A7 (D-), J1.B7 (D-), R4.2, U1001.6 (IO4)

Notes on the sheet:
3.3V Linear Regulator $0.14 - SOT-223 Good to 1A
USB-C Plug Used in USB 2.0 mode
Pin 9 Floats
Reset Circuit Alternate Uses 2 buttons instead of ATTiny, cheaper but less convenient.
$0.05
Figure out sizing/wiring for this barrel jack
TVS Diode Prevents static (ESD) damage
128Mb Flash Block $1.70 - other options https://tinyurl.com/yfssfxsf
SI_DAT and CLK are EEPROM lines

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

Board: 4 copper layers, 86.1 x 88.9 mm, 43 parts (0 on the bottom side), 53 nets.

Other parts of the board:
Logo: LOGO
kibuzzard-665BAD6D: G***; kibuzzard-665BAD6D
kibuzzard-665BADED: G***; kibuzzard-665BADED
kibuzzard-665BAE91: G***; kibuzzard-665BAE91

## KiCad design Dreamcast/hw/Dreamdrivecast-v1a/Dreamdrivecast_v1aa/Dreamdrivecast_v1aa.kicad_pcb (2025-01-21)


Board: 4 copper layers, 96.0 x 94.2 mm, 81 parts (1 on the bottom side), 99 nets.

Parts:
C1, C2, C5, C6, C7, C8, C9, C10, C11, C16, C17, C20, C21, C22, C23, C24, C25, C26: 100nF; C_0402_1005Metric
C3, C4, C14, C15, C18, C19: 1uF; C_0402_1005Metric
C12, C13, C27, C28: 30pF; C_0402_1005Metric
CD_BCK: TestPoint_Pad_D2.0mm
CD_CLK: TestPoint_Pad_D2.0mm
CD_LRCK: TestPoint_Pad_D2.0mm
CD_SDAT: TestPoint_Pad_D2.0mm
CN1: Molex_52602_0579
D1: D_Schottky; D_SOD-123F
DREAMCRAFT_LOGO: LOGO
F1: 1.1A; Fuse_1206_3216Metric
G_RST: TestPoint_Pad_D1.5mm
J1, J5: USB_C_Receptacle_USB2.0; HRO-TYPE-C-31-M-12_LCSC
J2: Micro_SD_Card; TF-SMD_TF-PUSH
J4: Dreamcast Data; PinHeader_2x16_P2.54mm_Vertical
J6: Dreamcast Control Lines; PinHeader_2x07_P2.54mm_Vertical
J7: MCU Databus; PinHeader_2x10_P2.54mm_Vertical
MCU1, MCU2: RP2040; QFN-56-1EP_7x7mm_P0.4mm_EP3.2x3.2mm
MCU1_GPIO27, MCU1_GPIO28, MCU1_GPIO29, MCU1_SWCLK, MCU1_SWD, MCU2_GPIO26, MCU2_GPIO27, MCU2_GPIO28, MCU2_GPIO29, MCU2_SWCLK, MCU2_SWD: TestPoint_Pad_D2.0mm
R1, R2, R7, R8: 27; R_0402_1005Metric
R3, R9: 1K; R_0402_1005Metric
R4, R5, R10, R11: 5k1; R_0402_1005Metric
R6: R; R_Axial_DIN0207_L6.3mm_D2.5mm_P5.08mm_Vertical
RP_SW1, RP_SW2, RP_SW3, RP_SW4: SW_Push; SW_SPST_TL3342
SW1: Lid; SW_DIP_SPSTx01_Slide_9.78x4.72mm_W7.62mm_P2.54mm
U1, U4: W25Q128JVS; SOIC-8_5.23x5.23mm_P1.27mm
U2: AMS1117-3.3; SOT-223
U3, U6: SRV05-4; SOT-23-6
Use Dreamcast Power: SolderJumper-2_P1.3mm_Open_RoundedPad1.0x1.5mm
Y1, Y2: Crystal_GND24; Crystal_SMD_3225-4Pin_3.2x2.5mm
kibuzzard-63F149CE: DDR_DREAMCAST; kibuzzard-63F149CE

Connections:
3.3V: C4.2, C5.2, C6.2, C7.2, C8.2, C9.2, C10.2, C11.2, C15.1, C19.2, C20.2, C21.2, C22.2, C23.2, C24.2, C25.2, C26.2, J2.4 (VDD), MCU1.1 (IOVDD), MCU1.10 (IOVDD), MCU1.22 (IOVDD), MCU1.33 (IOVDD), MCU1.42 (IOVDD), MCU1.43 (ADC_AVDD), MCU1.44 (VREG_IN), MCU1.48 (USB_VDD), MCU1.49 (IOVDD), MCU2.1 (IOVDD), MCU2.10 (IOVDD), MCU2.22 (IOVDD), MCU2.33 (IOVDD), MCU2.42 (IOVDD), MCU2.43 (ADC_AVDD), MCU2.44 (VREG_IN), MCU2.48 (USB_VDD), MCU2.49 (IOVDD), U1.8 (VCC), U2.2 (VO), U4.8 (VCC)
5V: C14.1, D1.1 (K), U2.3 (VI), U3.5 (VP), U6.5 (VP), Use Dreamcast Power.2
/A0: CN1.A19, J6.1, MCU1.2 (GPIO0)
/A1: CN1.B17, J6.2, MCU1.3 (GPIO1)
/A2: CN1.B19, J6.3, MCU1.4 (GPIO2)
/CD_BCK: CD_BCK.1, CN1.A22
/CD_CLK: CD_CLK.1, CN1.B23
/CD_LRCK: CD_LRCK.1, CN1.B22
/CD_SDAT: CD_SDAT.1, CN1.A23
/CS0: CN1.A20, MCU1.5 (GPIO3)
/CS1: CN1.B20, MCU1.6 (GPIO4)
/D0: CN1.B11, J4.1, MCU2.2 (GPIO0)
/D1: CN1.A11, J4.2, MCU2.3 (GPIO1)
/D2: CN1.B9, J4.3, MCU2.4 (GPIO2)
/D3: CN1.A9, J4.4, MCU2.5 (GPIO3)
/D4: CN1.B6, J4.5, MCU2.6 (GPIO4)
/D5: CN1.A6, J4.6, MCU2.7 (GPIO5)
/D6: CN1.B4, J4.7, MCU2.8 (GPIO6)
/D7: CN1.A4, J4.8, MCU2.9 (GPIO7)
/D8: CN1.A5, J4.9, MCU2.11 (GPIO8)
/D9: CN1.B5, J4.10, MCU2.12 (GPIO9)
/D10: CN1.A7, J4.11, MCU2.13 (GPIO10)
/D11: CN1.B7, J4.12, MCU2.14 (GPIO11)
/D12: CN1.A10, J4.13, MCU2.15 (GPIO12)
/D13: CN1.B10, J4.14, MCU2.16 (GPIO13)
/D14: CN1.A12, J4.15, MCU2.17 (GPIO14)
/D15: CN1.B12, J4.16, MCU2.18 (GPIO15)
/DATABUS_D0: J7.1, MCU1.11 (GPIO8), MCU2.27 (GPIO16)
/DATABUS_D1: J7.2, MCU1.12 (GPIO9), MCU2.28 (GPIO17)
/DATABUS_D2: J7.3, MCU1.13 (GPIO10), MCU2.29 (GPIO18)
/DATABUS_D3: J7.4, MCU1.14 (GPIO11), MCU2.30 (GPIO19)
/DATABUS_D4: J7.5, MCU1.15 (GPIO12), MCU2.31 (GPIO20)
/DATABUS_D5: J7.6, MCU1.16 (GPIO13), MCU2.32 (GPIO21)
/DATABUS_D6: J7.7, MCU1.17 (GPIO14), MCU2.34 (GPIO22)
/DATABUS_D7: J7.8, MCU1.18 (GPIO15), MCU2.35 (GPIO23)
/DATABUS_SIGNAL_READ: J7.9, MCU1.27 (GPIO16), MCU2.36 (GPIO24)
/DATABUS_SIGNAL_WRITE: J7.10, MCU1.28 (GPIO17), MCU2.37 (GPIO25)
/DMACK: CN1.A16, MCU1.30 (GPIO19)
/DMARQ: CN1.A14, MCU1.31 (GPIO20)
/DOPEN: CN1.B2, R6.2, SW1.2 (B)
/G_RST: CN1.A2, G_RST.1
/INTRQ: CN1.B16, MCU1.29 (GPIO18)
/IORDY: CN1.B15, MCU1.9 (GPIO7)
/MCU1_GPIO27: MCU1.39 (GPIO27_ADC1), MCU1_GPIO27.1
/MCU1_GPIO28: MCU1.40 (GPIO28_ADC2), MCU1_GPIO28.1
/MCU1_GPIO29: MCU1.41 (GPIO29_ADC3), MCU1_GPIO29.1
/MCU2_GPIO26: MCU2.38 (GPIO26_ADC0), MCU2_GPIO26.1
/MCU2_GPIO27: MCU2.39 (GPIO27_ADC1), MCU2_GPIO27.1
/MCU2_GPIO28: MCU2.40 (GPIO28_ADC2), MCU2_GPIO28.1
/MCU2_GPIO29: MCU2.41 (GPIO29_ADC3), MCU2_GPIO29.1
/RD: CN1.A15, J6.4, MCU1.7 (GPIO5)
/SD_CLK: J2.5 (CLK), MCU1.32 (GPIO21)
/SD_CMD: J2.3 (CMD), MCU1.34 (GPIO22)
/SD_DAT0: J2.7 (DAT0), MCU1.35 (GPIO23)
/SD_DAT1: J2.8 (DAT1), MCU1.36 (GPIO24)
/SD_DAT2: J2.1 (DAT2), MCU1.37 (GPIO25)
/SD_DAT3: J2.2 (DAT3/CD), MCU1.38 (GPIO26_ADC0)
/WR: CN1.B14, J6.5, MCU1.8 (GPIO6)
Dreamcast_3v3: CN1.A1, CN1.B1
Dreamcast_5V: CN1.A3, CN1.B3, Use Dreamcast Power.1
Dreamcast_12V: CN1.A25, CN1.B25
GND: C1.1, C2.1, C3.1, C4.1, C5.1, C6.1, C7.1, C8.1, C9.1, C10.1, C11.1, C12.2, C13.2, C14.2, C15.2, C16.1, C17.1, C18.1, C19.1, C20.1, C21.1, C22.1, C23.1, C24.1, C25.1, C26.1, C27.2, C28.2, CN1.A8, CN1.A13, CN1.A18, CN1.A21, CN1.A24, CN1.B8, CN1.B13, CN1.B18, CN1.B21, CN1.B24, J1.A1 (GND), J1.A12 (GND), J1.B1 (GND), J1.B12 (GND), J1.S1 (SHIELD), J2.6 (VSS), J4.17, J4.18, J4.19, J4.20, J4.21, J4.22, J4.23, J4.24, J4.25, J4.26, J4.27, J4.28, J4.29, J4.30, J4.31, J4.32, J5.A1 (GND), J5.A12 (GND), J5.B1 (GND), J5.B12 (GND), J5.S1 (SHIELD), J6.8, J6.9, J6.10, J6.11, J6.12, J6.13, J6.14, J7.11, J7.12, J7.13, J7.14, J7.15, J7.16, J7.17, J7.18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
unnamed: C13.1, R3.2, Y1.1
unnamed: C28.1, R9.2, Y2.1
unnamed: J1.A5 (CC1), J5.A5 (CC1), R5.2, R11.2
unnamed: J1.B5 (CC2), J5.B5 (CC2), R4.2, R10.2
unnamed: MCU1.24 (SWCLK), MCU1_SWCLK.1
unnamed: MCU1.25 (SWD), MCU1_SWD.1
unnamed: MCU1.46 (USB_DM), R2.1
unnamed: MCU1.47 (USB_DP), R1.1
unnamed: C1.2, C2.2, C3.2, MCU1.23 (DVDD), MCU1.45 (VREG_VOUT), MCU1.50 (DVDD)
unnamed: C12.1, MCU1.20 (XIN), Y1.3
unnamed: MCU1.21 (XOUT), R3.1
unnamed: MCU2.24 (SWCLK), MCU2_SWCLK.1
unnamed: MCU2.25 (SWD), MCU2_SWD.1
unnamed: MCU2.46 (USB_DM), R8.1
unnamed: MCU2.47 (USB_DP), R7.1
unnamed: C16.2, C17.2, C18.2, MCU2.23 (DVDD), MCU2.45 (VREG_VOUT), MCU2.50 (DVDD)
unnamed: C27.1, MCU2.20 (XIN), Y2.3
unnamed: MCU2.21 (XOUT), R9.1
RP1_CLK: MCU1.52 (QSPI_SCLK), U1.6 (CLK)
RP1_CS: MCU1.56 (QSPI_SS), RP_SW1.1, U1.1 (~CS)
RP1_RUN_PULL: MCU1.26 (RUN), RP_SW2.1
RP1_SD0: MCU1.53 (QSPI_SD0), U1.5 (DI(IO0))
RP1_SD1: MCU1.55 (QSPI_SD1), U1.2 (DO(IO1))
RP1_SD2: MCU1.54 (QSPI_SD2), U1.3 (IO2)
RP1_SD3: MCU1.51 (QSPI_SD3), U1.7 (IO3)
RP1_USB_D+: J1.A6 (D+), J1.B6 (D+), R1.2, U3.1 (IO1)
RP1_USB_D-: J1.A7 (D-), J1.B7 (D-), R2.2, U3.6 (IO4)
RP2_CLK: MCU2.52 (QSPI_SCLK), U4.6 (CLK)
RP2_CS: MCU2.56 (QSPI_SS), RP_SW3.1, U4.1 (~CS)
RP2_RUN_PULL: MCU2.26 (RUN), RP_SW4.1
RP2_SD0: MCU2.53 (QSPI_SD0), U4.5 (DI(IO0))
RP2_SD1: MCU2.55 (QSPI_SD1), U4.2 (DO(IO1))
RP2_SD2: MCU2.54 (QSPI_SD2), U4.3 (IO2)
RP2_SD3: MCU2.51 (QSPI_SD3), U4.7 (IO3)
RP2_USB_D+: J5.A6 (D+), J5.B6 (D+), R7.2, U6.1 (IO1)
RP2_USB_D-: J5.A7 (D-), J5.B7 (D-), R8.2, U6.6 (IO4)
VBUS: D1.2 (A), F1.1, F1.2, J1.A4 (VBUS), J1.A9 (VBUS), J1.B4 (VBUS), J1.B9 (VBUS), J5.A4 (VBUS), J5.A9 (VBUS), J5.B4 (VBUS), J5.B9 (VBUS)

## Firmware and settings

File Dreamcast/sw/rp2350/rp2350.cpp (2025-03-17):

/**
 * SPDX-License-Identifier: BSD-2-Clause
 *
 * Copyright (c) 2023 Kaili Hill
 */

#include <stdio.h>

#include "pico/stdlib.h"
#include "pico/multicore.h"
#include "hardware/structs/systick.h"
#include "hardware/clocks.h"
#include "hardware/uart.h"
#include "hardware/vreg.h"

#include "rp2350_pins.h"
#include "hardware/pio.h"
#include "sega_packet_interface.h"

#include "ide_handling.pio.h"

#include "gdrom.h"

#include "sd_utils.h"

#include "gdrom_utils.h"

// #include "ff.h" /* Obtains integer types */
// #include "diskio.h" /* Declarations of disk functions */
// #include "f_util.h"

// List of important coded control line values for the register map
#define CODED_DATA_REGISTER_READ (0x50) // dreamcast is reading from the data register
#define CODED_DATA_REGISTER_WRITE (0x30) // dreacast is writing to the data register
#define CODED_STATUS_REGISTER_READ (0x57)
#define CODED_COMMAND_REGISTER_WRITE (0x37)

void printNameOfRegister(uint32_t regIndex) {

	switch(regIndex) {
		case 0: printf("ATA_IO"); break;
		case 1: printf("STATUS"); break;
		case 2: printf("ALT_STATUS"); break;
		case 3: printf("COMMAND"); break;
		case 4: printf("BYTE_COUNT_LOW"); break;
		case 5: printf("BYTE_COUNT_HIGH"); break;
		case 6: printf("DATA"); break;
		case 7: printf("DEVICE_CONTROL"); break;
		case 8: printf("DRIVE_SELECT"); break;
		case 9: printf("ERROR"); break;
		case 10: printf("FEATURES"); break;
		case 11: printf("INTERRUPT_REASON"); break;
		case 12: printf("SECTOR_COUNT"); break;
		case 13: printf("SECTOR_NUMBER"); break;
		case 14: printf("INVALID"); break;
		default: {
			printf("BAD INDEX: %x", regIndex); 
			break;
		}
	}

// /* 0 */    SPI_ATA_IO_REGISTER_INDEX = 0       ,
// /* 1 */    SPI_STATUS_REGISTER_INDEX           ,
// /* 2 */    SPI_ALTERNATE_STATUS_REGISTER_INDEX ,
// /* 3 */    SPI_COMMAND_REGISTER_INDEX         ,
// /* 4 */    SPI_BYTE_COUNT_REGISTER_LOW_INDEX      , // Low bits
// /* 5 */    SPI_BYTE_COUNT_REGISTER_HIGH_INDEX      , // high bits
// /* 6 */    SPI_DATA_REGISTER_INDEX             , // use `SPI_data_register` to access this register
// /* 7 */    SPI_DEVICE_CONTROL_REGISTER_INDEX   ,
// /* 8 */    SPI_DRIVE_SELECT_REGISTER_INDEX     ,// ATA Drive/Head register
// /* 9 */    SPI_ERROR_REGISTER_INDEX            ,
// /* 10*/    SPI_FEATURES_REGISTER_INDEX         ,
// /* 11*/    SPI_INTERRUPT_REASON_REGISTER_INDEX , // Read only
// /* 12*/    SPI_SECTOR_COUNT_REGISTER_INDEX     , // Write only
// /* 13*/    SPI_SECTOR_NUMBER_REGISTER_INDEX    , // ATA Sector Number Register
// /* 14*/    SPI_REGISTER_COUNT // 14 = (0xE)

}

// You can use the result of this function to pass into printNameOfRegister to get a string name of the register
int registerIndexFromControlValue(uint32_t controlValue) {
	switch(controlValue) {
    case 0x2E:
        return SPI_DEVICE_CONTROL_REGISTER_INDEX; // write
    case 0x4E:
		return SPI_ALTERNATE_STATUS_REGISTER_INDEX; // read
    case 0x30:
        return SPI_DATA_REGISTER_INDEX; // write
    case 0x50:
        return SPI_DATA_REGISTER_INDEX; // read
    case 0x51:
		return SPI_ERROR_REGISTER_INDEX;
    case 0x31:
        return SPI_FEATURES_REGISTER_INDEX;
    case 0x32:
		return SPI_SECTOR_COUNT_REGISTER_INDEX;
	case 0x52:
		return SPI_INTERRUPT_REASON_REGISTER_INDEX;
    case 0x33:
        return SPI_SECTOR_NUMBER_REGISTER_INDEX;
    case 0x34:
        return SPI_BYTE_COUNT_REGISTER_LOW_INDEX;
    case 0x54:
        return SPI_BYTE_COUNT_REGISTER_LOW_INDEX;
    case 0x35:
        return SPI_BYTE_COUNT_REGISTER_HIGH_INDEX;
    case 0x55:
        return SPI_BYTE_COUNT_REGISTER_HIGH_INDEX;
    case 0x56:
        return SPI_DRIVE_SELECT_REGISTER_INDEX;
    case 0x36:
        return SPI_DRIVE_SELECT_REGISTER_INDEX;
    case 0x37:
		return SPI_COMMAND_REGISTER_INDEX; // write
    case 0x57:
        return SPI_STATUS_REGISTER_INDEX; // read
    default:
        // Handle unexpected index
        return SPI_REGISTER_COUNT;
	}
}

#define DEBUG_UART_BAUD_RATE 115200
#define CORE1_PROCESS_REGISTER_CMD 0x1
#define CORE1_CHIRP_CMD 0x2
volatile uint8_t core_command_buffer[256];
volatile uint8_t core0_buffer_index = 0;
volatile uint8_t core1_buffer_index = 0;

// IRQ does seem to be asserted high which is in contrast to the CS0, CS1, RD, and WR signals.
#define INTRQ_ASSERT 	(1)
#define INTRQ_DEASSERT 	(0)

void main_processing_loop();
void ide_register_controller_main();

// Map values to commands, start with all values loaded to invalid (register count)
uint16_t* registerIndex_map[128] = {0};
volatile uint16_t* status_register = 0;
volatile uint16_t* selectedRegister = 0;
volatile uint32_t register_index = SPI_REGISTER_COUNT;

volatile uint32_t writtenRegisters[10000] = {0};
volatile uint32_t writtenRegisterIndex = 0;

volatile uint16_t* rom = 0;

static inline uint16_t swap8(uint16_t value)
{
	// 0x1122 => 0x2211
	return (value << 8) | (value >> 8);
}

static inline uint32_t swap16(uint32_t value)
{
	// 0x11223344 => 0x33441122
	return (value << 16) | (value >> 16);
}

#define IDE_WRITE_TO_HOST_SM 1 // read from register and write to dreamcast (this is a read pin low)
#define IDE_READ_FROM_HOST_SM 0 // write to register from dreamcast (this is a write pin low)

void setup_read_from_dreamcast() {
	uint sm = IDE_READ_FROM_HOST_SM;
	uint offset = pio_add_program(pio0, &mcu1_read_from_dreamcast_program);
	pio_sm_config c = mcu1_read_from_dreamcast_program_get_default_config(offset);

	sm_config_set_in_pins(&c, 0);
	sm_config_set_out_pins(&c, 0, 16);

	pio_sm_set_pindirs_with_mask(pio0, sm, 0x0000, 0xFFFF);

	sm_config_set_in_shift(&c, false, false, 16);

	pio_sm_init(pio0, sm, offset, &c);
}

void setup_write_to_dreamcast() {
	uint sm = IDE_WRITE_TO_HOST_SM;
	uint offset = pio_add_program(pio0, &mcu1_write_to_dreamcast_program);
	pio_sm_config c = mcu1_write_to_dreamcast_program_get_default_config(offset);

	// Input pins start at pin 16
	sm_config_set_in_pins(&c, 16);

	// Output pins are 0-15, but this is the low byte so start at pin 0
	sm_config_set_out_pins(&c, 0, 16);
	
	// Still set the initial pins to be read
	pio_sm_set_pindirs_with_mask(pio0, sm, 0x0000, 0xFFFF);
	
	sm_config_set_in_shift(&c, false, false, 16);

	pio_sm_init(pio0, sm, offset, &c);
}

#define DMA_HANDLER_SM (1)
#define ATA_BUS_HANDLER_SM (0)

uint ata_bus_handler_offset = 0;
uint dma_bus_handler_offset = 0;

volatile uint dma_bus_handler_dma_channel = 0;
volatile uint8_t dma_bus_handler_dma_setup = 0;
void setup_dma_bus_handler_dma() {
	// setup dma unit
	// DMA Channels
	dma_bus_handler_dma_channel = dma_claim_unused_channel(true);

	// DMA1: Read index from FIFO and store it
	dma_channel_config c1 = dma_channel_get_default_config(dma_bus_handler_dma_channel);
	channel_config_set_transfer_data_size(&c1, DMA_SIZE_16);
	channel_config_set_read_increment(&c1, true);
	channel_config_set_write_increment(&c1, false);  // Store index in a fixed variable
	channel_config_set_dreq(&c1, pio_get_dreq(pio0, DMA_HANDLER_SM, true));

	dma_channel_configure(
		dma_bus_handler_dma_channel,
		&c1,
		&pio0->txf[DMA_HANDLER_SM],		 // Push values to sm 
		gdrom_read_buffer,  // Read from gdrom buffer
		1,                   // Single transfer (index)
		false                // Do not start yet
	);

	dma_bus_handler_dma_setup = 1;
}

void setup_dma_bus_handler() {
	uint sm = DMA_HANDLER_SM;
	dma_bus_handler_offset = pio_add_program(pio0, &dma_bus_handler_program);
	pio_sm_config c = dma_bus_handler_program_get_default_config(dma_bus_handler_offset);

	// Output pins are 0-15, but this is the low byte so start at pin 0
	sm_config_set_out_pins(&c, 0, 16);
	
	// Still set the initial pins to be output
	pio_sm_set_pindirs_with_mask(pio0, sm, 0x2200FFFF, 0x2200FFFF);
	
	sm_config_set_out_shift(&c, false, false, 16); // not sure if we need to do this
	sm_config_set_in_shift(&c, false, false, 16);

	sm_config_set_set_pins(&c, PIN_DMARQ, 1);

	sm_config_set_sideset_pins(&c, PIN_CD_SDAT);

	pio_sm_init(pio0, sm, dma_bus_handler_offset, &c);

	if (!dma_bus_handler_dma_setup) {
		setup_dma_bus_handler_dma();
	}
}

volatile uint8_t dma_bus_running = 0;
volatile uint8_t dma_bus_started = 0;
volatile uint8_t ata_bus_started = 0;

void setup_ata_bus_handler() {
	PIO pio = pio0;
	uint sm = ATA_BUS_HANDLER_SM;
	ata_bus_handler_offset = pio_add_program(pio, &ata_bus_handler_program);
	pio_sm_config c = ata_bus_handler_program_get_default_config(ata_bus_handler_offset);

	// Input pins start at pin 0
	sm_config_set_in_pins(&c, 0);

	// Output pins are 0-15, but this is the low byte so start at pin 0
	sm_config_set_out_pins(&c, 0, 16);
	
	// Still set the initial pins to be read
	pio_sm_set_pindirs_with_mask(pio, sm, 0x800000, 0xFFFFFF);
	sm_config_set_jmp_pin(&c, PIN_WR);
	
	sm_config_set_in_shift(&c, false, false, 32);
	sm_config_set_out_shift(&c, true, false, 32);

	sm_config_set_sideset_pins(&c, PIN_IORDY);

	pio_sm_init(pio, sm, ata_bus_handler_offset, &c);
}

void start_dma_bus_handler() {
	if (ata_bus_started) {
		ata_bus_started = 0;
		pio_sm_set_enabled(pio0, ATA_BUS_HANDLER_SM, false);
		pio_remove_program(pio0, &ata_bus_handler_program, ata_bus_handler_offset);
	}

	setup_dma_bus_handler();
	pio_sm_set_enabled(pio0, DMA_HANDLER_SM, true);

	dma_bus_started = 1;
}

void start_ata_bus_handler() {
	if (dma_bus_started) {
		pio_sm_set_enabled(pio0, DMA_HANDLER_SM, false);
		pio_remove_program(pio0, &dma_bus_handler_program, dma_bus_handler_offset);
		dma_bus_started = 0;
	}

	if (!ata_bus_started) {
		setup_ata_bus_handler();
		pio_sm_set_enabled(pio0, ATA_BUS_HANDLER_SM, true);
		ata_bus_started = 1;
	} else {
		printf("Ata bus handler already started\n");
	}
}

void setup_squarewave_generator() {
	// float bClkDivider = 133;//266000000.0 / (33868800 * 2); //7.85

	PIO pio = pio2;
	uint sm = 0;
	uint offset = pio_add_program(pio, &square_wave_generator_program);
	pio_sm_config c = square_wave_generator_program_get_default_config(offset);

	// gpio_init(PIN_CD_BCK);
	// gpio_set_function(PIN_CD_BCK, GPIO_FUNC_PIO2);
	pio_gpio_init(pio, PIN_CD_BCK);

	// Set clock divider
	// pio_sm_set_clkdiv(pio, sm, bClkDivider);

	sm_config_set_out_pins(&c, PIN_CD_BCK, 1);
	sm_config_set_set_pins(&c, PIN_CD_BCK, 1);

	// Still set the initial pins to be output
	// pio_sm_set_pindirs_with_mask(pio, sm, 0x10000000, 0x10000000);
	pio_sm_set_consecutive_pindirs(pio, sm, PIN_CD_BCK, 1, true);  // Set pin as output

	pio_sm_init(pio, sm, offset, &c);
	pio_sm_set_enabled(pio, sm, true);
}

int main(void) {
	// Set clock speed to 266MHz (3.76ns per cycle)
	// const int freq_khz = 166000;
	const int freq_khz = 266000;
	// const int freq_khz = 300000;
	// const int freq_khz = 336000;
	// const int freq_khz = 396000;
	// vreg_set_voltage(VREG_VOLTAGE_1_25); // Usually needed for clocks over 266MHz
	bool clockWasSet = set_sys_clock_khz(freq_khz, false);

	// stdio_init_all();
	// gpio 44 is uart0 tx
	stdio_uart_init_full(uart0, DEBUG_UART_BAUD_RATE, 44, -1);

	printf("Clock of %uMhz was set: %u\n", freq_khz / 1000, clockWasSet);
	printf("MCU1- Init pins...\n");

	// init all pins used on for the Dreamcast IDE connection
	// This is from pin 0 to pin 33 for a total of 34 pins
	for (int i = 0; i <= PIN_WR; i++) {
		gpio_init(i);
		gpio_set_dir(i, false); // set to input
	}

	// Some pins that need to be set to output
	// TODO: Figure out which pins need to be set to output
	gpio_init(PIN_IORDY);
	// gpio_set_dir(PIN_IORDY, true);
	// gpio_pull_up(PIN_IORDY);

	gpio_init(PIN_DOPEN);
	gpio_set_dir(PIN_DOPEN, true);
	// gpio_pull_down(PIN_DOPEN);

	gpio_init(PIN_INTRQ);
	gpio_set_dir(PIN_INTRQ, true);
	gpio_put(PIN_INTRQ, INTRQ_DEASSERT); // was 0

	gpio_init(PIN_DMARQ);
	gpio_set_dir(PIN_DMARQ, true); // output

	gpio_init(PIN_DMACK);
	gpio_set_dir(PIN_DMACK, false); // input
	// gpio_pull_up(PIN_DMACK);

	// Setup and start the ide databus programs
	printf("Setting up PIO ide databus programs...\n");
	printf("\tiniting gpio for pio...");
	for(int i = 0; i <= PIN_WR; i++) {
		gpio_init(i);
		gpio_set_function(i, GPIO_FUNC_PIO0);
		pio_gpio_init(pio0, i);
	}
	gpio_set_function(PIN_IORDY, GPIO_FUNC_PIO0);
	pio_gpio_init(pio0, PIN_IORDY);

	gpio_init(PIN_RD);
	gpio_set_function(PIN_RD, GPIO_FUNC_SIO);
	gpio_set_dir(PIN_RD, false);

	gpio_init(PIN_WR);
	gpio_set_function(PIN_WR, GPIO_FUNC_SIO);
	gpio_set_dir(PIN_WR, false);

	// Setup dmarq line so it can be used by the dma handler state machine
	gpio_init(PIN_DMARQ);
	gpio_set_function(PIN_DMARQ, GPIO_FUNC_PIO0);
	pio_gpio_init(pio0, PIN_DMARQ);

	gpio_init(PIN_CD_SDAT);
	gpio_set_function(PIN_CD_SDAT, GPIO_FUNC_PIO0);
	pio_gpio_init(pio0, PIN_CD_SDAT);

	setup_squarewave_generator();

	// Set Input Bypass on the cs0, cs1, rd, wr pins for faster edge response
	for (int i = PIN_CS0; i <= PIN_WR; i++) {
		pio0->input_sync_bypass |= (1 << i);
	}
	
	printf("Setting up register map...");

	// This is used to quickly get the right register, read/write should be handled by whatever is doing the lookup
	// Register Index = Bits = W, R, CS1, CS0, A2, A1, A0 (most->least)
	registerIndex_map[0x4E] = &SPI_registers[SPI_STATUS_REGISTER_INDEX];//&SPI_registers[SPI_ALTERNATE_STATUS_REGISTER_INDEX]; // read
	registerIndex_map[0x2E] = &SPI_registers[SPI_DEVICE_CONTROL_REGISTER_INDEX]; // write

	registerIndex_map[0x50] = &SPI_registers[SPI_DATA_REGISTER_INDEX]; // read
	registerIndex_map[0x30] = &SPI_registers[SPI_DATA_REGISTER_INDEX]; // write

	registerIndex_map[0x31] = &SPI_registers[SPI_FEATURES_REGISTER_INDEX]; // write
	registerIndex_map[0x51] = &SPI_registers[SPI_ERROR_REGISTER_INDEX]; // read

	registerIndex_map[0x52] = &SPI_registers[SPI_INTERRUPT_REASON_REGISTER_INDEX]; // read only
	registerIndex_map[0x53] = &SPI_registers[SPI_SECTOR_NUMBER_REGISTER_INDEX]; // read only

	registerIndex_map[0x54] = &SPI_registers[SPI_BYTE_COUNT_REGISTER_LOW_INDEX]; // read
	registerIndex_map[0x34] = &SPI_registers[SPI_BYTE_COUNT_REGISTER_LOW_INDEX]; // write

	registerIndex_map[0x55] = &SPI_registers[SPI_BYTE_COUNT_REGISTER_HIGH_INDEX]; // read
	registerIndex_map[0x35] = &SPI_registers[SPI_BYTE_COUNT_REGISTER_HIGH_INDEX]; // write

	registerIndex_map[0x56] = &SPI_registers[SPI_DRIVE_SELECT_REGISTER_INDEX]; // read
	registerIndex_map[0x36] = &SPI_registers[SPI_DRIVE_SELECT_REGISTER_INDEX]; // write

	registerIndex_map[0x57] = &SPI_registers[SPI_STATUS_REGISTER_INDEX]; // read
	registerIndex_map[0x37] = &SPI_registers[SPI_COMMAND_REGISTER_INDEX]; // write

	// misc registers, these aren't in the gdrom doc but ARE ata registers
	registerIndex_map[0x32] = &SPI_registers[SPI_SECTOR_COUNT_REGISTER_INDEX]; // write

	// Setup a pointer to the status register
	status_register = &SPI_registers[SPI_STATUS_REGISTER_INDEX];

	SPI_registers[SPI_STATUS_REGISTER_INDEX] = 0b01000000; // set drive ready bit
	SPI_registers[SPI_DRIVE_SELECT_REGISTER_INDEX] = 0xA0; // set drive select
	SPI_registers[SPI_SECTOR_COUNT_REGISTER_INDEX] = 0b00;
	SPI_registers[SPI_SECTOR_NUMBER_REGISTER_INDEX] = 0x80; // GDROM is 0x80

	// For the rest of the values, just use a dump register
	for(int i = 0; i < 128; i++) {
		if (registerIndex_map[i] == 0) {
			registerIndex_map[i] = &SPI_registers[SPI_REGISTER_COUNT]; // Use the SPI_REGISTER_COUNT as a dump register
		}
	}

	// Launch the register loop on core 1
	multicore_launch_core1(ide_register_controller_main);

	main_processing_loop();

	printf("\nFATAL ERROR!! Main processing loop has exited\n");
	return 0;
}

volatile uint8_t restart_ata_bus_handler_loop = 0;
volatile uint32_t readWriteLineValues = 0;
void _process_ata_register_access() {

	if (!ata_bus_started) {
		start_ata_bus_handler();
	}

	while(ata_bus_started) {

		while (pio_sm_is_rx_fifo_empty(pio0, ATA_BUS_HANDLER_SM) && ata_bus_started) { 
			tight_loop_contents();
		}
		if (!ata_bus_started) {
			break;
		}

		readWriteLineValues = pio0->rxf[ATA_BUS_HANDLER_SM];
		register_index = readWriteLineValues & 0x7F;
		selectedRegister = registerIndex_map[register_index];

		// WRITE TO DREAMCAST (write == 1, read == 0)
		// read pin active low (so write is high)
		if ((readWriteLineValues & READ_WRITE_PIN_MASK) == READ_PIN_MASK) {

			while (pio_sm_is_tx_fifo_full(pio0, ATA_BUS_HANDLER_SM) && ata_bus_started) {
				tight_loop_contents();
			}
			if (!ata_bus_started) {
				break;
			}
			pio0->txf[0] = *selectedRegister;

			if (writtenRegisterIndex < 5000 && register_index != 0x4e) {
				if (dma_bus_started) {
					writtenRegisters[writtenRegisterIndex++] = 0xDEADBEEF;
				}
				multicore_fifo_push_blocking(register_index);

				// if (register_index != 0x50 && register_index != 0x53) {
				// 	writtenRegisters[writtenRegisterIndex++] = 0xAAAA;
				// 	writtenRegisters[writtenRegisterIndex++] = register_index;
				// 	writtenRegisters[writtenRegisterIndex++] = *selectedRegister;
				// 	writtenRegisters[writtenRegisterIndex++] = 0xDDDD;
				// }
			}

		// READ FROM DREAMCAST (write == 0, read == 1)
		// write pin active low (so read is high)
		} else if ((readWriteLineValues & READ_WRITE_PIN_MASK) == WRITE_PIN_MASK) {
			// if (writtenRegisterIndex < 5000) {
			// 	writtenRegisters[writtenRegisterIndex++] = 0xBBBB;
			// 	writtenRegisters[writtenRegisterIndex++] = register_index;
			// }

			while (pio_sm_is_rx_fifo_empty(pio0, ATA_BUS_HANDLER_SM) && ata_bus_started) { 
				tight_loop_contents(); 
			}
			if (!ata_bus_started) {
				break;
			}

			*selectedRegister = pio0->rxf[ATA_BUS_HANDLER_SM];

			// if (writtenRegisterIndex < 5000) {
			// 	writtenRegisters[writtenRegisterIndex++] = *selectedRegister;
			// 	writtenRegisters[writtenRegisterIndex++] = 0xDDDD;
			// }
			
			if (dma_bus_started) {
				writtenRegisters[writtenRegisterIndex++] = 0xDEADBEEF;
			}
			multicore_fifo_push_blocking(register_index);
			
		} 
		// else {
		// 	if (writtenRegisterIndex < 5000) {
		// 		writtenRegisters[writtenRegisterIndex++] = 0xCCCC;
		// 		writtenRegisters[writtenRegisterIndex++] = register_index;
		// 		writtenRegisters[writtenRegisterIndex++] = readWriteLineValues;
		// 		writtenRegisters[writtenRegisterIndex++] = 0xDDDD;
		// 	}
		// }
	}
}

uint32_t gdrom_read_buffer_needs_refill = 0;
uint8_t gdrom_read_buffer_select = 0;
uint8_t gdrom_read_buffer_1_ready = 0;
uint8_t gdrom_read_buffer_2_ready = 0;

void __not_in_flash_func(process_ata_register_access)() {
	uint32_t startTime = 0;
	uint32_t endTime = 0;
	_process_ata_register_access();
	while(1) {
		if (restart_ata_bus_handler_loop) {
			printf("Restarting ata bus handler\n");
			restart_ata_bus_handler_loop = 0;
			_process_ata_register_access();
		}

		if(dma_bus_running && gdrom_read_buffer_needs_refill) {
			gdrom_read_buffer_needs_refill = 0;
			/// LOAD BUFFER
			if (gdrom_read_buffer_select == 0) {
				startTime = time_us_32();
				gdrom_fill_read_buffer(gdrom_read_buffer);
				endTime = time_us_32();
				gdrom_read_buffer_1_ready = 1;
				printf("Refill %u, in %uus...\n", gdrom_read_buffer_select, endTime - startTime);
				
			} else if (gdrom_read_buffer_select == 1) {
				startTime = time_us_32();
				gdrom_fill_read_buffer(gdrom_read_buffer2);
				endTime = time_us_32();
				gdrom_read_buffer_2_ready = 2;
				printf("Refill %u, in %uus...\n", gdrom_read_buffer_select, endTime - startTime);
			}
		}

		tight_loop_contents();
	}
	printf("FATAL ERROR: process_ata_register_access ended\n");
}

void ide_register_controller_main() {
	printf("Dreamcast booting...\n");

	// printf("DONE!\n\tSetting up programs...");
	// setup_ata_bus_handler();
	// printf("DONE!\n");

	// The Dreamcast(something?) does a startup with the cd drive and it toggles all the control, read, and write lines.
	// Not sure if this is real data or just a fun little startup sequence

	while(!gpio_get(PIN_CS0)); // loop until the cs lines are active (really only useful when powering the board on before the console)

	printf("Dreamcast booted!\n");

	busy_wait_ms(900); // TODO this is likely not needed? 

	selectedRegister = registerIndex_map[SPI_REGISTER_COUNT];

	// By using the IORDY pin, we can slow down the control signaling.
	// This makes it a lot slower to read/write to the dreamcast but does at least work
	// TODO: Figure out how to do this without the IORDY pin to speed up the control processing
	gpio_put(PIN_IORDY, 1);

	process_ata_register_access();

	printf("\nERROR!!! Register controller core main loop ended.\n");
}

uint32_t timetrack = 0;
bool hasChirped = false;
volatile uint32_t core0CData = 0;
volatile uint16_t core0commandRegister = 0;
volatile uint16_t* spi_packet_register = 0;
volatile uint8_t spi_packet_word_count = 0;
volatile uint16_t generic_data_buffer[128] = {0}; // Basic buffer to send data for things like req_ses, error, etc

#define DATA_MODE_IDLE 		(0)
#define DATA_MODE_SPI 		(1) // Sega SPI packet mode, processing their 12 byte packets
#define IDE_TRANSFER_MODE_PIO (0)
#define IDE_TRANSFER_MODE_DMA (1)
static uint8_t ide_current_mode = DATA_MODE_IDLE;
static uint8_t ide_current_transfer_mode = 0; // 0 = PIO, 1 = DMA

#define IO_MODE_IDLE 0
#define IO_MODE_WRITE 1
#define IO_MODE_READ 2
static uint8_t current_io_mode = 0;
// In other code bases, this is part of the state variable for data mode, but
// knowing which packet command is being processed is fine for now.
// There may be a point when we need to change to a better state machine.
// But that will likely require rethinking the whole flow.
static uint8_t current_io_packet_command = 0; // This is just the current SPI packet command we are processing, useful for sending canned responses vs actual data

static uint8_t command71Flag = 0;
static const uint8_t gdrom_version[] = "Rev 5.07";

// Bake the offset into the starting and ending positions
static uint32_t io_current_position = 0;
static uint32_t io_ending_position = 0;
volatile uint8_t secnr_poll_count = 0;
volatile uint8_t secnr_poll_next_status = 0x80;
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

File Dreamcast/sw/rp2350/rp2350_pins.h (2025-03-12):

/**
 * SPDX-License-Identifier: BSD-2-Clause
 *
 * Copyright (c) 2023 Kaili Hill
 */

#pragma once

#define DATABUS_D0 0  // D0-D15 on GPIO 0-15
#define PIN_A0 16
#define PIN_A1 17
#define PIN_A2 18
#define PIN_CS0 19
#define PIN_CS1 20
#define PIN_RD 21
#define PIN_WR 22
#define PIN_IORDY 23
#define PIN_INTRQ 24
#define PIN_DMARQ 25
#define PIN_DMACK 26
#define PIN_CD_LRCK 27
#define PIN_CD_BCK 28
#define PIN_CD_SDAT 29
#define PIN_CDDA_CLK 30
#define PIN_CD_EMPH 31
#define PIN_DOPEN 32
#define PIN_GD_RST 33
#define PIN_SD_CLK 34
#define PIN_SD_CMD 35
#define PIN_SD_D0 36
#define PIN_SD_D1 37
#define PIN_SD_D2 38
#define PIN_SD_D3 39

// Update masks for the new pin layout
#define CS_PINS_MASK (0x18)
#define READ_WRITE_PIN_MASK (0x60)
#define READ_PIN_MASK (0x40)
#define WRITE_PIN_MASK (0x20)
#define REGISTER_PIN_MASK (0x7F)
#define BIT_SHIFTED_READ_PIN_MASK (0x40)

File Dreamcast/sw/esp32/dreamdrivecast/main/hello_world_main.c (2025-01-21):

/*
 * SPDX-FileCopyrightText: 2010-2022 Espressif Systems (Shanghai) CO LTD
 *
 * SPDX-License-Identifier: CC0-1.0
 */

#include <stdio.h>
#include <inttypes.h>
#include "sdkconfig.h"
#include "freertos/FreeRTOS.h"
#include "freertos/task.h"

#include "driver/gpio.h"
#include "soc/gpio_reg.h"
#include "soc/gpio_struct.h"
#include "soc/io_mux_reg.h"
#include "soc/dport_access.h"

#include "sega_packet_interface.h"

// 8 Control lines (including IORDY since it seems useful and sort of needed?)
#define CONTROL_LINE_MASK       (0x7F0)
#define CS_PINS_MASK            (0x180)
#define CONTROL_REG_PINS_MASK   (0x1F0)
#define READ_WRITE_PIN_MASK     (0x600)
#define A0_PIN              (4)
#define A1_PIN              (5)
#define A2_PIN              (6)
#define CS0_PIN             (7)
#define CS1_PIN             (8)
#define RD_PIN              (9)
#define WR_PIN              (10)

#define IORDY_PIN_MASK      (0x4000000000)
#define IORDY_PIN           (38)

// 8 lines for the interconnect
#define DATA_PIN_MASK       (0x7F800) // shift 11 to do easy data inout
#define D0_PIN              (11)
#define D1_PIN              (12)
#define D2_PIN              (13)
#define D3_PIN              (14)
#define D4_PIN              (15)
#define D5_PIN              (16)
#define D6_PIN              (17)
#define D7_PIN              (18)

// Interconnect bus. 
// 8 bit bidirectional bus
// 3 control lines
// 11 total lines
#define MCU_INTERCONNECT_BUS_MASK       (0x7F800)
#define MCU_INTERCONNECT_PIN_MASK       (0x200003)
#define MCU_IRQ_LOW_PIN                 (1)
#define MCU_IRQ_HIGH_PIN                (2)
#define MCU_INTERCONNECT_DIRECTION_PIN  (21)

/*
1 output
2 output
4-10 input
11-18 bidirectional

0x7F803 output mask
0x7FFF0 input mask
*/

#define INPUT_PIN_MASK      (0x7FFF0)
#define OUTPUT_PIN_MASK     (0x7F803)

// MCU1
// 8 data lines
// 8 dreamcast control lines
// 3 interconnect control lines
// 3 for irq, dmarq, dmack
// 5 lines for cd audio
// 5 for sd card (3 if using spi)
// 32 total pins?

// MCU2 (mux)
// 8 Interconnect lines
// 3 interconnect contol lines
// 16 data lines
// 27 pins


// Using gpio 4,5,6,7,8,9,10
// Connected to 
// a0, a1, a2, cs0, cs1, rd, wr

uint32_t SPI_registers[SPI_REGISTER_COUNT+1];
uint32_t* registerIndex_map[128] = {0};
volatile uint32_t* status_register = 0;
volatile uint32_t* selectedRegister = 0;
volatile uint32_t register_index = SPI_REGISTER_COUNT;
volatile uint32_t writtenRegisters[10000] = {0};
volatile uint32_t writtenRegisterIndex = 0;

void app_main(void) {
    gpio_config_t io_conf = {};
    io_conf.intr_type = GPIO_INTR_DISABLE;
    io_conf.mode = GPIO_MODE_INPUT;
    io_conf.pin_bit_mask = CONTROL_LINE_MASK;
    io_conf.pull_down_en = 0;
    io_conf.pull_up_en = 0;
    gpio_config(&io_conf);

    gpio_config_t io_conf1 = {};
    io_conf1.intr_type = GPIO_INTR_DISABLE;
    io_conf1.mode = GPIO_MODE_OUTPUT;
    io_conf1.pin_bit_mask = IORDY_PIN_MASK;
    io_conf1.pull_down_en = 0;
    io_conf1.pull_up_en = 0;
    gpio_config(&io_conf1);

    gpio_config_t io_databus_conf = {};
    io_databus_conf.intr_type = GPIO_INTR_DISABLE;
    io_databus_conf.mode = GPIO_MODE_OUTPUT;
    io_databus_conf.pin_bit_mask = DATA_PIN_MASK;
    io_databus_conf.pull_down_en = 0;
    io_databus_conf.pull_up_en = 0;
    gpio_config(&io_databus_conf);

    gpio_config_t io_interconnect_conf = {};
    io_interconnect_conf.intr_type = GPIO_INTR_DISABLE;
    io_interconnect_conf.mode = GPIO_MODE_OUTPUT;
    io_interconnect_conf.pin_bit_mask =  MCU_INTERCONNECT_PIN_MASK;
    io_interconnect_conf.pull_down_en = GPIO_PULLDOWN_ENABLE;
    io_interconnect_conf.pull_up_en = 0;
    gpio_config(&io_interconnect_conf);
    //GPIO.enable_w1ts = output
    //GPIO.enable_w1tc = input

    gpio_set_level(MCU_INTERCONNECT_DIRECTION_PIN, 0);
    gpio_set_level(MCU_IRQ_LOW_PIN, 0);
    gpio_set_level(MCU_IRQ_HIGH_PIN, 0);

    volatile uint32_t readWriteLineValues = 0;
    volatile uint32_t register_index = 0;
    volatile uint32_t csLineValue = 0;

    // This is used to quickly get the right register, read/write should be handled by whatever is doing the lookup
	// Register Index = Bits = W, R, CS1, CS0, A2, A1, A0 (most->least)
	registerIndex_map[0x4E] = &SPI_registers[SPI_STATUS_REGISTER_INDEX];//&SPI_registers[SPI_ALTERNATE_STATUS_REGISTER_INDEX]; // read
	registerIndex_map[0x2E] = &SPI_registers[SPI_DEVICE_CONTROL_REGISTER_INDEX]; // write

	registerIndex_map[0x50] = &SPI_registers[SPI_DATA_REGISTER_INDEX]; // read
	registerIndex_map[0x30] = &SPI_registers[SPI_DATA_REGISTER_INDEX]; // write

	registerIndex_map[0x31] = &SPI_registers[SPI_FEATURES_REGISTER_INDEX]; // read
	registerIndex_map[0x51] = &SPI_registers[SPI_ERROR_REGISTER_INDEX]; // write

    registerIndex_map[0x32] = &SPI_registers[SPI_SECTOR_COUNT_REGISTER_INDEX]; // write

	registerIndex_map[0x52] = &SPI_registers[SPI_INTERRUPT_REASON_REGISTER_INDEX]; // read only
	registerIndex_map[0x53] = &SPI_registers[SPI_SECTOR_NUMBER_REGISTER_INDEX]; // read only

	registerIndex_map[0x54] = &SPI_registers[SPI_BYTE_COUNT_REGISTER_LOW_INDEX]; // read
	registerIndex_map[0x34] = &SPI_registers[SPI_BYTE_COUNT_REGISTER_LOW_INDEX]; // write

	registerIndex_map[0x55] = &SPI_registers[SPI_BYTE_COUNT_REGISTER_HIGH_INDEX]; // read
	registerIndex_map[0x35] = &SPI_registers[SPI_BYTE_COUNT_REGISTER_HIGH_INDEX]; // write

	registerIndex_map[0x56] = &SPI_registers[SPI_DRIVE_SELECT_REGISTER_INDEX]; // read
	registerIndex_map[0x36] = &SPI_registers[SPI_DRIVE_SELECT_REGISTER_INDEX]; // write

	registerIndex_map[0x57] = &SPI_registers[SPI_STATUS_REGISTER_INDEX]; // read
	registerIndex_map[0x37] = &SPI_registers[SPI_COMMAND_REGISTER_INDEX]; // write

    /*
    I was using the sega packet interface docs which don't include some of the registers that ARE VALID
    making me think I was crazy
    */

	// Setup a pointer to the status register
	status_register = &SPI_registers[SPI_STATUS_REGISTER_INDEX];

	SPI_registers[SPI_STATUS_REGISTER_INDEX] = 0x40; //0x48 is DRDY and DRQ bits, 0x40 is just DRDY
	SPI_registers[SPI_DRIVE_SELECT_REGISTER_INDEX] = 0xA0; // set drive select
    SPI_registers[SPI_INTERRUPT_REASON_REGISTER_INDEX] = 0x00; // 

	// For the rest of the values, just use a dump register
	for(int i = 0; i < 128; i++) {
		if (registerIndex_map[i] == 0) {
			registerIndex_map[i] = &SPI_registers[SPI_REGISTER_COUNT]; // Use the SPI_REGISTER_COUNT as a dump register
		}
	}

    vTaskDelay(4000 / portTICK_PERIOD_MS);
    printf("Boot dreamcast...\n");
    
    while(!gpio_get_level(CS0_PIN)){
        // busy wait
        vTaskDelay(1 / portTICK_PERIOD_MS);
    }; // loop until the cs lines are active (really only useful when powering the board on before the console)

	printf("Dreamcast booted!\n");
    vTaskDelay(1000 / portTICK_PERIOD_MS);

    // Pull signal low to indicate we are ready to read/write
    gpio_set_level(IORDY_PIN, 0);

    // Set pins back to input
    // GPIO.enable_w1tc = DATA_PIN_MASK;
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

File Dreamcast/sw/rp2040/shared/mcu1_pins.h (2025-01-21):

/**
 * SPDX-License-Identifier: BSD-2-Clause
 *
 * Copyright (c) 2023 Kaili Hill
 */

#pragma once

// Control lines (share the same pins as data 0-4, controlled via mux select = high)
#define MCU1_PIN_A0					(0)
#define MCU1_PIN_A1					(1)
#define MCU1_PIN_A2					(2)
#define MCU1_PIN_CS0				(3)
#define MCU1_PIN_CS1				(4)

// Data lines (d0-4 shared with control lines, controlled via mux select = low)
#define MCU1_PIN_D0                 (8)
#define MCU1_PIN_D1                 (9)
#define MCU1_PIN_D2                 (10)
#define MCU1_PIN_D3                 (11)
#define MCU1_PIN_D4                 (12)
#define MCU1_PIN_D5                 (13)
#define MCU1_PIN_D6                 (14)
#define MCU1_PIN_D7                 (15)
// #define MCU1_PIN_D8                 (8)
// #define MCU1_PIN_D9                 (9)
// #define MCU1_PIN_D10                (10)
// #define MCU1_PIN_D11                (11)
// #define MCU1_PIN_D12                (12)
// #define MCU1_PIN_D13                (13)
// #define MCU1_PIN_D14                (14)
// #define MCU1_PIN_D15                (15)

// READ/WRITE
#define MCU1_PIN_READ				(5)
#define MCU1_PIN_WRITE				(6)
#define MCU1_PIN_IORDY              (7)

// // Signal lines
// #define MCU1_PIN_INTRQ				(18)
// #define MCU1_PIN_DMACK				(19)
// #define MCU1_PIN_DMARQ				(20)

// // Redine of the pins that are connected to the mux
// #define MCU1_PIN_MUX_0				(0)
// #define MCU1_PIN_MUX_1				(1)
// #define MCU1_PIN_MUX_2				(2)
// #define MCU1_PIN_MUX_3				(3)
// #define MCU1_PIN_MUX_4				(4)

// SD Card
#define MCU1_PIN_SD_CLK             (21)
#define MCU1_PIN_SD_CMD             (22)
#define MCU1_PIN_SD_D0              (23)
#define MCU1_PIN_SD_D1              (24)
#define MCU1_PIN_SD_D2              (25)
#define MCU1_PIN_SD_D3              (26)

// gpio 26 is used to tell other rp2040 that we want to 
// read/write to the dreamcast
// gpio 27 is used in conjuction with 26 when we are strobing
// data in and out of the pins
#define MCU1_DATABUS_D0               (8)
#define MCU_DATABUS_DEVICE_SIGNAL_PIN (16)
#define MCU_DATABUS_DEVICE_WRITE_PIN  (17)

// UART comms to MCU2
#define MCU1_PIN_PIO_COMMS_D0       (28) // RX
#define MCU1_PIN_PIO_COMMS_D1       (29) // TX
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

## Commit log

2023-02-16 Added start of dreamcast gdrom breakout board.
    [Dreamdrivecast.kicad_pcb, Dreamdrivecast.kicad_sch]
2023-02-16 Updating dreamcast schematic with lots of notes about what signals are used for what.
2023-02-17 More notes about how the dreamcast gdrom protocol works and what the pins do
    [Dreamdrivecast.kicad_sch]
2023-02-17 Added possible two mcu approach to dreamcast dev board.
    [Dreamdrivecast.kicad_sch]
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2023-02-17 Ignore the backup folder. AND also check in the changes to the schematic.
    [Dreamdrivecast.kicad_sch]
2023-02-18 Routed dreamcast board. Added some footprints and symbols for the molex connector.
    [Dreamdrivecast.kicad_pcb, Dreamdrivecast.kicad_sch]
2023-02-18 Routed board, did copper fill, added silk screen for breakout, added logo and board text. Ready for fab
    [Dreamdrivecast.kicad_pcb, Dreamdrivecast.kicad_sch]
2023-02-22 Updated PCB with artwork and production files. Rotations still seem off sometimes when I import them into JLCPCB although they seem to be able to assemble the boards just fine.
    [Dreamdrivecast.kicad_pcb, bom.csv, designators.csv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]
2023-03-28 Moved source code from PicoCart64 fork to its own repo here.
    [board.kicad_sch, bom.csv, designators.csv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]
2023-04-02 FINALLY got mcu1/2 to output and read data correctly. Code is obviously a mess but wanted to checkin while it was working.
    [mcu1.c, mcu1_pins.h, mcu2.c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]
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2023-04-02 Fixed more dead lock issues. This code can get out of sync and the bits can be shifted into the wrong place.
    Probably want to use flags to sample 16bits instead of 4.
2023-04-12 Wrote a lot of code and comments about the processing all these ATA and SPI commands.
2023-04-13 Updated the docs with an updated table from the spi spec pdf since the one in the pdf was wrong (cs0 and cs1 were flipped) Got data flowing to mcu1 when mcu2 sees changes on the control pins. Likely 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
    [mcu1.c, mcu1_pins.h, mcu2.c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]
2023-04-15 Moved read/write to MCU1, also only now use 2 data pins for comms.
    Updated some code to account for this change. As well as the fact that the cs0 cs1 lines were reversed.
    Updated some docs for new swapped cs line values
    [mcu1.c, mcu1_pins.h, mcu2.c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]
2023-04-15 Trying to get read and write triggering something on mcu1. It doesn't seem fast enough to handle reading the rx buffer after the rd/wr pin goes low. Or at least the mcu2_control_line_state I'm using 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
    [mcu1.c, mcu1_pins.h, mcu2.c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]
2023-04-15 Still have the cs line flipped. The function select table is good but when reading in the values on the logic analyzer the values need to be read CS0, CS1, AD2, AD1, AD0. I swapped the names of the c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
    [mcu2.c, mcu2_pins.h, sega_packet_interface.c]
2023-04-18 Weird rabbit hole of pin low detection latency. Have a working solution that will monitor the 2 CS pins with 1 PIO program each, raise an IRQ which a 3rd program will read and set gpio 18 high (to te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
2023-04-18 Writing out some prototype PIO code that waits for CS lines then read or writes to the bus.
2023-04-21 Update schematic to use rp2040s, mux the control lines with some data pins on mcu1, and change the pinout. PCB hasn't been rerouted yet.
    [Dreamdrivecast.kicad_sch]
2023-04-21 Updated PCB for new schematic design, still needs to be routed.
    [Dreamdrivecast.kicad_pcb, Dreamdrivecast.kicad_sch]
2023-04-23 Updated pcb for new schematic.
    [Dreamdrivecast.kicad_pcb, Dreamdrivecast.kicad_sch]
2023-04-23 Generated BOM and position files for pcb assembly.
    [Dreamdrivecast.kicad_pcb, bom.csv, designators.csv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]
2023-04-24 Moved some things around. Wrote a struct to contain all the databus pio programs, should make it easier to swap out the cs detect for read/write detect programs. Still not sure how fast that actually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
    [Dreamdrivecast.kicad_pcb, Dreamdrivecast.kicad_sch, bom.csv]
2023-04-24 Might as well check in the updated "production" files that are created with the JLC production toolkit plugin for kicad.
    [designators.csv, positions.csv]
2023-06-19 Updated some files with new pin outs for the new board revision. Using PIO_UART from dreamdrive64 instead of serial_bridge as we now only have 2 pins and that already works.
2023-07-17 Made some comments about CS1/CS0... Table from the pdf uses 'A' and 'N' and columns in CS0, CS1... Since A=0v[binary 0] and N=3v[binary 1], we can swap the values and use the binary values as is. Thi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
    [mcu1.c, sega_databus.c, sega_packet_interface.c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]
2023-07-28 Switched to using uart output (with a bodge wire soldered on the comms_pio0 via for uart0-tx. Wrote a test to figure out the number of cycles to swap two pio programs and running into some weird issu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
    [mcu1.c, sega_databus.c, sega_packet_interface.c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]
2023-08-01 Added two pio programs. The combined cs and read or write together as swapping the programs was too slow. Haven't finished setting them up, just have some method stubs to configure them
    [sega_databus.c]
2023-08-04 Trying to get data out of PIO program. It's using the combined CS/RD/WR program that will signal into the datahandler program. Doesn't seem to be pushing anything to the C code. So it is either not s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
    [mcu1.c]
2023-12-14 Added some comments to remember how stuff works and working on a new PIO program that won't need to be swapped or manually jmp'd
    [mcu1.c, sega_databus.c]
2023-12-15 Clean up code. Add in some best try code to read/write registers Changed data type from uint8_t to uint16_t, not sure if it's even needed but trying to avoid any kind of overflows when assigning valu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
    [mcu1.c, sega_databus.c, sega_packet_interface.c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]
2023-12-15 combined detect pio program needs to be integrated into the bus program. Since we have the mux, we need to wait for the read/write pin to rise before changing back to reading control lines
2023-12-15 TODO look at the main loop and make it look like the wokwi scratch pad. FIXED databus pio. Should properly wait for cs and r/w TODO databus pio might not work correctly if we return quickly after che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
    [mcu1.c, sega_databus.c]
2023-12-15 Think the database pio code is finally sorted. It properly checks the right bits. TODO: It's not waiting for the CS lines to return to 1 before continuing after waiting for the r/w/ lines to go high.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
    [sega_databus.c]
2023-12-17 Sanity commit before rewriting pio code to use separate state machines for each pin that drops low since the monolithic program doesn't seem to be working correctly. Still unsure if this is an issue 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
    [mcu1.c]
2023-12-17 Overhauled pio code to use 4 state machines (one for each control line, cs0, cs1, rd, wr) and two tight loops to read the pio data when available to act on it. UNTESTED, but good checkin progress
    [mcu1.c, sega_databus.c]
2024-06-04 Update dreamdumper board, sanity commit before redoing all routing
    [pc64.kicad_pcb, pc64.kicad_sch]
2024-06-07 Another pass at the dreamdumper board
    [pc64.kicad_pcb, pc64.kicad_sch, picocart64_v2.kicad_pcb]
2024-06-10 Updated the dreamdumper64 stand alone board. This was submitted for test samples.
    Rewrote a bunch of dreamdrivecast code, it isn't tested but should be a lot faster if it works.
    [pc64.kicad_pcb, pc64.kicad_sch]
2024-06-11 Still debugging the control line triggering... Checking just the read and write values doesn't eliminate the issue because the CS lines can both be high for some reason.
    [mcu1.c, mcu1_pins.h]
2024-06-11 This seems to be detecting the correct number of signal transitions as captured in the logic trace. 7... but something else is wrong with maybe my parsing code to decipher the values to registers
    [mcu1.c]
2024-06-18 Moved folders to add an esp32 version of the dreamdrivecast code. This is a sanity commit before going back to a dual rp2040 approach
    [BOM-pc64.csv, Dreamdrivecast-esp32.kicad_pcb, Dreamdrivecast-esp32.kicad_sch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]
2024-06-20 Another sanity commit. Reworking the pio programs in the dreamdrivecast to handle swapping their own pinsdirs
    [mcu1.c, mcu1_pins.h, mcu2.c]
2024-06-22 Trying with a more complicated solution to flip pindirs in a single pio program on the mux rp2040. Probably need to do the same for the controller rp2040.
    [mcu1.c, mcu1_pins.h, mcu2.c]
2024-06-22 Another attempt at a mux/program that doesn't work.
    [mcu1.c, mcu2.c]
2024-06-25 Pre auto route on super test board
    [Dreamdrivecast-esp32.kicad_sch, Dreamdrivecast_v1aa.kicad_pcb, Dreamdrivecast_v1aa.kicad_sch]
2024-06-26 Routed another version of the board that includes a bunch of breakout headers. The routing is messing and it needs to have a single power net.
    [Dreamdrivecast_v1a.kicad_pcb, Dreamdrivecast_v1a.kicad_sch, Dreamdrivecast_v1aa.kicad_pcb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]
2024-06-27 Update pcb and schematic to reflect diode and removal of second mosfet connected to mcu2
    [Dreamdrivecast_v1aa.kicad_pcb, Dreamdrivecast_v1aa.kicad_sch]
2025-01-21 MIXED COMMIT: Dreamcast related: Data looks like it's flowing correctly! Dreamdrive: Modifed ctr0.s file has been included so others can drop into their pico-sdk folder. Dumper files have been update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
    [Dreamdrivecast_v1aa.kicad_pcb, bom.csv, designators.csv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]
2025-02-18 Added new Dreamdrivecast hardware design for the rp2350 (specifically the Pimoroni PGA2350) Wrote new code to support this hardware config.
    [Dreamdrivecast-rp2350.kicad_pcb, Dreamdrivecast-rp2350.kicad_sch, Dreamdrivecast-rp2350.sch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]
2025-02-25 Getting handshake to at least the req_mode command (0x11) but either doesn't like the data or the sector number data is wrong (the disc type and status) or I'm missing something else entirely.
    [Dreamdrivecast-v1b.kicad_sch]
2025-02-26 Culled a bunch of code from nulldc that I wasn't going to be using right now and converted it all to use char instead of wchar. SD card works in SPI mode only. SDIO for pins over 32 need some kind of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
2025-02-28 Renamed c files to cpp to support cpp things. Got a simulated cd_read working from the actual files on the sd card. Data seems to be correct. Need to hook up some of the lower level stuff with signal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
    [rp2350.cpp, sd_utils.cpp]
2025-03-07 Implemented an initial DMA implementation that sits in it's own loop if in DMA mode. This might become a problem if the device is expected to respond to register commands, in that case look at "IMPOR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
    [rp2350.cpp]
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2025-03-09 Added in ability to store more register reads/writes Debugging CD_READ so there are a few more print statements to determine state. Currently getting stuck sending data to DC with the DC stopping ack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
    [rp2350.cpp]
2025-03-10 Actually apply PatchRegion 0 and 6. Still debugging why the DC stops reading DMA after the first sector (and change, it reads at least a sector but stops somewhere after) Zero out state variables for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
2025-03-10 Was still running a debug build, so set back to release. Might help speed. Fixed byte counting bug when sending disc read buffer.
    [rp2350.cpp]
2025-03-11 Saw a command 70 and command 71 come through! So implemented command 71 using nulldc's array values. Removed logging of all reads and writes and only log stuff happening on core1 Trying all kinds of 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
2025-03-11 Refactored the old mai loop to be on core1 in case running our processing loop being on core1 was causing memory issues and prints not working right. This was me misunderstanding what was going on. I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
    Using another approach to command 0x71 (and 0x11) using a rom array I found in another source base.
    Suspect an electrical issue at this point. Depending on how I wiggle it while it's plugged in I may or may not get stuck on a black screen, the sega dreamcast logo, or the dashboard stuck on checking disc.
    [rp2350.cpp]
2025-03-11 Getting deeper into the rabbit hole. Having chatgpt take a stab at a pio program to handle the ata registers. Or normal code is still getting weird results from the registers access. And the logic an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
    [rp2350.cpp]
2025-03-11 Trying to do something with PIO to handle the ata stuff but it's just not working.
    [rp2350.cpp]
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2025-03-12 Got a PIO program that appears to actually work for ata register stuff... There is something else wrong since the Dreamcast seems stuck unless I power cycle quickly. So check wires and other initial 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
    [rp2350.cpp]
2025-03-12 Finally getting data flowing with new PIO ata handler. Still suspect that the data we send out on the lines is wrong or bit shifted
    [rp2350.cpp, rp2350_pins.h]
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2025-03-13 Stable? DC will send command 71 then command 0, then another command 71. It then tries to read the disc but doesn't go beyond that. Very similar to when I fail the 0x11 command challenge where it jus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
    [rp2350.cpp]
2025-03-14 Stuck with DMA stalling out after several successful data buffer fills. Debugging issue.
    [rp2350.cpp]
2025-03-14 Currently after the 5th dma finishes, the ata bus handler loop doesn't ever restart. Debugging while this isn't restarting. Changed the way some setup is handled so we could start and stop the ata ha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
    [rp2350.cpp]
2025-03-15 Trying icegdrom subcode command implementation but that doesn't seem to get me past the "loading crazy taxi (15k)" screen.
    [rp2350.cpp]
2025-03-15 Struggling to get games to load. Soul Calibur loads data but spams the TOC call. Crazy Taxi loads to "loading crazy taxi (15k) screen" and then stalls. Meanwhile it's polling the alt status register 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
    [rp2350.cpp]
2025-03-15 Changed size of gdrom read buffer to be 64 sectors. This is causing a hang(maybe a crash, need to hook up debugger) on the first "big" transfer of 717 sectors. I was using a 16 bit int for num transf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
    [rp2350.cpp]
